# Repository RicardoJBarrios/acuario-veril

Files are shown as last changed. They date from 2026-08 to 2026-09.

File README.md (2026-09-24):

# Documentación de Veril

<div align="center" style="text-align: center; padding: 20px">
  <a href="06_Logo/README.md">
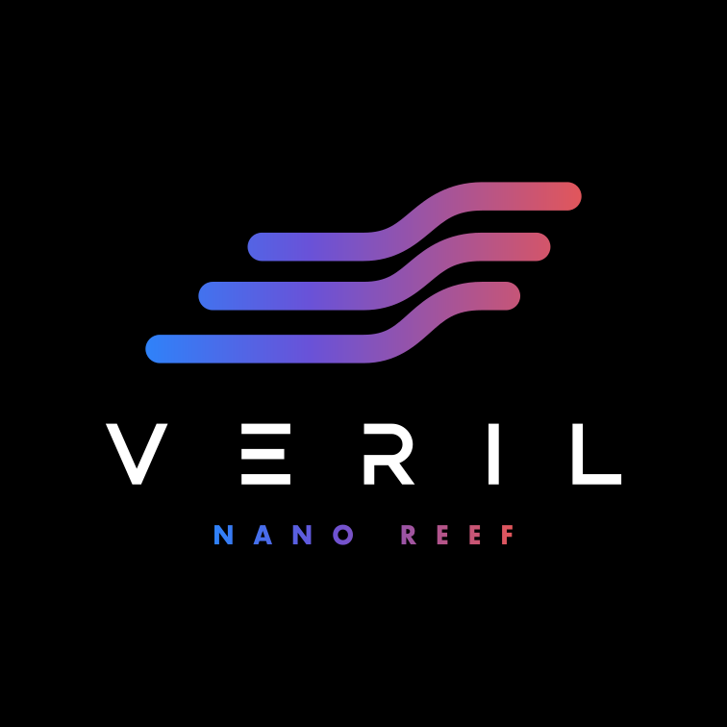
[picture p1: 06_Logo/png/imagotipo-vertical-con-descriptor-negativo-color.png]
Logotipo de Veril — Nano Reef
    
  </a>
</div>

Veril es un **nano reef de arrecife mixto de aproximadamente 75 litros**, pensado para mantener peces, corales e invertebrados en una urna AIO. Como referencia práctica, se estiman **unos 60 litros en el display** y **75 litros en el sistema completo**, incluido el compartimento técnico. Son cifras aproximadas para describir la escala del acuario, no mediciones exactas del volumen neto.

Esta documentación reúne, en un único lugar, lo que voy aprendiendo, las decisiones que tomo o me vienen impuestas y, sobre todo, los motivos que hay detrás de ellas. También recoge las actuaciones que realizo, sus consecuencias, las formas de cuidar y mantener el acuario, las dificultades que a menudo no se explican al principio y las distintas fases por las que irá pasando el sistema. En conjunto, pretende ser un registro de lo que necesito aprender para mantenerlo de forma responsable.

La hago pública por si la experiencia puede resultar útil a alguien y para poder ofrecer contexto cuando necesite pedir ayuda. Soy totalmente novato, así que lo que aparece aquí puede contener errores, interpretaciones incompletas o decisiones que no sean las más adecuadas. No pretendo ocultar los problemas ni presentar el proceso como más sencillo o más bonito de lo que es. Cualquier información interesante debería tomarse como punto de partida y contrastarse con fuentes fiables, documentación del fabricante y la situación real del acuario.

La inteligencia artificial se ha utilizado de forma extensa tanto para investigar y contrastar información como para redactar, organizar y revisar esta documentación. Todo el contenido ha pasado por una revisión editorial y de contenido humana por mi parte, y la responsabilidad de lo que se publica es mía. Esta revisión no garantiza que no haya errores, por lo que siguen siendo necesarios el criterio propio y el contraste con fuentes competentes.

Para que todo quede claramente diferenciado, la documentación separa el conocimiento general de referencia, la configuración vigente de Veril, las actuaciones que todavía están pendientes y las operaciones que ya se han ejecutado. Los prefijos numéricos orientan la lectura y cada apartado enlaza con la información más concreta cuando es necesario.

## Índice

- [Verilpedia](01_verilpedia/README.md): conocimiento general y reutilizable
- [Configuración](02_configuracion/README.md): estado vigente y decisiones de diseño de Veril
- [Pendientes](03_pendientes/README.md): actuaciones todavía no ejecutadas, incluidos ciclado, maduración y procedimientos recurrentes
- [Operaciones](04_operaciones/README.md): actuaciones ejecutadas, ordenadas por fecha y documentadas con sus resultados
- [Multimedia](05_multimedia/README.md): recursos visuales con su contexto y límites de interpretación

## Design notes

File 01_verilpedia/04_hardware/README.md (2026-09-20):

# Hardware de Veril

La urna a medida y las fichas de hardware utilizadas por Veril se documentan
en este repositorio como una recopilación personal de especificaciones,
observaciones y referencias. No es documentación oficial del fabricante ni
una validación técnica independiente. Las decisiones de selección, instalación
y aceptación pertenecen a `02_configuracion/`, a los planes y a las operaciones fechadas

## Urna

- [Urna de Veril](urna/README.md): fabricación, display y compartimento técnico

## Equipos principales

- [D-D H2Ocean Compact ATO](dd-h2ocean-compact-ato/dd-h2ocean-compact-ato.md)
- [Equipo de ósmosis inversa RO6CB](ro6cb/ro6cb.md): equipo RO con bomba de refuerzo, depósito y filtros
- [Sistema DI del RO/DI](di-ro/sistema-di.md): carcasas T33, monitor TDS, tubería y manómetro pedidos para completar el tratamiento
- [Resina DI recomendada](di-ro/resina-xepta-rodi.md): XEPTA RODI RESIN de 1000 ml, seleccionada como medio pendiente de compra o confirmación
- [Sicce Shark Skimmer 300](sicce-shark-skimmer-300/sicce-shark-skimmer-300.md)
- [Sicce Micra Plus 600](sicce-micra-plus-600/sicce-micra-plus-600.md)
- [Mantis Tourbon 60](mantis-tourbon-60/mantis-tourbon-60.md)
- [AI Prime 16HD Reef](ai-prime-16hd-reef/ai-prime-16hd-reef.md)

## Limpieza y mantenimiento manual

- [Cepillo de dientes de cerdas suaves](cepillo-dientes-cerdas-suaves/cepillo-dientes-cerdas-suaves.md)
- [Seachem Algae Scraper 31 cm](seachem-algae-scraper-31cm/seachem-algae-scraper-31cm.md)
- [TUNZE Care Magnet nano](tunze-care-magnet-nano/tunze-care-magnet-nano.md)
- [XGB-830](xgb-830/xgb-830.md)

## Sensores y monitorización

- [DanoPlus DP-414](danoplus-dp-414/danoplus-dp-414.md)
- [SONOFF S60ZBTPF](sonoff-s60zbtpf/sonoff-s60zbtpf.md)
- [SONOFF SNZB-02LD](sonoff-snzb-02ld/sonoff-snzb-02ld.md)
- [SONOFF SNZB-05P](sonoff-snzb-05p/sonoff-snzb-05p.md)
- [Excellux ZG-109TDS](zigbee-7-en-1-monitor-calidad-agua/excellux-zg-109tds.md)

## Integraciones

Las integraciones de Home Assistant y Zigbee2MQTT se encuentran junto a la ficha del equipo correspondiente. La compatibilidad y las entidades disponibles dependen del modelo y del soporte vigente de Zigbee2MQTT.

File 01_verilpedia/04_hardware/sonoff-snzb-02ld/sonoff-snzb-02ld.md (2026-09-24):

# SONOFF SNZB-02LD

## Identificación

- **Fabricante:** SONOFF
- **Modelo:** SNZB-02LD
- **Tipo:** Termómetro Zigbee con pantalla LCD y sonda externa
- **Protocolo:** Zigbee 3.0 / IEEE 802.15.4
- **Gateway previsto:** SONOFF ZBBridge-P

## Ficha normalizada

| Campo | Valor |
| --- | --- |
| `hardware_id` | `SONOFF_SNZB_02LD` |
| `category` | `aquarium_monitoring` |
| `vendor` | `SONOFF` |
| `model` | `SNZB-02LD` |
| `hardware_kind` | `physical` |
| `physical_type` | `zigbee_temperature_sensor_probe` |
| `protocol` | Zigbee 3.0 |
| `gateway` | SONOFF ZBBridge-P |
| `measurement` | Temperatura del agua |

## Función en Veril

El **SONOFF SNZB-02LD** se utiliza en Veril para el seguimiento telemétrico de la temperatura del agua mediante Zigbee y el gateway **SONOFF ZBBridge-P**. La sonda debe quedar en el agua y el cuerpo electrónico fuera de la zona húmeda. La ubicación concreta de la unidad y su estado operativo se documentan en las operaciones y en la configuración de Veril, no en esta ficha general.

La telemetría permite observar la evolución de la temperatura. Las tendencias y los avisos automáticos solo se utilizarán cuando la cadencia y la señal se hayan validado en el sistema; la automatización térmica de Veril continúa en revisión. La lectura tampoco sustituye la comprobación independiente del sensor.

## Especificaciones

| Campo | Dato |
| --- | --- |
| Fabricante | SONOFF |
| Modelo | SNZB-02LD |
| Tipo | Termómetro Zigbee con pantalla LCD y sonda externa |
| Comunicación | Zigbee 3.0 / IEEE 802.15.4 |
| Gateway previsto | SONOFF ZBBridge-P |
| Alimentación | 3 V, pila CR2477 |
| Pantalla | LCD de aproximadamente 5,6 cm |
| Dimensiones del cuerpo | 62,8 × 58,5 × 21,8 mm |
| Material del cuerpo | PC + ABS |
| Peso neto publicado | 86,2 g, con cables |
| Longitud de la sonda | 1,5 m |
| Tolerancia de temperatura declarada | ±0,5 °C |
| Protección del cuerpo | IP65 |
| Temperatura de funcionamiento del cuerpo | −10–60 °C según el PDF oficial V1.0 |
| Humedad de funcionamiento del cuerpo | 0–100 % HR según el PDF oficial V1.0 |
| Temperatura de funcionamiento de la sonda | −40–115 °C según el PDF oficial V1.0 |
| Altura máxima de instalación declarada | <2000 m |

## Instalación

- Fijar únicamente la sonda en una zona representativa del agua
- Mantener el cuerpo y la tapa de la pila fuera del acuario y protegidos de salpicaduras directas
- Evitar que la sonda quede contra un calentador, una bomba, la iluminación o una pared sometida a radiación directa
- Comprobar que la longitud de 1,5 m permite colocar el cuerpo en una zona seca sin tensar el cable
- Verificar la lectura frente a un termómetro independiente antes de usar avisos o automatizaciones

IP65 no significa que el cuerpo pueda sumergirse. La protección está pensada para salpicaduras y chorros de baja presión; no se expondrá el módulo a inmersión, condensación persistente ni chorros de agua salada.

## Datos disponibles en Zigbee2MQTT

Zigbee2MQTT expone para este modelo:

- Batería restante en porcentaje
- Temperatura de la sonda en °C
- Unidad mostrada en pantalla: `celsius` o `fahrenheit`
- Calibración de temperatura mediante una corrección entre −50 y +50 °C
- Actualización OTA

La calibración y la precisión configurable aparecen como opciones del dispositivo. La integración completa con Home Assistant está en [Home Assistant y Zigbee2MQTT](home-assistant-zigbee2mqtt.md).

El manual permite emparejar el sensor con un SONOFF ZBBridge-P. El alta se realiza desde eWeLink: se mantiene pulsado el botón durante cinco segundos, el indicador entra en modo de emparejamiento durante aproximadamente 180 segundos y se selecciona el gateway Zigbee.

El gateway, la cobertura real y la publicación de la temperatura se comprobarán en la ubicación definitiva. Una lectura disponible en la aplicación no demuestra por sí sola que la sonda esté bien colocada ni que su valor sea correcto.

## Limitaciones

- El dispositivo mide temperatura; no mide salinidad, pH, alcalinidad, nutrientes ni nivel de agua
- La tolerancia declarada no sustituye una comparación con un instrumento independiente
- El cuerpo IP65 no debe sumergirse
- La pila CR2477 y la disponibilidad Zigbee deben vigilarse como parte del mantenimiento

## Fuentes

- [Manual local del SNZB-02LD, versión 1.0 en inglés](sonoff-snzb-02ld-manual-en-v1-0.pdf)
- [Página oficial del SONOFF SNZB-02LD](https://sonoff.tech/en-eu/products/sonoff-snzb-02ld-ip65-zigbee-lcd-smart-thermometer-probe-version)
- [Manual oficial del SNZB-02LD](https://support.sonoff.tech/snzb-02ld-usermanual/)
- [Descarga directa del PDF oficial](https://cdn.shopify.com/s/files/1/0742/9963/8001/files/User_Manual_SNZB-02LD_EN_V1.0.pdf?v=1749029821)

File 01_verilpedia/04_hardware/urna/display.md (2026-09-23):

# Display de la urna

## Dimensiones y función

El display ocupa la zona izquierda de la urna. Su medida interior observada en planta es de **594 × 308 mm** y la altura exterior de la urna es de **400 mm**. Es el espacio destinado al aquascape, el sustrato y los habitantes. El compartimento técnico derecho concentra el equipo auxiliar.

La disposición longitudinal permite desarrollar el aquascape desde la zona técnica hacia el extremo libre del acuario, manteniendo una lectura principal desde el puesto de trabajo.

## Volumen operativo estimado del display

Como referencia de diseño, con 2 cm de arena y 2 cm de margen libre, la columna de agua sería de 350 mm sobre una base interior de 594 × 308 mm: **64,03 L brutos** antes de descontar la roca. La operación del 23 de septiembre de 2026 permite inferir un desplazamiento de roca de **aproximadamente 2,339 L**, usando el descenso confirmado de 12 mm tanto en display como en Entrada. El cálculo da **aproximadamente 61,69 L** para el display en ese escenario, que se redondea a **unos 60 L** como referencia práctica para dosificaciones aproximadas. No es una medición directa de litros ni el volumen total del sistema; el detalle y sus límites constan en la [operación de pesaje y desplazamiento](../../../04_operaciones/2026/09/2026-09-23-pesaje-y-desplazamiento-del-hardscape.md).

Este dato corresponde solo al display. La convención nominal vigente de Veril es **60 L para el display** y **75 L para el sistema completo**, incluidas las cámaras Entrada, Skimmer y Retorno. Se usarán como valores por defecto para simplificar cálculos y dosificaciones; son aproximaciones adoptadas, no mediciones exactas.

## Organización

- Mantener el display como zona biológica y visible
- Situar la AI Prime 16HD Reef ligeramente desplazada hacia la derecha para obtener la mejor cobertura posible del hardscape dentro de los **594 mm** útiles
- Dejar espacio alrededor y detrás de la roca para la circulación
- Mantener despejados el peine, el rebosadero y los accesos de mantenimiento
- Conservar pasos para retirar detrito y limpiar los cristales
- Evitar apoyar equipo auxiliar sobre el sustrato o la roca

La composición de la roca, el sustrato, los espacios negativos y las rutas hidráulicas se desarrolla en la [implementación de Veril](../../../02_configuracion/README.md), con sus fichas [espacial](../../../02_configuracion/01_dimensiones/02_espacial.md), [hidráulica](../../../02_configuracion/01_dimensiones/03_hidraulica.md) y [biología](../../../02_configuracion/03_biologia/README.md).

## Circulación y mantenimiento

El flujo debe alcanzar las zonas inferiores, los refugios y la parte posterior de la estructura sin levantar el sustrato ni crear áreas de acumulación. La roca y los habitantes deben permitir la limpieza del cristal, el acceso al peine y la retirada manual del detrito.

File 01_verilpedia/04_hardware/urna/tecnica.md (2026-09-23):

# Técnica de la urna

## Configuración AIO

El compartimento técnico lateral recibe el agua del display, aloja el equipo y devuelve el agua mediante una bomba de retorno. Está integrado en la urna y no es un sump inferior externo.

No se instalará filtración mecánica. El uso de un medio biológico adicional se decidirá en la documentación de biología y ciclado.

## Recorrido hidráulico

La zona técnica tiene tres cámaras interiores. La cámara **Entrada** queda documentada con unas dimensiones nominales de **139 × 86 × 390 mm** (ancho × fondo × altura interior). Las otras dos cámaras se expresan aquí en planta como **Skimmer** (**139 × 134 mm**) y **Retorno** (**139 × 77 mm**):

```text
Display
→ Entrada: Entrada circular y paso a la zona técnica
→ Paso inferior de aproximadamente 50 mm a Skimmer
→ Skimmer: Skimmer y calentador
→ Paso superior de aproximadamente 50 mm a Retorno
→ Retorno: Bomba, ATO y sensores
→ Retorno al display
```

La cámara **Entrada** concentra la entrada y el acceso a la rejilla. Su altura interior nominal es de **390 mm**, calculada como **400 mm de altura exterior menos 10 mm del fondo**; los **340 mm** de los separadores internos no son la altura de esta cámara, sino la altura de una pieza que deja un paso inferior aproximado de 50 mm hacia Skimmer. La entrada a esta cámara se realiza mediante una perforación de **50 mm de diámetro**, situada a **17 mm del borde superior** y a **30 mm de la pared trasera**. La cámara **Skimmer** aloja el skimmer y el calentador. En la observación del 23 de septiembre de 2026, su nivel quedó 50 mm por debajo del borde, frente a 37 mm en display/Entrada; esa cota describe la observación y no se adopta aquí como nivel universal para todos los regímenes. La cámara **Retorno** mantiene la bomba de retorno, el sensor del ATO y los sensores de temperatura.

## Equipo técnico

- [Sicce Shark SKIMMER 300](../sicce-shark-skimmer-300/sicce-shark-skimmer-300.md): Skimmer de la cámara Skimmer
- [Sicce Micra Plus 600](../sicce-micra-plus-600/sicce-micra-plus-600.md): Bomba de retorno
- [Mantis Tourbon 60](../mantis-tourbon-60/mantis-tourbon-60.md): Bomba de movimiento del display
- [D-D H2Ocean Compact ATO](../dd-h2ocean-compact-ato/dd-h2ocean-compact-ato.md): Reposición automática de la cámara Retorno
- [Barril GRAF de 15 l](../dd-h2ocean-compact-ato/graf-barril-agroalimentario-15l.md): Depósito de agua RO/DI para el ATO

El compartimento conserva acceso para retirar y mantener el skimmer, el calentador, las bombas, el sensor del ATO, los sensores de temperatura y la rejilla de entrada.

## Niveles de agua

- Nivel mínimo de Retorno: Límite inferior para evitar que la bomba aspire aire
- Nivel operativo: Altura normal con el ATO y el equipo funcionando
- Nivel máximo seguro: Altura compatible con el agua que retorna durante un corte eléctrico

El ATO repone únicamente agua **RO/DI** en la cámara Retorno. El sistema debe quedar dispuesto para evitar el sifonado y permitir la limpieza del sensor.

## Comprobaciones de montaje

- Paso de agua entre display y zona técnica sin desbordamientos
- Nivel estable en la cámara del skimmer
- Acceso de mantenimiento en las tres cámaras
- Funcionamiento silencioso del rebosadero superior
- Circulación sin microburbujas persistentes hacia el display
- Margen de agua suficiente en la cámara Retorno
- Comportamiento del sistema durante el llenado, la circulación y un corte eléctrico

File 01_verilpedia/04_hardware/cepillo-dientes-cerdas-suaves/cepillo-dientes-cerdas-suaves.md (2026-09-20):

# Cepillo de dientes de cerdas suaves

## Identificación

| Campo | Dato |
| --- | --- |
| Tipo | Cepillo manual de cerdas suaves |
| Marca, modelo y material | No identificados |
| Estado de la ficha | Identidad comercial pendiente de confirmar |

## Alcance

Esta entrada conserva la existencia de un útil de limpieza identificado solo
por su tipo. Sin fabricante, modelo, material ni evidencia de compatibilidad,
no se le atribuyen seguridad química, resistencia al agua salada ni un uso
concreto dentro de Veril.

La eventual utilización, el contacto con agua o roca y el resultado de una
limpieza pertenecen a una operación fechada, no a esta ficha general.

## Pendientes

- Confirmar fabricante, modelo y materiales si se conservan envase o etiqueta.
- Registrar el uso concreto y las condiciones de limpieza antes de emplearlo en Veril.

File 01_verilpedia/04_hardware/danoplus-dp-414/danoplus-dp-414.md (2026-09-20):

# DanoPlus DP-414

## Identificación y función en Veril

El **DanoPlus DP-414** es el sensor previsto para medir el PPFD bajo el agua y construir el mapa de exposición lumínica de Veril. No forma parte del régimen de iluminación ni determina por sí mismo qué organismos son compatibles con una zona.

La unidad de medida principal será el PPFD registrado en µmol fotones m⁻² s⁻¹ dentro del intervalo PAR. Los valores se relacionarán con la posición, profundidad, espectro, fotoperiodo y estado de la luminaria.

## Estado de la decisión

**Adquirido:** El usuario confirma disponer del DanoPlus DP-414. Se utilizará como instrumento propio para el mapa de PPFD de Veril, una vez comprobado que la unidad corresponde al modelo documentado y el sensor no presenta daños.

**Previsto:** El sensor se empleará sumergido, unido a la varilla telescópica, con una orientación y un protocolo de posición constantes.

**Pendiente:** Deben registrarse la unidad recibida, el número de serie o lote, la revisión identificable, el estado del sensor y, si resulta posible, una comparación puntual con un medidor subacuático de referencia.

## Especificaciones documentadas

| Campo | Valor documentado |
| --- | --- |
| Fabricante | DanoPlus |
| Modelo comercial | DP-414 |
| Identificación alternativa documentada | KIB0414 en el manual consultado |
| Tipo | Medidor cuántico de PPFD para medición subacuática |
| Sensor | Sensor cuántico declarado IP68 |
| Intervalo espectral declarado | 400–700 nm ±10 nm |
| Rango de medición declarado | 0–4000 µmol fotones m⁻² s⁻¹ |
| Resolución indicada | 0,1 hasta 999 y 1 por encima de 1000, según la documentación consultada |
| Registro interno | Hasta 100 valores |
| Cable | Aproximadamente 79 pulgadas, según el fabricante |
| Varilla | Telescópica sólida de aproximadamente 37 pulgadas, según el fabricante |
| Alimentación | 2 pilas AAA en el manual oficial en español; algunas copias secundarias indican 3 |
| Unidad principal | No sumergible |

Las especificaciones anteriores son declaraciones del fabricante o de su manual. No equivalen a una validación independiente de exactitud, linealidad, respuesta espectral o repetibilidad de la unidad de Veril.

El manual oficial en español se conserva en [DanoPlus DP-414: manual de uso](danoplus-dp-414-manual-es.pdf). La página del fabricante también identifica el equipo como **414_E**, mientras que otras copias del manual utilizan **KIB0414** o **CD50**. Al recibir la unidad se registrará la identificación impresa en el producto y se conservarán esas variantes como referencias del mismo conjunto documental, sin asumir que todas las revisiones sean idénticas.

## Funciones del manual

El manual documenta las siguientes operaciones:

- Medición en tiempo real
- Retención de la lectura mediante `HOLD`
- Registro manual de hasta 100 valores
- Consulta y borrado de los registros almacenados
- Calibración del punto cero cubriendo completamente el sensor
- Restablecimiento de fábrica
- Apagado automático tras aproximadamente tres minutos sin operación
- Ajuste de la inclinación del sensor hasta aproximadamente 180°

La calibración descrita es una calibración del cero en oscuridad. No es una calibración de exactitud frente a una fuente patrón ni proporciona por sí sola un factor de corrección para mediciones subacuáticas.

## Limitaciones de medición

El sensor no se considerará una referencia metrológica absoluta sin una comparación documentada con un medidor subacuático de referencia. Las comparativas disponibles de medidores económicos muestran factores de corrección variables según la unidad, la revisión del sensor, el espectro y la posición.

No se aplicará automáticamente un multiplicador publicado para otra unidad. Si se dispone de una comparación con un Apogee MQ-510 u otro instrumento de referencia, el factor obtenido se registrará junto al número de unidad, las condiciones y el espectro utilizado. Hasta entonces, los valores podrán utilizarse como referencia espacial y comparativa interna, pero no como cifras absolutas con precisión de laboratorio.

La orientación del sensor debe permanecer constante. Una inclinación distinta, una sombra de la varilla, burbujas, suciedad o una posición diferente sobre una superficie rugosa pueden alterar la lectura. El sensor no se dejará instalado permanentemente en el acuario.

## Reseñas y pruebas independientes

La evidencia independiente disponible es limitada y no constituye una certificación de exactitud. Las experiencias siguientes se conservarán como observaciones de usuarios o pruebas concretas, no como valores universales para todas las unidades:

- Serious Reefs comparó el DP-414 y el VBR-Aqua con un Apogee MQ-510 y resumió que ambos podían utilizarse como opciones económicas después de aplicar una corrección aproximada, aunque prefirió el DanoPlus y señaló dificultades en el violeta y el índigo
- En Reef2Reef, usuarios que compararon unidades DanoPlus con Apogee comunicaron factores de aproximadamente 1,2–1,3 en algunas unidades
- En el mismo debate se afirmó que algunas cajas recientes identificadas con un punto verde se acercaban a Apogee sin corrección, pero otro usuario con una unidad equivalente siguió observando la necesidad de un factor de 1,2–1,3
- Una prueba publicada en Reddit comparó aproximadamente 230 PPFD del DanoPlus con 355 PPFD del Apogee en el mismo punto, lo que muestra que una unidad concreta puede presentar un sesgo importante
- Las experiencias generales de usuarios valoran el precio, la varilla y la utilidad para evitar ajustar la luz a ciegas, pero no permiten establecer una exactitud común a todas las revisiones

Estas diferencias no demuestran necesariamente que el instrumento sea inútil. Sí demuestran que la cifra mostrada no debe tratarse como intercambiable con la de un Apogee sin validar la unidad concreta.

## Puntos débiles conocidos

### Exactitud y corrección no universal

El fabricante publica una repetibilidad de ±1 µmol fotones m⁻² s⁻¹, pero la repetibilidad declarada no equivale a exactitud frente a un patrón. Las comparativas independientes muestran factores distintos según la unidad, el sensor, el espectro y la posición.

No se utilizará un factor genérico como 1,25×, 1,35× o 1,7× sin justificarlo con una comparación de la unidad concreta. Para Veril, la prioridad será que el mapa sea repetible; si se obtiene una referencia externa, el factor se registrará con sus condiciones y no se extrapolará automáticamente a otra unidad.

### Respuesta espectral limitada

El intervalo declarado es 400–700 nm con una tolerancia de aproximadamente ±10 nm. Esto permite medir PPFD dentro del intervalo PAR convencional, pero no convierte el equipo en un espectrómetro ni describe la distribución espectral de la AI Prime 16HD Reef.

La respuesta en el extremo violeta, especialmente cerca de 400–420 nm, puede ser una fuente de diferencia frente a otros sensores. No se interpretará el valor de PPFD como una medida de PUR ni como una descripción de qué bandas utiliza un organismo.

### Orientación y geometría

El sensor puede inclinarse para adaptarse a la posición de medida, pero esa articulación introduce una variable que debe fijarse. La orientación, la sombra de la varilla, el reflejo del cristal, las burbujas y la rugosidad de la superficie pueden modificar la lectura.

El mapa de Veril utilizará una orientación definida y repetible. Si una zona exige medir sobre una superficie inclinada, se registrará esa condición en lugar de comparar el valor directamente con una superficie horizontal sin contexto.

### Memoria y registro manual

La memoria de 100 lecturas no conserva por sí sola coordenadas, profundidad, hora, programación de la luminaria ni condiciones hidráulicas. La memoria se utilizará como apoyo, pero el mapa definitivo se registrará fuera del instrumento con la plantilla de medición de Veril.

El apagado automático tras aproximadamente tres minutos puede interrumpir una sesión lenta. Se comprobará el estado del instrumento durante el muestreo y se evitará interpretar una lectura perdida como un cambio lumínico.

### Protección y mantenimiento

El IP68 se declara para el sensor, no para la unidad principal, el cable completo ni el conector. El manual no establece en la ficha consultada una profundidad máxima ni una duración máxima de inmersión. Por ello, el sensor se utilizará durante la medición, se enjuagará después y no se dejará instalado permanentemente.

La superficie óptica es sensible a suciedad y arañazos. Un sensor contaminado, un conector con humedad o un cable deteriorado pueden producir lecturas inestables y no deben resolverse aplicando un factor de corrección.

### Documentación del fabricante

El manual oficial es breve y no aporta un certificado de calibración individual, una curva de respuesta espectral detallada, incertidumbre expandida, profundidad máxima de ensayo ni resultados de comparación frente a un estándar subacuático. La declaración de repetibilidad debe conservarse como especificación del fabricante, no como prueba independiente de exactitud.

## Uso previsto en el mapa de Veril

El mapa se realizará con la AI Prime 16HD Reef en la configuración que se quiera documentar y con la geometría operativa del aquascape instalada. Cada punto deberá conservar:

- Fecha y hora
- Altura de la luminaria sobre el agua
- Estado de los canales y programación activa
- Profundidad y posición horizontal del sensor
- Orientación del sensor y método de sujeción
- Estado de la superficie del agua y de la circulación
- Valor mostrado por el DP-414
- Factor de corrección utilizado, si existe
- Relación del punto con roca, sustrato, islas, terrazas, sombras o espacios previstos

El mapa se utilizará para clasificar zonas de exposición y relacionarlas con las necesidades documentadas de los organismos. No se asignarán corales únicamente por el valor de un punto ni se interpretará el mapa como una medición del espectro completo.

## Procedimiento de aceptación

1. Comprobar que el modelo y el sensor recibidos corresponden al DP-414 documentado
2. Revisar carcasa, cable, conector, sensor, varilla y compartimento de pilas
3. Confirmar que la unidad principal permanece fuera del agua
4. Encender el instrumento y verificar que la lectura responde a cambios de iluminación
5. Colocar el sensor plano o en la orientación definida para el protocolo
6. Comprobar que la varilla no proyecta sombra sobre el sensor ni modifica su posición
7. Realizar lecturas repetidas en un punto de control para evaluar la repetibilidad local
8. Registrar la medición de referencia, si se dispone de otro instrumento
9. Documentar cualquier factor de corrección antes de construir el mapa definitivo
10. Guardar el mapa junto con la configuración de la luminaria y la geometría del aquascape

El DP-414 se considerará adecuado para el mapa cuando produzca lecturas repetibles bajo la misma configuración, pueda colocarse en las zonas relevantes y sus limitaciones estén registradas. La exactitud absoluta no se dará por demostrada solo por la resolución mostrada o por la declaración IP68.

## Mantenimiento y seguridad

Después de cada sesión se enjuagará el sensor con agua dulce adecuada, se inspeccionará el cable y se dejará secar antes de guardarlo. No se sumergirá la unidad principal ni se utilizará el instrumento si el cable, el conector o la carcasa del sensor presentan daños.

La varilla se manejará sin golpear el cristal, la roca, el sustrato ni los corales. Las mediciones se realizarán con la alimentación y los equipos en la configuración definida para el mapa; cualquier parada de bombas o cambio temporal deberá registrarse porque modifica las condiciones de exposición y la estabilidad del sensor.

## Fuentes

- [DanoPlus: DP-414](https://www.danoplus.com/products/dp-414/)
- [DanoPlus: categoría de medidores de luz](https://www.danoplus.com/category/light-lux-meters/)
- [DanoPlus: manuales y software del modelo 414](https://www.cd50.net/414/)
- [Manual local en español del DP-414](danoplus-dp-414-manual-es.pdf)
- [Manual del DanoPlus KIB0414](https://manuals.plus/asin/B0D3LVT1MR)
- [Comparativa de DanoPlus, VBR-Aqua y Apogee publicada por Serious Reefs](https://www.patreon.com/SeriousReefs/posts/mq510-575-par-vs-151737140)
- [Comparativa de usuarios entre DanoPlus y Apogee](https://www.reef2reef.com/threads/vbr-aqua-par-meter-for-aquarium-r-g-b-par-seperately/page-5)
- [Prueba comparativa de DanoPlus y Apogee en ReefTank](https://www.reddit.com/r/ReefTank/comments/1p2v9of/would_this_par_meter_do_the_job_thoughts/)

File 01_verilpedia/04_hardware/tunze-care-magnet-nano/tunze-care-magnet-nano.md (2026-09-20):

# TUNZE Care Magnet nano

## Identificación declarada

| Campo | Dato |
| --- | --- |
| Marca | TUNZE |
| Producto | Care Magnet nano |
| Referencia | 0220.010 |
| Tipo | Limpiacristales magnético |

## Especificaciones declaradas

TUNZE declara la variante nano para cristal de **6 a 10 mm**, con **45 mm** de
ancho y **78 mm** de longitud. Incluye una cuchilla plástica de recambio de
45 mm y tapas de colores. El fabricante indica que las superficies de contacto
y el cristal deben estar libres de arena o polvo antes de cada uso; las
partículas adheridas pueden rayar el cristal.

La compatibilidad dimensional con una urna concreta y el comportamiento de la
unidad disponible en Veril no quedan demostrados por esta ficha.

## Fuentes

- [TUNZE: Care Magnet nano 0220.010](https://tunze.com/Care-Magnet-nano/0220.010)

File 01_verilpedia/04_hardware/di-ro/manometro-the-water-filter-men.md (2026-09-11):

# Manómetro The Water Filter Men

## Identificación declarada

| Campo | Valor documentado |
| --- | --- |
| Marca | The Water Filter Men |
| Tipo | Indicador de presión para sistemas RO y filtros de agua |
| Conexión roscada declarada | 1/4 NPT |
| Conexión hidráulica anunciada | Racor para tubo de 1/4 pulgadas |
| Material declarado | Acero inoxidable |
| Peso declarado | 60 g |
| Cantidad | Una unidad |
| ASIN | B00BZTFI5M |

La página del fabricante/comercializador confirma que el conjunto está destinado a comprobar la presión de entrada o la presión de un sistema de ósmosis inversa y que incluye los accesorios para tubo de 1/4 pulgadas. La escala y la precisión del ejemplar concreto no se han confirmado en una ficha técnica independiente.

## Aplicación prevista

Se prevé utilizarlo para observar la presión en la alimentación del RO o en el tramo que se defina durante el montaje. La ubicación final no queda fijada por la ficha del producto: debe permitir una lectura representativa, evitar esfuerzos sobre el tubo y no introducir una restricción no prevista.

La escala, el rango útil, la precisión y la estanqueidad de la combinación de manómetro y racor se comprobarán físicamente. Una lectura del manómetro no sustituye la verificación del límite de presión indicado para el RO6CB.

## Fuente

- [Manómetro The Water Filter Men en Amazon](https://www.amazon.es/dp/B00BZTFI5M)
- [Ficha del manómetro con accesorios en The Water Filter Men](https://thewaterfiltermen.co.uk/products/reverse-osmosis-pressure-gauge-with-fittings)

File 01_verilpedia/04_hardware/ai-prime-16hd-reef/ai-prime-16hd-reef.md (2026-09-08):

# AI Prime™ 16HD Reef

## Descripción

La **AI Prime™ 16HD Reef** será la luminaria principal del display de Veril. Es una luminaria LED compacta para arrecife, con control inalámbrico, siete grupos de color regulables y un canal lunar independiente. Su formato concentra los emisores en una zona circular central y utiliza lentes TIR con una salida difusa para mezclar los colores antes de que la luz llegue al acuario.

La Prime combina una banda azul-violeta dominante con aportes más pequeños de blanco, verde, amarillo, naranja y rojo. Esta combinación permite trabajar con una apariencia azul de arrecife, conservar una parte amplia del espectro visible y ajustar el aspecto final mediante la aplicación. El sistema HD redistribuye la potencia disponible entre los canales utilizados, de modo que el porcentaje mostrado por la aplicación sirve para programar la luz, pero no equivale directamente a vatios, lúmenes o PAR.

## Ficha técnica

| Campo | Dato |
| --- | --- |
| Producto | AI Prime™ 16HD Reef |
| Fabricante | AquaIllumination® |
| Dimensiones | 12,4 × 12,4 × 3,4 cm |
| Peso | 0,43 kg |
| Consumo publicado | 55 W en la descripción y 59 W a plena potencia en la tabla técnica |
| Alimentación | 100–240 V CA, 50–60 Hz |
| Longitud del cable | 6,1 m |
| Óptica | Lentes TIR, con eficiencia óptica superior al 90 % según AquaIllumination |
| Control | Mobius, myAI y Neptune Fusion mediante Apex y módulo MXM |
| Protección declarada de la fuente | UL, CE y RoHS |

La luminaria incorpora **cuatro LED Cool White, cuatro Blue, cuatro Royal Blue, un Photo Red, un Green, un Violet, un UV y un Moonlight**. El número de emisores no indica por sí solo la proporción de luz de cada color: la corriente, la eficiencia, el control térmico y la redistribución HD determinan la salida real.

## Distribución física y espectro

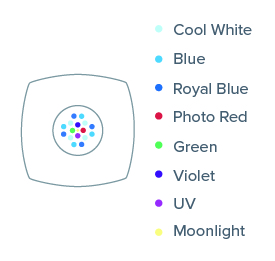
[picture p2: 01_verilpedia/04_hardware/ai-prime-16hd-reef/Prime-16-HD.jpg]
Distribución física de los LED de la AI Prime 16HD


*Distribución física publicada por AquaIllumination.*

Los emisores están intercalados en un conjunto circular compacto. Los blancos aportan una base visible más amplia; los azules y royal blue forman la parte dominante del aspecto de arrecife; violeta y UV extienden la salida hacia longitudes de onda cortas; verde y rojo completan la mezcla visible; y el Moonlight funciona como canal lunar independiente. La proximidad de los emisores, las lentes TIR y la superficie de salida difusa favorecen que los colores lleguen mezclados a la zona iluminada.

La distribución compacta también concentra el máximo de luz en el eje central cuando la luminaria está baja. Subirla abre la huella y suaviza la diferencia entre centro y bordes, aunque reduce el PAR máximo y puede aumentar la luz que sale de la zona útil. La posición de un LED en el dibujo no permite calcular su potencia ni el PAR que llegará a un coral.

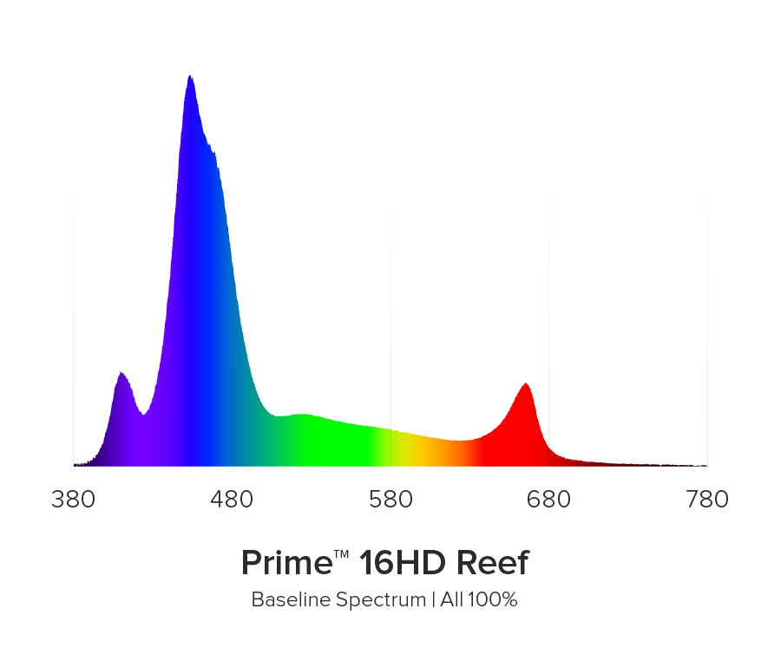
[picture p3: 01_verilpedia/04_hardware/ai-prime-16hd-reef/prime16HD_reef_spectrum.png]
Mapa de espectro base de la AI Prime 16HD Reef al 100 %


*Espectro base al 100 % publicado por AquaIllumination.*

El mapa cubre aproximadamente de 380 a 780 nm y muestra una salida principalmente azul-violeta. Se aprecia una contribución corta alrededor de 400–410 nm, un máximo principal en torno a 440–450 nm, una cola azul amplia hasta aproximadamente 490 nm, una contribución menor y extendida entre 500 y 630 nm y un pico rojo alrededor de 660 nm. El eje vertical no está graduado: representa intensidad relativa en el gráfico, no irradiancia absoluta, potencia óptica ni PAR.

La forma del gráfico explica el aspecto azul de la luminaria y su capacidad para resaltar fluorescencia, pero no determina por sí sola la intensidad adecuada para un coral ni la uniformidad sobre el acuario. Esas condiciones dependen de la programación, la altura, la profundidad, la orientación, la roca y la óptica.

## Control espectral

Mobius y myAI permiten construir una programación con puntos de control independientes, rampas de amanecer y anochecer, intensidad general, preajustes y escenas temporales. Los canales pueden cambiar durante el día y la intensidad general puede modificar toda la programación sin alterar necesariamente la relación entre colores.

El funcionamiento HD permite tomar capacidad de los canales reducidos y transferirla a los canales que se están utilizando. Por eso un 100 % es un nivel de control y no una unidad de potencia universal; del mismo modo, un valor superior al 100 % en un canal no significa que ese canal consuma ese porcentaje de la potencia total. Cambiar un canal altera el color y puede alterar también el PAR total.

La aplicación ofrece preajustes Signature Series, aclimatación, efecto lunar, Feed Mode, Live Demo, Lights On y Schedule. Feed Mode permite crear una escena temporal con espectro y duración propios; Live Demo sirve para probar canales; Lights On lleva la luminaria al 100 % y Schedule devuelve el horario normal. La aclimatación reduce la intensidad inicial y la aumenta durante el periodo elegido. El ejemplo de 50 % durante 30 días es una referencia de la aplicación, no el ajuste establecido para Veril.

El efecto lunar actúa sobre los puntos del canal Moonlight siguiendo la fase lunar y reduce la intensidad fuera de la luna llena. Se mantendrá desactivado al principio. Si se utiliza, se comprobarán sus horas y su efecto sobre el fotoperiodo.

## Aplicación, conexión y mantenimiento

La puesta en marcha se realiza desde un teléfono o tableta mediante Bluetooth Low Energy. En el alta pueden ser necesarios Bluetooth, ubicación y permisos de Bluetooth para myAI. La Prime debe estar encendida y dentro del alcance; si no aparece, conviene desconectar temporalmente otros dispositivos Bluetooth. En Android, la guía de soporte incluye borrar la caché del sistema Bluetooth y reiniciar el dispositivo. Las funciones descritas para myAI se comprobarán en Mobius si la unidad se entrega con esa plataforma.

La aplicación permite guardar y recuperar horarios, importar preajustes y verificar los ajustes desde `Settings > Troubleshooting > Verify Settings`. También permite volver a sincronizar la hora desde `Settings > Time > Set to Current Time` y regresar a `Schedule`. La Prime se controlará desde la aplicación, mientras que Home Assistant solo supervisará y cortará la alimentación mediante el SONOFF.

Las actualizaciones de firmware se hacen con la luminaria encendida y pueden tardar 15 minutos o más. Durante ellas no se debe cerrar la aplicación ni cortar la alimentación. En una Prime 16HD nueva, el indicador rojo y blanco intermitente señala que hay una actualización pendiente. El botón de restablecimiento está en la parte inferior: con la alimentación desconectada se mantiene pulsado mientras se vuelve a conectar hasta que parpadea en rojo; el parpadeo azul y verde confirma el restablecimiento.

La rejilla del ventilador debe mantenerse limpia. `Fan Shutdown` puede dejar el ventilador funcionando solo cuando lo necesita para mantener la temperatura o hacerlo funcionar continuamente. El estado utilizado se registrará junto con el ruido y la temperatura. La lente de repuesto identificada por AquaIllumination es la **119-00001**; su marca debe quedar hacia el lado del botón y todas las lentes deben quedar completamente asentadas y alineadas después de cualquier sustitución.

## Cobertura y PAR

AquaIllumination anuncia una extensión de **61 × 61 cm** y un pico de **100 µmol·m⁻²·s⁻¹ a 61 cm de profundidad**. En las pruebas de cobertura de una superficie de 61 × 61 cm, una Prime situada a 15,2 cm sobre el agua produjo una media de 107 PAR, con 462 PAR en el centro y 21 PAR en el borde. A 25,4 cm, el centro bajó a 232 PAR y el borde subió a 47 PAR. A 33,0 cm, la media fue de 94 PAR, con 156 PAR en el centro y 63 PAR en el borde.

La misma serie de pruebas encontró que una Prime a 20,3 cm cubría un cubo de 30,5 cm para LPS con el 94 % de los puntos entre 75 y 150 PAR. En un cubo de 45,7 cm, una Prime a 25,4 cm dejó el 83 % de 75 puntos en ese intervalo para LPS, pero no alcanzó el objetivo de SPS para el 70 % del área. En una superficie de 61 cm, una Prime a 33,0 cm situó el 70 % de 108 puntos en el intervalo de LPS y tejidos blandos.

Como referencias de diseño, dos Primes sobre un acuario de 91,4 cm produjeron el 81 % de 150 puntos entre 75 y 150 PAR para LPS, mientras que tres unidades produjeron el 73 % de los puntos entre 200 y 350 PAR para SPS. En un acuario de 121,9 × 61 cm, tres Primes alcanzaron el 92 % de 198 puntos en el intervalo LPS; ocho unidades, distribuidas en dos filas, alcanzaron el 78 % del área en el intervalo SPS. Estos resultados muestran que la cobertura depende tanto de la altura y el espaciamiento como de la potencia.

El display de Veril mide aproximadamente **60 × 32 × 40 cm**. El hardscape se desplazará hacia la derecha, por lo que la Prime quedará ligeramente desplazada hacia la derecha y se colocará en la posición que proporcione la mejor cobertura posible del hardscape, sin tomar como referencia obligatoria el centro geométrico de la urna. El extremo izquierdo y las zonas sombreadas recibirán una comprobación específica. La altura real provisional será de **250 mm entre la cara inferior de la luminaria y el agua**, hasta completar la comprobación de PAR y distribución.

La altura se comprobará físicamente después de instalar el kit, el cable y el shade, y se registrará junto con el mapa de PAR y la distribución observada. BRS utilizó 25,4 cm en una superficie de 45,7 cm y encontró una distribución más abierta que a menor altura; su referencia de 33,0 cm para una superficie de 61 × 61 cm sirve únicamente como contexto de la prueba.

## Montaje en Veril

La luminaria se colgará con el kit de AI desde un mueble **BESTÅ de IKEA** de aproximadamente **20 cm de fondo**. El punto de suspensión estará a **70 cm sobre la mesa** y la cara inferior de la luminaria quedará a **250 mm sobre el agua como referencia de montaje**. El anclaje se colocará hacia la derecha para alinear la zona de mayor cobertura con el hardscape. La altura real se comprobará físicamente después de instalar el conjunto.

Se instalará un **shade fabricado mediante impresión 3D** en el frente de la luminaria para evitar el reflejo directo y el deslumbramiento del usuario. Los laterales y la parte trasera quedarán libres para conservar la ventilación, la dispersión lateral de la luz y el acceso al cableado y a los ajustes. El shade no deberá tocar el ventilador, la carcasa caliente, la rótula ni los cables, ni proyectar sombras sobre la zona iluminada.

Antes de dar por terminado el montaje se comprobarán la capacidad real del panel del BESTÅ, la fijación del anclaje, la nivelación a 250 mm, la alineación lateral, la estabilidad durante el mantenimiento y la ausencia de tensión en el cable de alimentación. La luminaria no es impermeable y el adaptador deberá mantenerse separado del agua.

## Integración y puesta en marcha

La alimentación se realizará mediante un [SONOFF S60ZBTPF](../sonoff-s60zbtpf/sonoff-iplug-s60zbtpf.md) independiente. Home Assistant y Zigbee2MQTT supervisarán la alimentación y el consumo; Mobius o myAI controlarán la intensidad, el espectro y el horario.

La instalación se aceptará después de:

1. Registrar la unidad, el adaptador, el cable, el número de serie y el kit recibido
2. Verificar el anclaje al BESTÅ y la capacidad de carga del panel
3. Colgar inicialmente la luminaria a 250 mm sobre el agua, alinearla con el hardscape desplazado hacia la derecha y registrar la altura instalada
4. Instalar el shade frontal dejando abiertos los laterales y la parte trasera
5. Configurar la aplicación, conceder los permisos necesarios y actualizar el firmware si se solicita
6. Registrar la programación inicial, el estado de Fan Shutdown y el consumo eléctrico
7. Comprobar temperatura, ventilador, ruido, salpicaduras, condensación y posibles reflejos
8. Medir PAR en la cumbre, las terrazas, las microislas, el sustrato, los bordes y las zonas sombreadas
9. Comprobar y registrar la altura real, y ajustar orientación, shade o intensidad a partir del mapa obtenido
10. Guardar la configuración aceptada y relacionarla con la ubicación de los organismos

## Fuentes

- [AquaIllumination: Prime 16HD Reef](https://www.aquaillumination.com/products/prime)
- [AquaIllumination: Distribución física de los LED](https://www.aquaillumination.com/wp-content/uploads/2019/10/Prime-16-HD.jpg)
- [AquaIllumination: Mapa de espectro](https://www.aquaillumination.com/wp-content/uploads/2019/10/prime16HD_reef_spectrum.png)
- [AquaIllumination: Manual de Prime 16](https://support.aquaillumination.com/hc/en-us/articles/4402388563479-Prime-16-Product-Manual)
- [AquaIllumination: Prime Hanging Kit](https://shop.aquaillumination.com/products/prime-hanging-kit)
- [AquaIllumination: Montaje del kit para colgar](https://support.aquaillumination.com/hc/en-us/articles/13231337537303-Prime-Hanging-Kit-Assembly)
- [AquaIllumination: FAQ de AI Light 16/32/64](https://support.aquaillumination.com/hc/en-us/sections/360008131313-AI-Light-16-32-64-FAQ)
- [AquaIllumination: Instalación de lentes de Prime 16HD](https://support.aquaillumination.com/hc/en-us/articles/40562411067927-AI-Lens-Prime-16HD-32HD-64HD-Installation)
- [AquaIllumination: Limpieza y ventilación](https://support.aquaillumination.com/hc/en-us/articles/1500004217901-Prime-Fan-Cleaning-Instructions)
- [AquaIllumination: Actualización del firmware](https://support.aquaillumination.com/hc/en-us/articles/360046798273-Updating-AI-Light-Firmware)
- [AquaIllumination: Conexión y diagnóstico](https://support.aquaillumination.com/hc/en-us/articles/360039936254-How-do-I-connect-to-my-new-16-32-64-HD)
- [AquaIllumination: Feed Mode](https://support.aquaillumination.com/hc/en-us/articles/360046558853-AI-Lights-Configuring-Feed-Mode)
- [AquaIllumination: Programación de una AI Light nueva](https://support.aquaillumination.com/hc/en-us/articles/360011977713-How-should-I-program-my-new-AI-Light)
- [Bulk Reef Supply: Prueba de la Prime HD](https://www.bulkreefsupply.com/content/post/brstv-investigates-aqua-illumination-prime-hd)
- [Bulk Reef Supply: Vídeo de prueba de la Prime 16](https://www.youtube.com/watch?v=QH2nsgrxoRI)
- [ReefCalcs: Tabla PAR de la AI Prime 16HD](https://reefcalcs.com/fixtures/ai-prime-16-hd/)
- [Bay Area Reefers: Mediciones con AI Prime 16HD](https://bareefers.org/forum/threads/frag-tank-sunlight-par-meter-usage.31140/)
- [Reef2Reef: Medición PAR de una AI Prime 16HD](https://www.reef2reef.com/threads/ai-prime-16hd-par.931206/)
- [Reef2Reef: Ajustes y mediciones de la Prime 16HD](https://www.reef2reef.com/threads/ai-prime-16hd-settings-review.1142488/)
- [Reef2Reef: Incidencias comunicadas sobre lentes](https://www.reef2reef.com/threads/2x-ai-prime-16hd-lenses-melting-on-both.1037948/)
- [Canal oficial de AquaIllumination](https://www.youtube.com/@AquaIlluminationUS)
- [Ficha del SONOFF S60ZBTPF](../sonoff-s60zbtpf/sonoff-iplug-s60zbtpf.md)

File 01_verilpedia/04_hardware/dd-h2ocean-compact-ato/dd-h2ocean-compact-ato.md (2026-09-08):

# D-D H2Ocean Compact ATO

- **Fabricante:** D-D The Aquarium Solution
- **Modelo:** H2Ocean Compact ATO
- **Tipo:** sistema automático de reposición de agua
- **Entorno:** acuarios de agua dulce o marina

## Ficha normalizada

| Campo | Valor |
| --- | --- |
| `hardware_id` | `DD_H2Ocean_Compact_ATO` |
| `category` | `aquarium` |
| `vendor` | `D-D The Aquarium Solution` |
| `model` | `H2Ocean Compact ATO` |
| `hardware_kind` | `physical` |
| `physical_type` | `automatic_top_off` |
| `sensor` | doble sensor óptico |
| `actuator` | bomba CC incluida |
| `connectivity` | ninguna |
| `software` | control embebido no actualizable por el usuario |
| `mounting` | soporte magnético |

## Componentes incluidos

Según el manual oficial, la caja contiene:

- Controlador Compact ATO con doble sensor óptico
- Adaptador de alimentación universal
- Soporte universal para el tubo, compatible con acuarios con o sin marco de hasta 12,7 mm
- Bomba de reposición CC sin escobillas
- Rompe-sifón, integrado en el tubo de reposición
- Tubo de 200 cm

El depósito de reposición no forma parte del ATO y se documenta por separado en [Barril agroalimentario GRAF de 15 l](graf-barril-agroalimentario-15l.md).

## Funcionamiento

El controlador detecta el descenso del nivel mediante dos sensores ópticos y activa la bomba del depósito de reposición. El diseño no contiene flotadores móviles en el sensor y añade una lógica de seguridad y una alarma visual.

En un acuario marino debe reponer agua dulce, preferiblemente RO/DI: la sal no se evapora.

## Especificaciones

| Parámetro | Valor declarado |
| --- | --- |
| Entrada de la fuente | 100–240 V CA, 50/60 Hz |
| Bomba | corriente continua |
| Caudal máximo | 280 L/h |
| Altura máxima de impulsión | 2,5 m |
| Grosor máximo de cristal | 12,5 mm |
| Tubo incluido | 2 m |
| Diámetro del tubo | 9 mm exterior; 6,5 mm interior |
| Tamaño de acuario recomendado | más de 50 L |
| Sensores | dos ópticos |
| Garantía limitada del manual | 1 año, con instalación y uso correctos |

El caudal máximo y la altura máxima de impulsión no se alcanzan simultáneamente. La altura, la longitud y el recorrido del tubo reducen el caudal real.

La bomba es una bomba de corriente continua sin escobillas, con una altura máxima declarada de 250 cm y un caudal máximo de 280 l/h. Esos valores son límites de la bomba y no un caudal garantizado en la instalación de Veril.

## Instalación confirmada para Veril

Veril utilizará el H2Ocean Compact ATO con un [Barril agroalimentario GRAF de 15 l](graf-barril-agroalimentario-15l.md) reservado para agua RO/DI.

### Altura de impulsión prevista

El depósito estará en el suelo y la urna se apoyará sobre una mesa con:

- Patas de 71 cm
- Tapa de 32 mm
- Urna de 40 cm de altura

La superficie de apoyo de la urna quedará aproximadamente a **74,2 cm sobre el suelo** y el borde superior de la urna aproximadamente a **114,2 cm**. La salida del tubo del ATO no tiene que situarse en el borde superior: debe quedar por encima del nivel máximo del agua del sump y sin sumergirse durante el funcionamiento normal.

Tomando como referencia conservadora una bomba situada cerca del fondo del barril y una salida próxima a la parte alta del compartimento técnico, la elevación vertical prevista será aproximadamente de **1,0–1,2 m**. La altura real dependerá de la posición final de la bomba, del nivel de salida y del recorrido del tubo.

La bomba declara una altura máxima de impulsión de **2,5 m**. Por tanto, la instalación prevista queda con un margen vertical aproximado de **1,3–1,5 m** frente a ese límite. No se aprecia un problema de altura para llevar el agua desde el barril colocado en el suelo hasta la cámara de retorno.

El tubo incluido mide 2 m. La ruta definitiva debe mantenerse dentro de esa longitud, evitando bucles innecesarios, estrangulamientos y curvas cerradas. La altura máxima declarada y el caudal máximo de 280 l/h no se alcanzan simultáneamente, por lo que el caudal real debe comprobarse una vez instalado.

**Conclusión de compatibilidad:** la subida desde el barril situado en el suelo hasta la cámara de retorno es compatible con la capacidad declarada del H2Ocean Compact ATO. La elevación estimada de 1,0–1,2 m queda claramente por debajo de los 2,5 m máximos de la bomba y el recorrido previsto cabe, en principio, dentro de los 2 m de tubo incluido.

- El sensor óptico se instalará en la cámara de retorno, donde la evaporación modifica realmente el nivel
- La bomba se colocará dentro de un depósito alimentario cerrado y reservado para RO/DI
- La salida del tubo quedará por encima del nivel máximo del depósito y del agua cuando sea necesario para impedir el sifonado
- El rompe-sifón se colocará por encima del nivel máximo del agua del depósito
- El extremo de salida del tubo no quedará sumergido en el agua de la cámara de retorno durante el funcionamiento normal
- El cableado y la tubería quedarán sujetos, sin pinzamientos y con bucle antigoteo
- El depósito no contendrá agua salada, suplementos ni productos de mantenimiento

El sensor se instalará a la altura normal de trabajo, haciendo que el nivel alcance el sensor óptico inferior. Debe quedar alejado de microburbujas, turbulencias directas, salpicaduras y zonas donde pueda acumularse sal o biofilm.

## Pruebas obligatorias

1. Activación al bajar el nivel
2. Parada en el nivel establecido
3. Respuesta del segundo sensor o de la protección disponible
4. Ausencia de sifón con la bomba apagada
5. Comportamiento al vaciarse el depósito
6. Comportamiento tras un corte eléctrico

## Criterios de aceptación

- Nivel estable sin ciclos excesivamente cortos
- El caudal no remueve sedimento ni salpica los sensores
- Autonomía suficiente sin ocultar una fuga
- Sensor accesible para limpieza e inspección
- La bomba no puede vaciar el depósito hacia la urna por sifón
- La cámara de retorno conserva un nivel seguro cuando el depósito se agota

La doble óptica reduce el riesgo, pero no constituye por sí sola una protección independiente contra inundaciones o reposición excesiva. El primer rellenado debe vigilarse porque el límite temporal de seguridad se establece a partir de esa referencia inicial.

### Smart Level

El controlador registra la duración del primer rellenado y activa una alarma visual si un rellenado posterior dura seis veces más. Por ejemplo, si el primer ciclo dura 10 segundos, la alarma puede activarse al superar 60 segundos.

Esta función puede detectar, entre otras situaciones:

- Interferencia de microburbujas
- Sobrellenado o lectura anómala del sensor
- Fallo del sensor o del controlador
- Depósito vacío, para evitar que la bomba funcione en seco

El primer rellenado no dispone de ese límite temporal aprendido. Tras resolver una alerta, el manual indica apagar y volver a encender el equipo para reiniciarlo.

En acuarios muy pequeños, el sensor superior puede activarse brevemente después de cada reposición; el manual lo considera un comportamiento normal si no aparece una alerta roja.

## Interfaz e indicadores

| Indicador | Significado |
| --- | --- |
| LED azul y rojo alternos | Inicialización |
| LED azul fijo | Alimentación conectada y equipo preparado |
| LED azul intermitente | Reposición o bombeo |
| LED azul que parpadea rápidamente durante poco tiempo | El sensor de seguridad detecta un cambio de nivel |
| LED rojo intermitente | Alerta Smart Level; revisar microburbujas, sobrellenado o depósito vacío |

## Mantenimiento

- Limpiar periódicamente sensores, bomba y tubo
- Retirar sal, carbonatos, algas y biofilm
- Verificar que la bomba no funcione en seco
- Repetir las pruebas de seguridad después de limpiar o cambiar la disposición
- Inspeccionar cableado y conectores antes de volver a energizar

## Integración con supervisión

El ATO funcionará de forma autónoma con sus protecciones nativas. La supervisión externa podrá observar consumo, disponibilidad y anomalías si la integración lo permite, pero no sustituirá las protecciones del equipo ni la comprobación visual.

No se aplicarán ventanas horarias ni cortes automáticos hasta comprobar con el equipo real que conserva sus protecciones, reinicia de forma fiable y no produce oscilaciones de nivel o salinidad.

La integración prevista mediante un [SONOFF S60ZBTPF y Zigbee2MQTT](home-assistant-zigbee2mqtt.md) puede añadir límites de tiempo, ventanas de habilitación, registro y corte de emergencia. No mide el nivel de agua y no sustituye Smart Level.

El fabricante ofrece como accesorio opcional un Smart AC Switch. No forma parte del equipo documentado para Veril y no se considerará necesario para la instalación base.

## Fuente interna

- [Manual oficial H2Ocean Compact ATO](h2ocean-compact-ato-manual.pdf)

## Fuente externa

- [D-D: H2Ocean Compact ATO](https://www.theaquariumsolution.com/product/8111/451)

## Estado en Veril

**Confirmado:** equipo seleccionado para la reposición automática de Veril.

**Pendiente de ejecución:** ubicación definitiva del depósito, recorrido y fijación del tubo, marcas de nivel mínimo y máximo, autonomía real y validación completa después de un corte eléctrico.

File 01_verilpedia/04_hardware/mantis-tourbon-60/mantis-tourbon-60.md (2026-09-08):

# Mantis Tourbon 60 Wave Maker

## Identificación

| Parámetro | Valor documentado |
| --- | --- |
| Fabricante | Mantis Aquarium Technology Co., Ltd. |
| Modelo | Tourbon 60 |
| Tipo | Bomba de movimiento y generadora de olas |
| Caudal máximo declarado | 4.000 l/h |
| Consumo declarado | 3–15 W en la tabla oficial; varias tiendas publican 8 W para la Tourbon 60 |
| Alimentación | DC 24 V según la tabla oficial |
| Montaje | Imán exterior, con orientación regulable |
| Grosor máximo de cristal | 10 mm |
| Uso declarado | Agua dulce y agua marina |
| Control | Controlador cableado incluido |
| Comunicación de red | La web oficial enlaza una aplicación; no está confirmado que la Tourbon 60 de Veril sea compatible con ella |

La Tourbon 60 es la bomba de circulación seleccionada para el display de Veril. El caudal máximo es una cifra de catálogo, no una medición de caudal útil dentro de la urna. La roca, el nivel, la orientación, la altura, el sustrato y los corales modificarán el movimiento real.

El manual público de la serie disponible describe la instalación, los modos, las protecciones y el mantenimiento, pero su tabla de parámetros muestra explícitamente las Tourbon 100 y 200 y no incluye una fila independiente para la Tourbon 60. La página oficial sí publica una tabla específica para esta variante: 24 V CC, 4.000 l/h, 3–15 W, cristal de hasta 10 mm y acuarios de 40–60 cm. Varias fichas comerciales publican **8 W** como consumo máximo, por lo que el consumo exacto se comprobará en la etiqueta y la fuente de la unidad recibida.

## Función en Veril

La bomba generará circulación interna alrededor de la roca, el corredor trasero, las microislas y la superficie. No sustituye al retorno: el retorno mantiene la renovación entre display y sump, mientras la Tourbon 60 distribuye el movimiento dentro del display y reduce zonas de acumulación.

El máximo nominal equivale aproximadamente a **42 veces** el volumen geométrico de 96 L. Ese múltiplo no será un objetivo de funcionamiento. La intensidad se establecerá por el comportamiento del agua y de los organismos, no por una relación fija entre litros por hora y litros de urna.

## Construcción y montaje

La bomba utiliza un conjunto compacto con rotor, eje, jaulas de flujo, casquillos y elementos elastoméricos. El eje se documenta como cerámico en las fichas técnicas disponibles. El soporte magnético permite fijarla al vidrio y orientar el cuerpo con varios ángulos.

La bomba trabaja mediante un adaptador externo de baja tensión y un controlador cableado. El cable de la bomba utiliza un conector de tres pines con el controlador; el adaptador se conecta después al controlador. No se conectará la bomba directamente a la red eléctrica.

## Modos de funcionamiento

El controlador incorpora cinco modos principales:

- **Flujo constante:** mantiene una salida continua con la intensidad seleccionada. Es el modo inicial más fácil de interpretar.
- **Flujo de onda:** aumenta y reduce progresivamente la velocidad. El tiempo de subida y bajada se regula mediante el control de frecuencia.
- **Modo pulsante:** alterna un pico de flujo con una reducción rápida hacia la potencia mínima. Puede producir una oscilación más marcada y desplazar el sustrato si se ajusta demasiado alto.
- **Modo aleatorio:** cambia de forma variable la velocidad y la intensidad hasta el máximo configurado. Es difícil comparar su efecto sin registrar observaciones durante un periodo suficiente.
- **Modo ciclo:** alterna automáticamente los cuatro modos anteriores y cambia al siguiente después de diez ciclos.

La frecuencia y la intensidad se regulan desde el controlador. El enlace de dos bombas, si se utiliza con otra unidad compatible, permite designar una unidad maestra y otra subordinada para generar ondas alternas. Veril utiliza una sola Tourbon 60, por lo que esa función no forma parte de la configuración.

## Funciones auxiliares del controlador

- **Pausa de alimentación:** una pulsación prolongada detiene la bomba durante aproximadamente 20 minutos y después reanuda el modo seleccionado.
- **Modo nocturno:** un sensor de luz reduce el caudal cuando detecta poca iluminación ambiental. No conoce la hora ni el estado biológico del acuario.
- **Bloqueo:** impide cambiar accidentalmente la configuración desde los botones.

El controlador y el manual suministrado no documentan una interfaz de red, un protocolo, una API ni un procedimiento de emparejamiento con una aplicación. La web oficial sí incluye un enlace general de descarga de una aplicación, pero no identifica en esa página la compatibilidad concreta con la Tourbon 60 ni sustituye la verificación de la unidad recibida. El enlace entre dos controladores es una función local del equipo y no una integración de red.

## Protecciones documentadas

La electrónica incluye varias respuestas de protección:

- **Escasez de agua:** reduce la bomba a la velocidad más baja.
- **Rotor bloqueado o sucio:** detiene o limita el funcionamiento y vuelve a comprobar el estado aproximadamente cada 30 segundos hasta que se resuelva el bloqueo.
- **Tensión fuera de rango:** entra en protección si detecta una tensión inferior a 9 V o superior a 38 V en el circuito indicado por el manual.
- **Pérdida de fase:** detiene el motor si detecta una anomalía en los grupos de bobinas.
- **Controlador sin bomba conectada:** puede dejar el indicador de bloqueo parpadeando; para recuperar el funcionamiento se desconecta la alimentación, se conecta correctamente la bomba y se vuelve a alimentar el conjunto.

Estas protecciones no sustituyen la inspección. Una bomba parcialmente obstruida puede seguir moviendo agua sin aportar el caudal previsto.

## Integración física en Veril

La bomba se instalará en:

- lateral izquierdo del display;
- tercio superior, aproximadamente 8–12 cm bajo la superficie como punto de partida;
- orientación inicial hacia la derecha, ligeramente hacia atrás y hacia arriba;
- posición que cree renovación del corredor trasero sin golpear directamente el sustrato, el cristal opuesto o un coral.

La posición final se ajustará después de instalar la roca, el sustrato y el nivel operativo real. El cable y el imán deben permanecer accesibles para inspección, retirada y limpieza.

La colocación se aceptará cuando:

- la superficie presente movimiento continuo sin salpicaduras;
- el corredor trasero reciba renovación sin crear un chorro aislado;
- no haya zonas de detrito que permanezcan inmóviles de forma persistente;
- el sustrato no se desplace continuamente ni forme cráteres;
- las microislas no vibren ni reciban un flujo que desplace sus organismos;
- el flujo no retraiga de forma sostenida a los corales ni los golpee directamente;
- la bomba no produzca vibración anómala, ruido creciente o calentamiento excesivo.

## Puesta en marcha

1. Limpiar y secar el vidrio en la zona de montaje.
2. Conectar el cable de tres pines de la bomba al controlador antes de alimentar el sistema.
3. Conectar el adaptador de baja tensión al controlador y después a la red.
4. Montar las dos partes del imán lentamente y de forma desplazada, evitando atrapamientos de los dedos y golpes sobre el vidrio.
5. Comenzar en flujo constante y con la intensidad mínima que permita observar el recorrido del agua.
6. Comprobar la superficie, el corredor trasero, el sustrato y las zonas protegidas.
7. Registrar cada cambio de intensidad, modo u orientación por separado.

Los modos de pulsos, onda, aleatorio y ciclo se probarán solo después de validar la orientación básica. No se cambiarán a la vez el modo, la posición y la geometría de la roca, porque se perdería la capacidad de interpretar el efecto.

## Mantenimiento

Antes de manipular la bomba se desconectará el adaptador de la red. Para la limpieza:

1. Retirar el imán exterior con cuidado y separar las dos partes.
2. Extraer las tapas de los impulsores siguiendo el sentido indicado por el manual.
3. Retirar jaulas de flujo, casquillos, gomas y rotor.
4. Eliminar algas, carbonato, sustrato y detrito sin dañar el eje cerámico ni las superficies de apoyo.
5. Comprobar que el rotor gira libremente y que las gomas permanecen asentadas.
6. Montar de nuevo el conjunto y probarlo en agua antes de devolverlo a su posición definitiva.

Se revisará la bomba si aparece pérdida progresiva de caudal, ruido, vibración, reinicios del controlador, funcionamiento intermitente o aumento de temperatura. La limpieza no se hará únicamente por calendario: también se activará por cambios observables de rendimiento.

## Integración eléctrica y supervisión

El controlador no dispone de una integración de red documentada. El adaptador se conectará a una unidad independiente del [SONOFF S60ZBTPF](../sonoff-s60zbtpf/sonoff-iplug-s60zbtpf.md) para permitir un corte general y una supervisión eléctrica, pero el enchufe no sustituirá al controlador ni se utilizará para crear las ondas o las pausas de alimentación.

La integración detallada con Home Assistant y el [SONOFF S60ZBTPF](../sonoff-s60zbtpf/sonoff-iplug-s60zbtpf.md), incluyendo calibración de consumo, alarmas y pruebas de recuperación, está documentada en la [ficha de integración de la Tourbon 60](home-assistant-zigbee2mqtt.md). El consumo eléctrico no demuestra que el rotor esté entregando el caudal correcto: la supervisión debe complementarse con observación del flujo y mantenimiento del conjunto.

## Experiencia de uso y evidencia disponible

La evidencia práctica específica de la Tourbon 60 es muy escasa. No se ha localizado una prueba independiente que publique caudal medido, consumo real, nivel de ruido, temperatura o duración del conjunto bajo condiciones controladas.

La página oficial de Mantis muestra una única reseña de usuario, fechada el 25 de julio de 2024, que indica que el control mediante la aplicación es fácil y cómodo. No identifica de forma visible la variante utilizada, no aporta mediciones ni describe el acuario. La reseña se conserva como indicio de experiencia de control, pero no valida la compatibilidad de la Tourbon 60 de Veril con la aplicación ni permite valorar su rendimiento.

Coral Center y AQ-Arium publican para la Tourbon 60 un caudal máximo de 4.000 l/h, 8 W, 24 V CC y compatibilidad con cristal de hasta 10 mm. Coral Center añade unas dimensiones de 67 mm de longitud, 55 mm de diámetro y 10,3 mm para el imán exterior. AQ-Arium especifica además el contenido comercial del conjunto: adaptador, motor húmedo, controlador, imán y manual. Son fichas comerciales, no ensayos independientes.

El vídeo de AquariumWorldEsp muestra un desembalaje, instalación y prueba de una **Tourbon 200**, no de la Tourbon 60. Permite observar el controlador, la selección de modos, la regulación por porcentaje y una percepción subjetiva de un flujo intenso con la unidad ajustada al 40 %. El autor no mide caudal, ruido ni consumo, y sus observaciones no se trasladan a la Tourbon 60. Se conserva como evidencia práctica de la interfaz y del comportamiento general de la familia, no como validación del modelo seleccionado.

Existe una experiencia publicada con una **Tourbon 100**, distinta de la Tourbon 60, instalada en un acuario marino y ajustada al 60 % de su caudal nominal. No aporta mediciones de ruido, caudal real ni durabilidad y no se utilizará para transferir resultados a la Tourbon 60.

Las páginas comerciales que describen la Tourbon 60 repiten principalmente las especificaciones del producto. Las afirmaciones de funcionamiento silencioso, durabilidad y bajo calentamiento se consideran características declaradas, no resultados independientes.

Por tanto, la aceptación de la unidad de Veril se basará en una prueba propia:

- registrar consumo si se dispone de medidor;
- observar ruido y vibración en silencio ambiental;
- comprobar el movimiento con partículas inocuas o alimento antes de introducir animales;
- comprobar la respuesta de el sustrato y de las microislas;
- registrar el comportamiento del controlador en modo constante y en un modo variable;
- repetir la observación después de la primera limpieza.

## Limitaciones

- El caudal de 4.000 l/h es nominal y no equivale al caudal real dentro del aquascape.
- No se dispone de un mapa hidráulico ni de una medición de distribución para la urna de Veril.
- El sensor nocturno depende de la iluminación ambiental y puede activarse de forma no prevista si cambia la luz de la habitación.
- Las protecciones electrónicas no detectan todas las pérdidas de rendimiento causadas por suciedad o desgaste.
- La compatibilidad del imán debe comprobarse sobre el espesor y el cristal reales de la urna.
- La bomba no debe funcionar fuera del agua para probarla.
- La ausencia de una prueba independiente de ruido y durabilidad impide convertir “ultrasilenciosa” o “duradera” en criterios garantizados.

## Fuentes

- [Mantis Aquarium: Tourbon Wave Pump](https://mantisaquarium.com/wave-pump/)
- [Mantis Aquarium: ficha oficial de Tourbon Wave Pump](https://mantisaquarium.com/wave-pump/tourbon-wave-pump/)
- [Mantis Aquarium: página general del fabricante](https://mantisaquarium.com/)
- [Manual de la serie Mantis Tourbon](mantis-tourbon-manual.pdf)
- [Manual público de la serie Tourbon](https://www.aquaticline.es/wp-content/uploads/sites/3/2021/07/Instrucciones-Nuevas-Tourbon-Series-1.pdf)
- [Tropical Nature: Tourbon 60, 4.000 l/h](https://tropicalnature.it/en/product-detail/6317/pumps-movement/mantis-tourbon-60-4000l-h)
- [A.G.P.: Tourbon 60 / 100 / 200](https://www.agpsrl.eu/apparecchiature-tecniche/pompe-di-movimento/tourbon-60-100-200.html)
- [Aquaristic Online: Mantis Tourbon Wavemaker 60](https://www.aquaristiconline.com.au/collections/mantis/products/mantis-tourbon-wavemaker-60)
- [DaniReef: experiencia con una Tourbon 100 en un acuario marino](https://forum.danireef.com/viewtopic.php?f=34&t=34195) — variante distinta, no transferible a la Tourbon 60
- [Coral Center: Mantis Tourbon Pump](https://coralcenter.es/producto/equipamiento/bombas/bombas-de-movimiento/mantis-tourbon-pump/)
- [AQ-Arium: Tourbon Wave Pump Mantis, nueva versión](https://www.aq-arium.com/aqmarine/acuario-marino/tourbon-wave-pump-mantis-nueva-version/)
- [AquariumWorldEsp: unboxing y prueba de una Tourbon 200](https://www.youtube.com/watch?v=IjscbS5rOH8) — variante distinta, no transferible a la Tourbon 60
- [Hidráulica de Veril](../../../02_configuracion/01_dimensiones/03_hidraulica.md)

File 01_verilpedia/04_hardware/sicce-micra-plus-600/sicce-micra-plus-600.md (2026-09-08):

# Sicce Micra Plus 600

## Identificación y función en Veril

La **Sicce Micra Plus 600** será la bomba de retorno del compartimento técnico. Elevará el agua desde la cámara de retorno al display; no será la bomba principal de movimiento del acuario. La circulación interna la realizará la Mantis Tourbon 60.

La bomba de retorno de Veril ya dispone de su tubo instalado. Además, se ha adquirido un tubo Eheim auxiliar de **3 m, 16/22 mm**, referencia **4005843**, destinado a llenados, trasvases y conexiones temporales entre recipientes o cámaras. No se asigna a la salida de la Micra Plus ni se utilizará para sustituir su tubo de retorno sin una decisión específica.

La alimentación y la supervisión mediante una unidad independiente del [SONOFF S60ZBTPF](../sonoff-s60zbtpf/sonoff-iplug-s60zbtpf.md) están documentadas en la [ficha de integración con Home Assistant](home-assistant-zigbee2mqtt.md).

## Especificaciones documentadas

| Parámetro | Valor documentado |
| --- | --- |
| Fabricante | Sicce S.r.l. |
| Modelo | Micra Plus |
| Variante de referencia para Veril | 220–240 V / 50 Hz |
| Tipo | Bomba sumergible compacta de recirculación |
| Motor | Síncrono accionado por imán permanente |
| Caudal máximo declarado | 600 l/h |
| Altura máxima declarada | 0,85 m en el manual; 0,8 m en algunos catálogos de Sicce |
| Potencia declarada | 6,5 W |
| Corriente declarada | 0,035 A |
| Regulación | Regulador mecánico de caudal; distribuidores describen cinco posiciones |
| Filtración incluida | Esponja pequeña intercambiable en la entrada |
| Entrada de agua | Rejilla de aspiración, incluida la aspiración inferior según la documentación de la gama |
| Salida documentada | Tubo flexible de 12 × 16 mm mediante adaptador o tubo rígido de 13 mm |
| Dimensiones publicadas | Aproximadamente 72 × 60 × 61 mm; comprobar el espacio con la unidad recibida |
| Cable | 1,5 m en la variante habitual; existen referencias con cable de 10 m |
| Uso declarado | Agua dulce, agua marina, acuarios, pequeños circuitos de recirculación y fuentes interiores |
| Temperatura máxima documentada | 35 °C |

La ficha del manual local indica **0,85 m**, mientras que el catálogo de Sicce redondea la misma prestación a **0,8 m**. Se conservarán ambas cifras como una diferencia de presentación, no como dos capacidades distintas. El caudal de 600 l/h y la altura máxima son valores de catálogo en condiciones de ensayo y no el caudal que llegará al display con la altura, tubería, codos, regulador, esponja y suciedad de Veril.

## Construcción y accesorios

La bomba utiliza un motor síncrono de imán permanente y un rotor desmontable. El conjunto compacto está pensado para trabajar sumergido. La Micra Plus incorpora:

- Regulación mecánica del flujo
- Esponja de entrada intercambiable
- Rejilla de aspiración que permite trabajar con un nivel de agua bajo, siempre que no quede por debajo de las entradas
- Ventosas y elementos de apoyo para reducir el movimiento de la bomba
- Adaptador para la conexión documentada de tubo
- Cámara frontal o *prechamber* compatible con la conexión de salida

La esponja puede proteger el rotor frente a partículas, pero también puede convertirse en una restricción hidráulica cuando acumula detrito, algas o carbonato. No se interpretará la presencia de la esponja como una garantía de filtración mecánica suficiente para el sistema.

## Rendimiento hidráulico

El manual incluye una curva de características para la variante de 230 V / 50 Hz. La curva muestra aproximadamente el caudal máximo con altura nula y una reducción progresiva al aumentar la altura. No publica una tabla completa de caudal para cada altura ni representa la instalación concreta de Veril.

Como referencia de catálogo:

- **600 l/h:** Caudal máximo declarado a altura nula
- **0,5 m:** El gráfico del fabricante sitúa el caudal aproximadamente en torno a 500 l/h, como lectura orientativa de la curva
- **0,85 m:** Altura máxima declarada, no objetivo de operación

La siguiente representación Mermaid digitaliza de forma aproximada la curva visible en el manual para la variante **Micra Plus 230 V / 50 Hz**. Los puntos se han leído visualmente de la gráfica y no constituyen una tabla de mediciones. No sustituye una medición con la tubería, la altura y la regulación de Veril.

```mermaid
xychart-beta
    title "Sicce Micra Plus 230 V / 50 Hz: curva caudal-altura"
    x-axis "Caudal (l/h)" [0, 50, 100, 150, 200, 250, 300, 350, 400, 450, 500, 550, 600]
    y-axis "Altura (cm)" 0 --> 90
    line [85, 83, 80, 77, 72, 66, 60, 53, 45, 37, 28, 15, 0]
```

No se utilizará el cálculo de **600 l/h ÷ 96 l = 6,25 renovaciones por hora** para dimensionar el retorno. Ese resultado solo combina el caudal nominal a altura nula con el volumen geométrico y no representa el funcionamiento hidráulico de Veril.

## Punto de trabajo hidráulico real

El caudal de retorno se calculará en el punto de intersección entre la curva de la bomba y la curva de resistencia de la instalación. La curva del fabricante representa la bomba sin la tubería ni el rebosadero de Veril.

La resistencia real se determinará con:

- Diferencia vertical entre el nivel operativo de la cámara de retorno y la cota efectiva de descarga
- Nivel del agua del display cuando el rebosadero está funcionando
- Profundidad de la salida si descarga bajo la superficie del display
- Longitud interior y diámetro real de la tubería
- Adaptadores, codos, cambios de sección, válvulas y uniones
- Regulación mecánica de la Micra Plus
- Pérdida de carga de la esponja y de la rejilla cuando estén sucias
- Pérdida de carga del paso de entrada y del rebosadero de la urna
- Caudal de retorno que el rebosadero puede admitir sin elevar el nivel de forma insegura

Para una estimación inicial se representará la instalación mediante una curva de sistema del tipo:

```text
H_sistema(Q) = H_estática + H_pérdidas(Q)
```

Las pérdidas aumentan con el caudal y dependen de la velocidad del agua y de la geometría del circuito. El caudal operativo será el valor `Q` en el que `H_bomba(Q)` y `H_sistema(Q)` sean iguales. Si la salida queda sumergida, la cota y la presión de descarga se incorporarán a la condición hidráulica en lugar de tratar la altura de la bomba como una cifra aislada.

La altura de salida, el diámetro interior definitivo, la longitud, los accesorios y los niveles mínimo y operativo todavía deben medirse en la urna montada. Hasta disponer de esas medidas, no se publicará una cifra de renovaciones por hora como resultado del diseño.

La Micra Plus no sustituye a la bomba de movimiento. Un retorno demasiado alto puede aumentar el ruido del rebosadero, vaciar la cámara de retorno o elevar el nivel de forma insegura, mientras que uno demasiado bajo puede limitar el intercambio entre display y compartimento técnico.

## Instalación prevista

La bomba se instalará completamente sumergida en la cámara de retorno, sobre una superficie estable y con la aspiración libre. El manual indica mantener aproximadamente 2 cm de agua y no dejar que el nivel quede por debajo de las rejillas de aspiración.

La instalación deberá cumplir:

- Mantener la bomba sumergida durante el funcionamiento
- Evitar que aspire sustrato, caracoles, algas, trozos de roca o detrito grande
- Mantener accesibles la entrada, la esponja, el rotor y la conexión de salida
- Utilizar el tubo y el adaptador sin forzar la salida de la bomba
- Evitar curvas cerradas, estrangulamientos y tramos innecesariamente largos
- Mantener el cable con un bucle antigoteo por debajo de la toma eléctrica
- Conectar la alimentación a un circuito protegido por diferencial de hasta 30 mA
- Confirmar que el nivel máximo tras un corte no desborda el display ni el compartimento técnico

La regulación se iniciará en una posición baja y se aumentará gradualmente hasta que el retorno sea estable. El ajuste final dependerá del nivel real, el ruido, la capacidad del rebosadero, las microburbujas y la estabilidad de la cámara de retorno.

## Puesta en marcha y validación

1. Limpiar la cámara de retorno y comprobar que no contiene sustrato ni partículas sueltas
2. Revisar que la bomba, el cable, las ventosas, la esponja y el adaptador no presentan daños
3. Colocar la bomba completamente sumergida y con la aspiración libre
4. Conectar el tubo de retorno y comprobar que no queda doblado ni estrangulado
5. Abrir la regulación en una posición baja
6. Alimentar la bomba mediante su unidad independiente del S60ZBTPF
7. Comprobar que la cámara no se vacía, que el rebosadero admite el caudal y que no se produce retorno peligroso al parar
8. Medir el nivel operativo de la cámara, el nivel estable del display, la cota y la profundidad de la salida, la longitud y el diámetro interior de la tubería y todos los accesorios
9. Medir el tiempo y el volumen transferido con esa resistencia hidráulica real
10. Aumentar la regulación solo si el sistema conserva margen hidráulico y eléctrico
11. Registrar la posición del regulador, los niveles, el ruido, las microburbujas y el caudal medido

La bomba no se considerará validada por su cifra de catálogo. La aceptación exigirá demostrar que el retorno es estable en funcionamiento continuo y que el sistema se recupera después de un corte sin funcionar en seco.

## Mantenimiento

El manual indica limpiar periódicamente la pequeña esponja o hacerlo cuando el flujo disminuya excesivamente. Para el resto del conjunto, la versión inglesa e italiana del manual indica extraer el rotor aproximadamente cada **dos meses** y lavar los componentes con agua templada para retirar depósitos de calcio. Las secciones española y portuguesa expresan un intervalo de **tres meses** para las demás piezas. Se adoptará como criterio operativo revisar antes si cae el caudal y no esperar al intervalo máximo cuando haya agua marina, carbonato o detrito.

Procedimiento:

1. Apagar el S60ZBTPF y desconectar la alimentación antes de introducir las manos en el agua
2. Retirar la bomba o el frontal de la cámara según el acceso disponible
3. Extraer y enjuagar la esponja con agua marina limpia o sustituirla si está deteriorada
4. Retirar el rotor sin forzar el eje ni el alojamiento
5. Enjuagar rotor, eje, cámara y rejillas con agua templada
6. Eliminar el carbonato con un método compatible con el material y enjuagar completamente antes de devolver la bomba al acuario
7. Comprobar que el rotor gira libremente y que las gomas, ventosas y conexiones están asentadas
8. Montar el conjunto, sumergirlo y comprobar el rearranque antes de cerrar el compartimento
9. Registrar la fecha, el estado de la esponja, la suciedad, el ruido y el caudal observado

No se limpiará el conjunto con la bomba conectada. El cable de esta bomba es de tipo Z y no está previsto que el usuario lo repare o sustituya; si queda dañado, se dejará de utilizar el aparato.

## Integración eléctrica y Home Assistant

La Micra Plus se conectará a un S60ZBTPF independiente. Home Assistant supervisará la alimentación y el consumo, pero el enchufe no medirá el nivel de la cámara ni demostrará el caudal.

La potencia se calibrará con la instalación definitiva y se interpretará junto con el nivel de la cámara, el estado del rebosadero y la disponibilidad Zigbee. Las alarmas de consumo cero o anómalo están desarrolladas en la [ficha de integración con Home Assistant](home-assistant-zigbee2mqtt.md).

## Evidencia de uso y reseñas

### Especificaciones del fabricante y documentación técnica

El manual de Sicce confirma el funcionamiento sumergido, el regulador de flujo, las conexiones de 12 × 16 mm y 13 mm, la necesidad de evitar el funcionamiento en seco, la temperatura máxima de 35 °C, la protección diferencial y el mantenimiento del filtro y el rotor. También aporta la curva de caudal y altura para la variante de 230 V / 50 Hz.

El catálogo de Sicce confirma 600 l/h, 6,5 W, 0,8 m de altura máxima en su redondeo, el diseño compacto, la aspiración inferior, la esponja intercambiable y los elementos antivibración. Las piezas de repuesto publicadas identifican el rotor, las ventosas, la esponja, el conector de tubo y la cámara frontal. Estos datos son documentación del fabricante, no mediciones independientes de la unidad de Veril.

### Fichas comerciales

Las tiendas consultadas repiten principalmente las cifras del fabricante y describen la bomba como compacta, regulable y adecuada para agua dulce y marina. Una tienda especializada especifica la regulación mediante una llave de cinco posiciones, la esponja intercambiable y la conexión de 12 × 16 mm o 13 mm. Estas fichas ayudan a identificar el contenido y las variantes comerciales, pero no prueban el caudal real, el ruido ni la durabilidad.

### Reseñas de usuarios

- En Bulk Reef Supply hay varias reseñas antiguas que la describen como muy silenciosa y compacta, incluida una experiencia positiva como bomba de ATO, pero también una reseña que informa de arranque tardío y fallo completo después de aproximadamente cinco meses. Son experiencias individuales y no establecen una tasa de fallos
- En un hilo de ReefTank de 2019, un usuario informa de que la Micra Plus aportó más caudal que la bomba original de un nanoacuario, aunque también menciona un zumbido perceptible. La experiencia depende de la cámara, el apoyo y la transmisión de vibraciones
- En un hilo de ReefTank publicado en 2026, un usuario informa de un zumbido persistente tras ocho meses pese a limpiar la bomba y revisar contactos. El propio intercambio plantea como posibilidades la posición, el tubo o la transmisión mecánica; no permite atribuir la causa al modelo en general
- En Skroutz aparece una valoración agregada de 4,8 sobre 5 con cuatro opiniones, pero una de las reseñas señala que la bomba resulta ruidosa en una caja de acuario. La muestra es pequeña
- En Zboží.cz hay dos opiniones con resultados opuestos: una valora el tamaño y el consumo, pero afirma que no consiguió elevar agua hasta 80 cm y que faltaba un conector; otra valora positivamente el rendimiento y el tamaño. La primera experiencia es compatible con la diferencia entre altura nominal y caudal útil, pero el problema del accesorio no se puede atribuir a todas las unidades

Las reseñas muestran que el ruido, el arranque y la vida útil pueden depender del apoyo, la resonancia de la cámara, la tubería, la limpieza, el desgaste del rotor y la unidad concreta. No se utilizará “silenciosa” como una especificación garantizada.

### Pruebas independientes

No se ha localizado una prueba independiente reproducible que publique, para esta variante y con condiciones completas, un mapa de caudal, consumo real, ruido, temperatura, vibración y duración. Las cifras de 600 l/h, 6,5 W y 0,8–0,85 m proceden del fabricante y de distribuidores que reproducen su documentación.

## Criterios de aceptación en Veril

La unidad se considerará adecuada cuando:

- Arranque de forma consistente después de varios cortes controlados
- Mantenga la cámara de retorno dentro de sus niveles mínimo y operativo
- No se acerque al límite de funcionamiento en seco durante la evaporación prevista
- Entregue un caudal medido compatible con el rebosadero y el intercambio requerido
- No produzca vibración o zumbido que se transmita a la urna o al mueble
- Mantenga la salida y la esponja accesibles para limpieza
- No genere microburbujas persistentes ni salpicaduras
- Active las alarmas del S60ZBTPF cuando el consumo o la disponibilidad sean anómalos

La prueba se repetirá después de la primera limpieza y después de cualquier cambio de tubo, altura, regulación o apoyo.

## Limitaciones

- El caudal nominal no equivale al caudal real del retorno
- La curva publicada no sustituye la medición con la instalación definitiva
- La altura máxima no implica que la bomba entregue un caudal útil a esa altura
- La esponja puede reducir el caudal al obstruirse
- La bomba no debe funcionar en seco ni con líquidos corrosivos o abrasivos
- El S60ZBTPF no detecta por sí solo una cámara vacía, un tubo obstruido o un caudal insuficiente
- Las reseñas disponibles son escasas, heterogéneas y no controladas
- El ruido y la durabilidad de la unidad de Veril siguen pendientes de prueba propia

## Fuentes

- [Manual oficial Sicce Micra y Micra Plus](https://us.sicce.com/media/wysiwyg/ISTRUZIONI/82600-H_SICCE_Micra_Instruction.pdf)
- [Manual local de la Sicce Micra Plus](sicce-micra-instruction.pdf)
- [Catálogo técnico Sicce Easy Line](https://us.sicce.com/media/wysiwyg/UTSD207-A_EN-DE_catalogo2018_ISSUU.pdf)
- [Piezas de repuesto y datos técnicos Sicce](https://us.sicce.com/media/wysiwyg/UTSD210_EN-DE_spare_parts_preview.pdf)
- [Sicce: gama Easy Line](https://us.sicce.com/en/products/multifunction-pumps/easy-line.html?___from_store=fr)
- [Reef Supplies Canada: Micra Plus 600](https://www.reefsupplies.ca/products/sicce-micraplus-158gph-2-8ft-head)
- [Bulk Reef Supply: reseñas de Micra Plus](https://www.bulkreefsupply.com/review/product/listAjax/id/2692/)
- [ReefTank: Sicce Micra Plus](https://www.reddit.com/r/ReefTank/comments/1rvumue/siche_micra_plus/)
- [ReefTank: Smart socket y Micra Plus](https://www.reddit.com/r/ReefTank/comments/e1ryle)
- [Skroutz: reseñas de Sicce Micra Plus](https://www.skroutz.de/s/24689329/Sicce-Micra-Plus-Aquarien-Umwaelzpumpe-6-5W-Mit-Kabel-1-5m-600-L-H.html)
- [Zboží.cz: reseñas de Sicce Micra Plus](https://www.zbozi.cz/vyrobek/sicce-micra-plus-600-l-h/vsechny-recenze/)
- [Ficha de integración con Home Assistant](home-assistant-zigbee2mqtt.md)
- [Técnica de la urna](../urna/tecnica.md)

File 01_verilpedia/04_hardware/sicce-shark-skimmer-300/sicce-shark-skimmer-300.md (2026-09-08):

# Sicce Shark SKIMMER 300

- **Fabricante:** Sicce
- **Modelo:** Shark SKIMMER 300
- **Código:** `SHSKM300E`
- **Tipo:** skimmer interno para acuario marino

## Ficha normalizada

| Campo | Valor |
| --- | --- |
| `hardware_id` | `Sicce_Shark_Skimmer_300` |
| `category` | `aquarium` |
| `vendor` | `Sicce` |
| `model` | `Shark SKIMMER 300` |
| `hardware_kind` | `physical` |
| `physical_type` | `protein_skimmer` |
| `rated_power` | 5 W |
| `air_flow` | hasta 180 L/h |
| `mounting` | soporte magnético para cristal de hasta 15 mm |
| `environment` | acuario marino |
| `connectivity` | ninguna |
| `software` | no aplicable |

## Especificaciones

| Parámetro | Valor declarado |
| --- | --- |
| Potencia | 5 W |
| Longitud de cable | 2,2 m |
| Dimensiones | 83 × 125 × 243 mm |
| Aire máximo | 180 L/h |
| Cristal máximo | 15 mm |
| Profundidad de inmersión | 130–150 mm |
| Volumen de copa | 260 ml |
| Bomba/impulsor | conjunto interno específico del skimmer |
| Entrada de agua | regulable |
| Funcionamiento | espumación a contracorriente |
| Compatibilidad con ozono | sí, según fabricante |
| Accesorio | cepillo de limpieza incluido |

## Capacidad orientativa

La documentación comercial diferencia la capacidad según la carga:

| Tipo de sistema | Volumen máximo declarado |
| --- | ---: |
| Carga biológica baja | 300 L |
| Carga biológica media | 200 L |
| Carga biológica alta | 100 L |

Estas cifras proceden de la tabla técnica del manual. Son orientativas: el rendimiento depende de carga orgánica, nivel de agua, salinidad, ajuste de aire y mantenimiento.

## Construcción

- Diseño interno compacto
- Cuerpo opaco para limitar el crecimiento de algas en el interior
- Soporte magnético resistente al agua
- Copa desmontable
- Entrada de agua regulable
- Impulsor autolimpiante optimizado para espumación

## Software y conectividad

No incorpora firmware, aplicación ni conexión de red. Su funcionamiento es electromecánico. Un enchufe externo permite conmutar alimentación, pero no mide nivel, aire, caudal ni llenado de copa.

La integración prevista del enchufe con Home Assistant y Zigbee2MQTT está documentada en [Integración del Sicce Shark SKIMMER 300](home-assistant-zigbee2mqtt.md).

## Instalación

1. Instálalo verticalmente en un nivel de agua estable
2. Mantén libre la toma de aire y accesible la copa
3. Ajusta progresivamente entrada y aire durante el rodaje
4. Deja espacio para extraer y desmontar el cuerpo
5. Evita que el cable forme un camino de agua hacia la toma eléctrica
6. Desconecta la alimentación antes de introducir las manos
7. No lo instales junto a una bomba de circulación que altere su flujo interno

### Funcionamiento temporal sin copa

La copa es desmontable y el motor puede producir circulación y aireación sin ella, pero el Shark SKIMMER 300 no tiene un modo de funcionamiento sin recogida documentado por Sicce. El manual describe la copa como el destino de la espuma concentrada y de los contaminantes; el fabricante también la identifica como una pieza específica de «cup & cover».

Por tanto, puede utilizarse sin copa únicamente como medida temporal de intercambio gaseoso durante el ciclado, con el rebose dirigido al sump y vigilancia de salpicaduras, espuma, nivel y acumulación de sal. En ese estado no se debe considerar que el equipo esté retirando materia orgánica de forma controlada. No se dejará funcionando sin copa sin supervisión ni se utilizará así como instalación normal de maduración.

La prioridad será mantener retorno y agitación superficial suficientes. Si el funcionamiento sin copa produce espuma inestable, salpicaduras, microburbujas persistentes o cambios de nivel, se detendrá y se utilizará otra forma de aireación.

Tras aditivos, acondicionadores, adhesivos o cambios de salinidad puede producir espuma inestable o desbordamiento.

Debe alimentarse mediante una instalación protegida por diferencial de 30 mA como máximo. Solo puede trabajar sumergido, con líquidos de hasta 35 °C. El cable es de tipo Z: si se daña, el manual ordena sustituir la bomba completa, no reparar el cable.

## Mantenimiento

- Vacía y limpia la copa con frecuencia
- Limpia la toma de aire, Venturi, rotor y cámara
- Elimina depósitos calcáreos siguiendo el manual
- Revisa tubos, juntas y cable
- No utilices el cable para levantar el equipo

## Fuente interna

- [Manual oficial Shark SKIMMER 150/300](sicce-shark-skimmer-manual.pdf)

## Fuente externa

- [Sicce: Shark SKIMMER](https://www.sicce.com/es/products/protein-skimmer-pumps/shark-skimmer.html)

## Fecha de revisión

Ficha verificada el **27 de julio de 2026**.

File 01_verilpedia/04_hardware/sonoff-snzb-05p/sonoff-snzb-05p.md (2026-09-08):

# SONOFF SNZB-05P

- **Marca:** SONOFF
- **Nombre:** sensor Zigbee de fugas de agua
- **Modelo:** SNZB-05P
- **Variante adquirida:** sensor de fugas de agua y cable de detección
- **ID de variante en la tienda:** `46197343944945`
- **SKU de la variante:** `6920075779875`
- **Protocolo:** Zigbee 3.0
- **Integración recomendada:** Zigbee2MQTT con Home Assistant

## Alcance

Esta ficha documenta el **SONOFF SNZB-05P** y, en concreto, la presentación seleccionada en la URL de compra: **«Sensor de Fugas de Agua y Cable de Detección»**.

La tienda presenta dos opciones:

| Variante | ID de tienda | SKU |
| --- | --- | --- |
| Solo sensor de fugas de agua | `46197343912177` | `6920075741810` |
| Sensor de fugas de agua y cable de detección | `46197343944945` | `6920075779875` |

La denominación «Estándar» puede resultar ambigua, pero el identificador `variant=46197343944945` de la URL corresponde inequívocamente al kit con cable.

El sensor necesita una pasarela o un coordinador Zigbee. No se conecta directamente a Wi-Fi.

## Funciones

- Detección de fugas mediante las sondas inferiores.
- Detección de gotas mediante el diseño cóncavo de recogida.
- Detección extendida mediante el cable incluido.
- Alerta a partir de aproximadamente **0,5 mm** de líquido.
- Uso sobre superficies metálicas sin falsos positivos provocados únicamente por el metal, gracias a la elevación de las sondas.
- Sondas chapadas en oro para mejorar la resistencia a la corrosión.
- Protección IP67 del cuerpo del sensor.
- Aviso de batería baja y nivel porcentual de batería.
- Reenvío periódico de la alarma mientras persiste el agua.
- Actualizaciones de firmware OTA.
- Integración local con Zigbee2MQTT y ZHA.

El sensor únicamente detecta la presencia o ausencia de agua. No mide la cantidad, la profundidad, el caudal ni la localización exacta del punto mojado a lo largo del cable.

## Principio de detección

La alarma se activa cuando el agua cierra eléctricamente el circuito entre las sondas. El cuerpo incorpora:

- Sondas elevadas para detectar una lámina de agua de unos 0,5 mm.
- Una concavidad que recoge gotas para detectar goteos antes de que se forme un charco.
- Un contacto magnético para conectar el cable detector.

El cable trenzado detecta humedad en cualquier punto sensible de su longitud. Puede rodear una lavadora, un calentador, una tubería o cubrir el perímetro de una zona.

## Especificaciones técnicas

| Especificación | Valor |
| --- | --- |
| Modelo | SNZB-05P |
| MCU | EFR32MG22 |
| Alimentación | 3 V CC |
| Batería | 1 × CR2477, no recargable |
| Autonomía declarada | Hasta 5 años con 50 activaciones diarias |
| Protocolo | Zigbee 3.0 |
| Alcance declarado | Hasta 130 m en espacio abierto |
| Grado de protección | IP67 |
| Material de la carcasa | PC + ABS resistente a rayos UV |
| Dimensiones | 48 × 48 × 21,6 mm |
| Peso neto | 34,3 g sin batería |
| Temperatura de funcionamiento | −10 a 60 °C |
| Humedad de funcionamiento del sensor | 0–100 % HR |
| Humedad recomendada para el cable A4 | 0–80 % HR, sin condensación |
| Altitud de funcionamiento | Menos de 5000 m |
| Tiempo de emparejamiento | 180 s |
| Lugar de uso | Interiores |
| Norma indicada | EN 62368-1 |
| Certificaciones declaradas | CE, FCC, ISED y RoHS |

La autonomía es una estimación de laboratorio y variará con la calidad de la señal, la temperatura, las activaciones, las retransmisiones y la batería empleada.

## Contenido de esta presentación

- Sensor SONOFF SNZB-05P.
- Cable de detección de fugas de agua.
- Batería CR2477 instalada con lengüeta aislante, según el procedimiento de puesta en marcha.
- Guía rápida.

No se ha encontrado una longitud oficial inequívoca para el cable incluido en las fuentes consultadas. Debe medirse en la unidad recibida antes de documentarla.

## Ubicaciones recomendadas

- Debajo de fregaderos y lavabos.
- Junto a calentadores y acumuladores de agua.
- Cerca de lavadoras y lavavajillas.
- Próximo a bombas de achique o sumideros.
- Alrededor de tuberías y válvulas.
- En baños, cocinas, sótanos, bodegas y áticos.
- Bajo muebles o electrodomésticos donde una fuga pueda permanecer oculta.
- Cerca de una bañera para detectar desbordamientos.

Para un punto concreto puede utilizarse el sensor por sí solo. Para cubrir un perímetro, una zona amplia o un lugar estrecho resulta preferible el cable.

## Instalación física

### Sensor sin cable

1. Elige una superficie estable donde el agua probable pueda alcanzar las sondas.
2. Coloca el sensor horizontalmente con las sondas hacia el suelo.
3. Comprueba que la concavidad superior quede expuesta a posibles goteos.
4. Evita lugares donde pueda desplazarse, quedar enterrado o ser golpeado.
5. Realiza una prueba controlada con una pequeña cantidad de agua.

### Sensor con cable

1. Conecta el terminal del cable al contacto magnético del sensor.
2. Extiende el cable por la zona que se desea vigilar, sin tensarlo.
3. No tires, retuerzas ni dobles bruscamente el cable.
4. Evita colocarlo en una zona con condensación habitual o humedad ambiental superior a la recomendada.
5. Prueba varios puntos del cable con una pequeña cantidad de agua.
6. Seca completamente el cable después de cada prueba.

### Varios cables

SONOFF permite conectar varios cables detectores en serie y no declara un límite de longitud total. Una longitud grande puede dificultar localizar el punto exacto de la fuga, aumentar la exposición a humedad ambiental y complicar el diagnóstico; conviene probar toda la instalación después de cada ampliación.

Puede utilizarse un alargador USB Type-C común entre dos cables detectores. Un cable Type-C que se haya mojado en esta instalación no debe reutilizarse posteriormente para cargar dispositivos.

## Resistencia al agua y mantenimiento

El cuerpo tiene clasificación **IP67**, que implica protección frente al polvo y la inmersión temporal en las condiciones normalizadas del ensayo. No significa que esté diseñado para permanecer sumergido indefinidamente.

Después de una detección:

1. Corrige y seca la fuga.
2. Retira el sensor y seca las sondas y la carcasa.
3. Si se ha mojado el cable, déjalo secar por completo antes de reutilizarlo.
4. Comprueba que Home Assistant vuelva a mostrar el estado seco.
5. Ejecuta una prueba controlada antes de devolverlo a servicio.

Una humedad ambiental excesiva o la condensación pueden provocar falsas detecciones en el cable.

## Batería y seguridad

La CR2477 es una pila de botón de litio de 3 V y no debe recargarse.

- Mantén las pilas nuevas y usadas fuera del alcance de los niños.
- La ingestión puede causar quemaduras internas graves en unas dos horas y puede ser mortal.
- Si se sospecha ingestión o introducción en el cuerpo, solicita atención médica inmediata.
- No descargues la pila por la fuerza, la desmontes, la aplastes, la cortes, la incineres ni la calientes por encima de 60 °C.
- No utilices un tipo de batería distinto.
- Respeta la polaridad.
- Si la tapa no cierra de forma segura, deja de usar el producto, retira la pila y mantenla alejada de los niños.
- Retira la batería si el dispositivo no va a utilizarse durante mucho tiempo.
- Recicla la pila de acuerdo con la normativa local; no la arrojes a la basura doméstica ni al fuego.

### Sustitución

1. Gira y retira la tapa inferior.
2. Levanta la cubierta de la batería por ambos lados.
3. Sustituye la CR2477 respetando la polaridad.
4. Cierra completamente la cubierta y la tapa para conservar la protección física.
5. Verifica en Home Assistant que se actualiza el nivel de batería.
6. Realiza una prueba de fuga.

## Indicador y botón

### Indicador LED rojo

| Estado | Significado |
| --- | --- |
| Parpadeo lento durante 180 s | Modo de emparejamiento |
| Encendido durante 3 s y después apagado | Emparejamiento correcto |
| Deja de parpadear y se apaga | Fallo o tiempo agotado |
| Un destello rápido tras pulsar | No está añadido a una pasarela |
| Dos destellos rápidos tras pulsar | Está añadido, en línea y dentro de alcance |
| Parpadeo lento durante 30 s | Comunicación anómala |

### Botón

| Acción | Función |
| --- | --- |
| Pulsación breve | Comprueba la comunicación y el alcance Zigbee |
| Mantener pulsado 5 s | Entra en modo de emparejamiento durante 180 s |

Al encenderse por primera vez mediante la retirada de la lengüeta aislante entra en modo de emparejamiento.

## Integración prioritaria: Zigbee2MQTT

Zigbee2MQTT reconoce expresamente el **SONOFF SNZB-05P** y permite utilizarlo localmente, sin registrar una cuenta eWeLink.

### Requisitos

- Home Assistant.
- Zigbee2MQTT actualizado.
- MQTT configurado.
- Coordinador Zigbee compatible, por ejemplo ZBDongle-P o ZBDongle-E.

### Emparejamiento

1. Retira la tapa inferior y la lengüeta aislante de la batería.
2. Coloca el sensor cerca del coordinador.
3. En Zigbee2MQTT, activa **Permitir unirse**.
4. Mantén pulsado el botón durante cinco segundos.
5. Comprueba que el LED parpadea lentamente.
6. Espera a que la entrevista termine y se identifique como `SNZB-05P`.
7. Asígnale un nombre que incluya la ubicación.
8. Desactiva **Permitir unirse**.
9. Colócalo en la ubicación definitiva y pulsa brevemente el botón.
10. Dos destellos rápidos confirman que puede comunicarse con la red Zigbee.

### Entidades expuestas

| Propiedad | Descripción | Valores | Acceso |
| --- | --- | --- | --- |
| `water_leak` | Estado de fuga | `true` con agua, `false` en seco | Solo publicado |
| `battery` | Batería restante | 0–100 % | Lectura |
| `battery_low` | Aviso de batería casi agotada | `true`, `false` | Solo publicado |

Zigbee2MQTT también declara compatibilidad con **OTA**.

Ejemplo de mensaje publicado:

```json
{
  "water_leak": true,
  "battery": 96,
  "battery_low": false,
  "linkquality": 120
}
```

El valor `linkquality` es orientativo y depende de la red; no aparece entre las tres funciones específicas del dispositivo.

## Integración alternativa: ZHA

SONOFF declara compatibilidad con ZHA mediante ZBDongle-P o ZBDongle-E, incluyendo:

- Estado de fuga.
- Historial mediante Home Assistant.
- Automatizaciones locales.
- Actualización OTA.

Para añadirlo:

1. Ve a **Ajustes → Dispositivos y servicios → ZHA**.
2. Selecciona **Añadir dispositivo**.
3. Mantén pulsado el botón del sensor durante cinco segundos.
4. Espera a que ZHA complete la entrevista.
5. Nombra el dispositivo según su ubicación y prueba la detección.
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

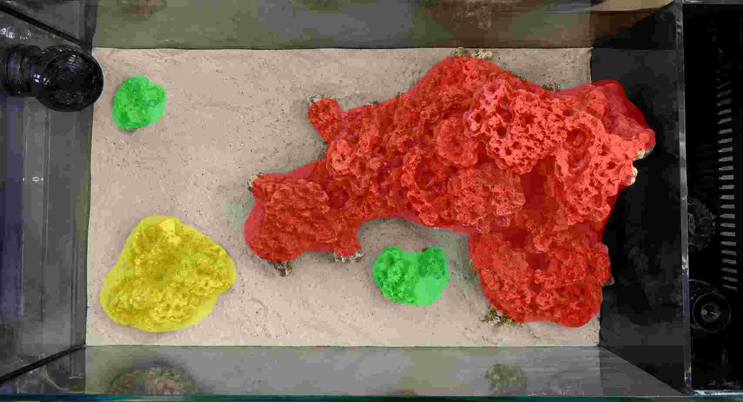
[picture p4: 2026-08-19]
02_configuracion/02_hardscape/hardscape-concepto-superior.jpg

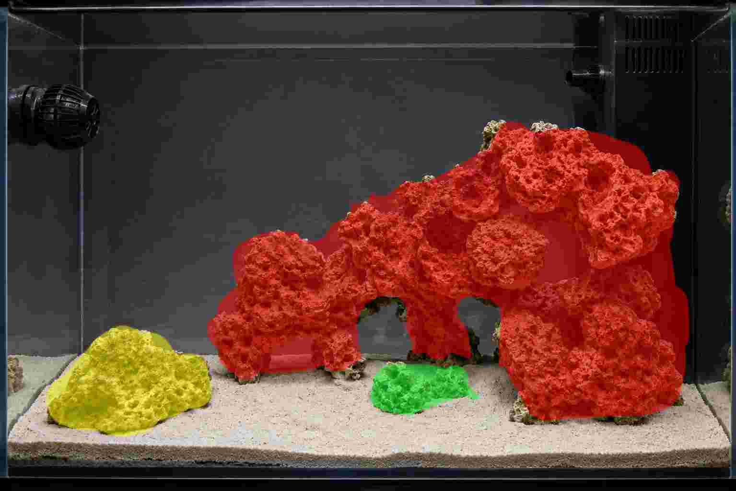
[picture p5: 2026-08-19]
02_configuracion/02_hardscape/hardscape-concepto-frontal.jpg

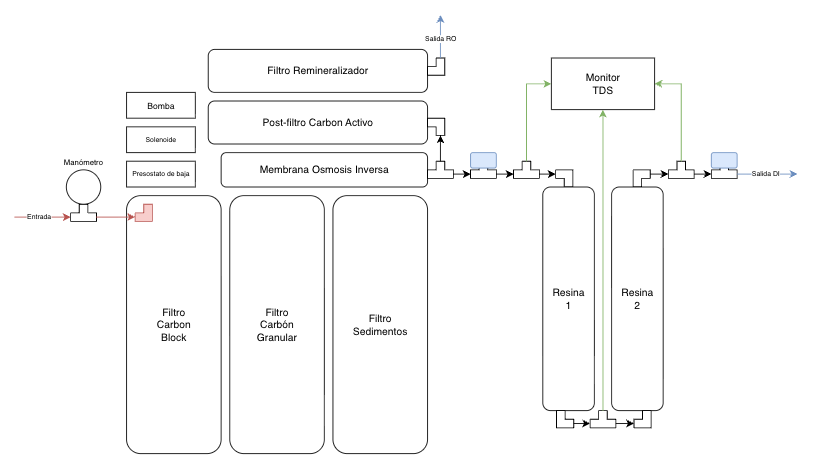
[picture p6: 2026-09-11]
01_verilpedia/04_hardware/di-ro/ro-di.png

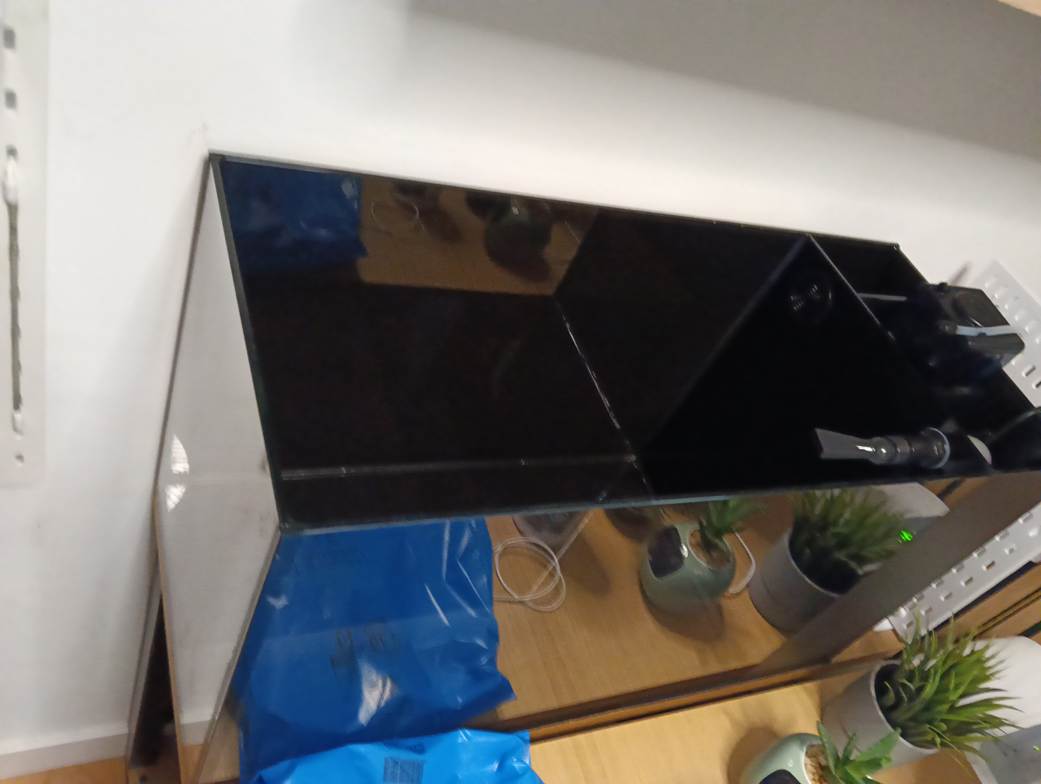
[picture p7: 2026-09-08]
01_verilpedia/04_hardware/urna/vista-lateral-compartimento-tecnico.jpg

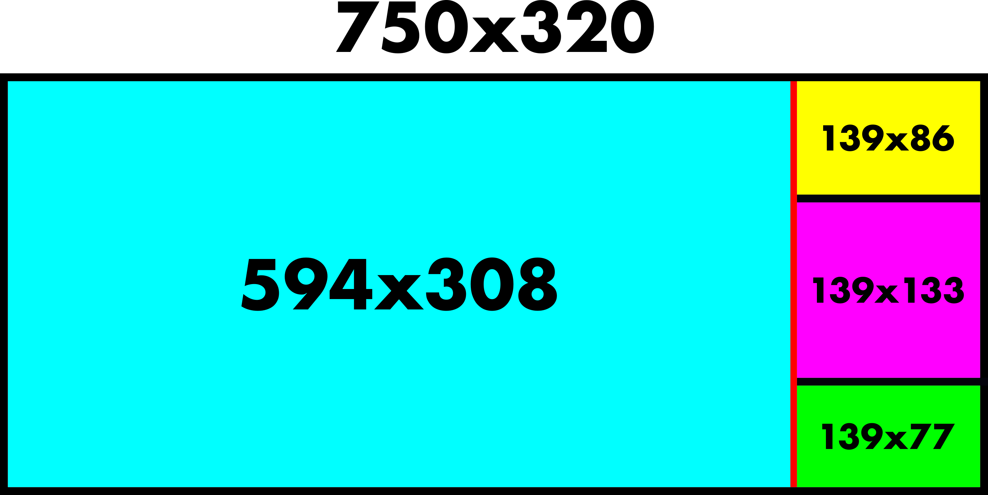
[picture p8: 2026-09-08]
01_verilpedia/04_hardware/urna/urna.png

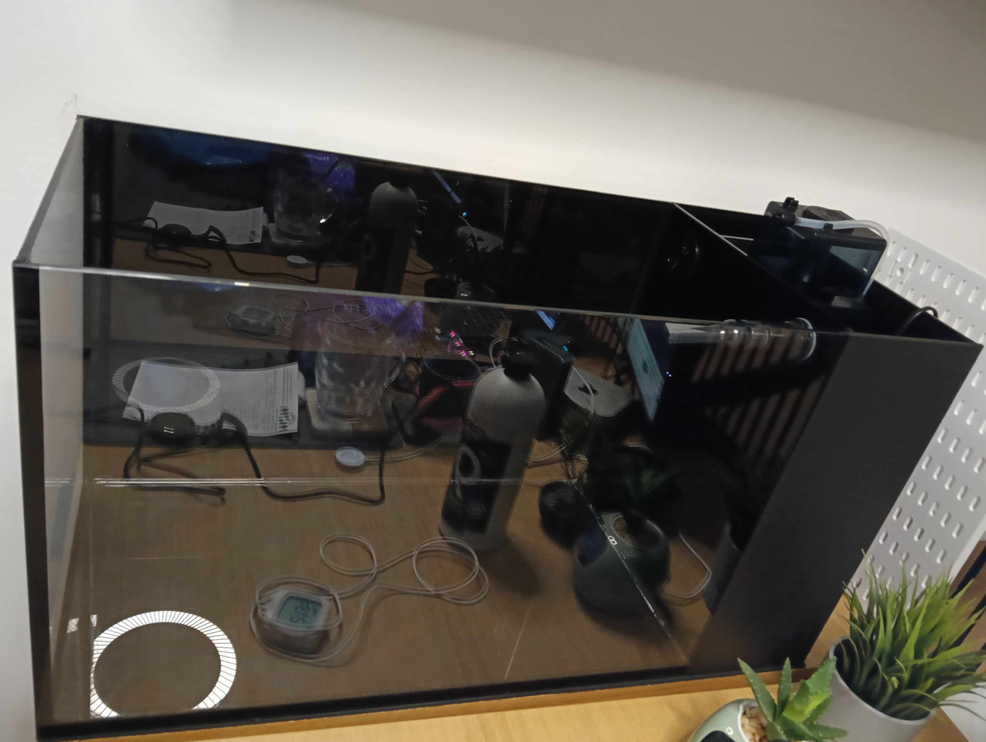
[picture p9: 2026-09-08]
01_verilpedia/04_hardware/urna/vista-general-urna-vacia.jpg

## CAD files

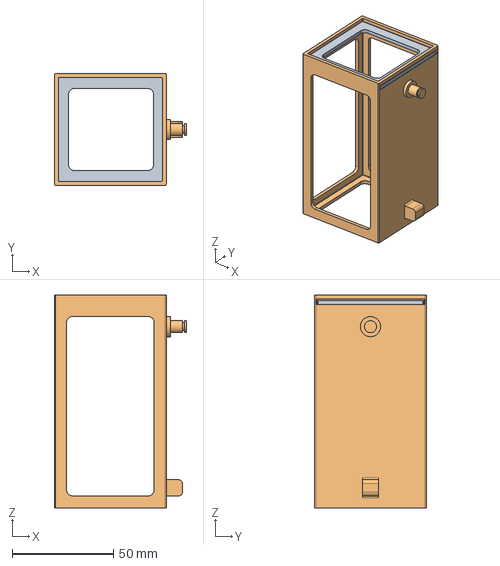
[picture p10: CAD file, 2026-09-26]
03_pendientes/disenos-3d/bactoflex-mini/modular-50x50x100/bactoflex-50x50x100.FCStd
65.3 x 55.3 x 105.3 mm
TAPA_BACTOFLEX
CANASTA_BACTOFLEX

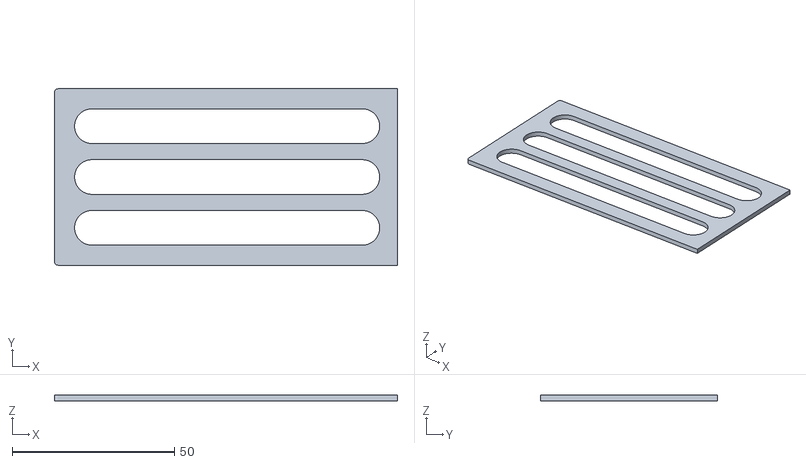
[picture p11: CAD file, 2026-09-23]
03_pendientes/disenos-3d/bactoflex-mini/version-107x57x105/impresion/veril-bactoflex-tapa.stl
105.7 x 54.4 x 1.70

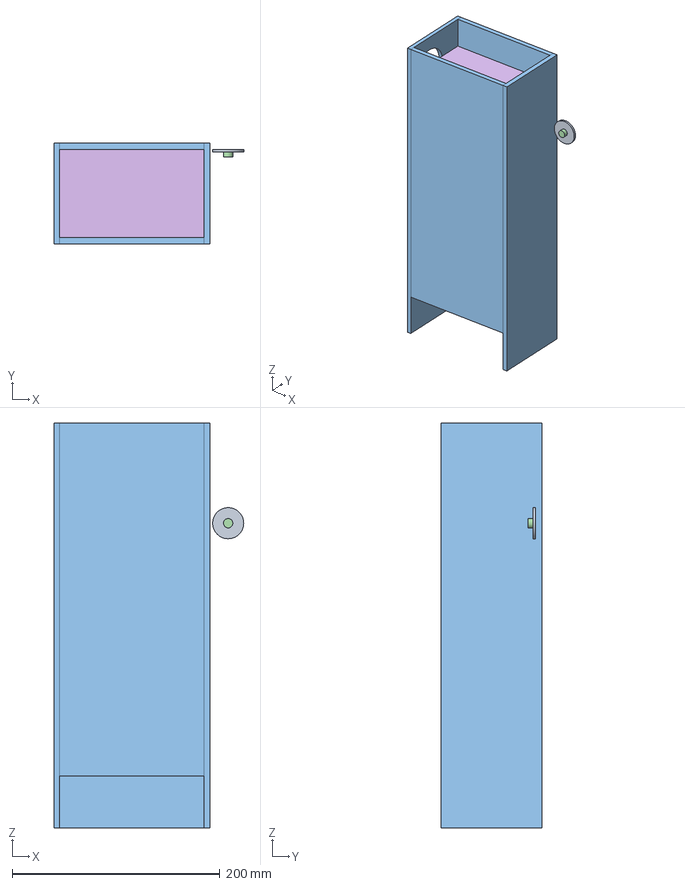
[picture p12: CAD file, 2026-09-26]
03_pendientes/disenos-3d/bactoflex-mini/version-107x57x105/veril-bactoflex.validado-20260925-151010.FCStd
182.5 x 97.0 x 390.0 mm
NO ACTIVO — Base de apoyo de ventosa — derecho superior001
BactoFlex — referencia dimensional, no imprimir
Cámara de entrada de referencia — conjunto de vidrios, no imprimir
Cesta BactoFlex — sólido único imprimible — 3 huecos frontales
NO ACTIVO — Columna de cierre trasera — hueco extremo derecho
NO ACTIVO — Columna de cierre trasera — hueco extremo izquierdo
Copa ventosa ref. Ø30 / ojal Ø4 mm — no imprimir
Copa ventosa ref. Ø30 / ojal Ø4,6 mm — no imprimir
Copa ventosa ref. Ø30 / ojal Ø6 mm — no imprimir
Cuello ventosa ref. Ø4 mm
Cuello ventosa ref. Ø4,6 mm
Cuello ventosa ref. Ø6 mm
NO ACTIVO — Pata de apoyo inferior contra cristal — derecha
Superficie de agua de referencia — no imprimir
Tapa BactoFlex — final perforada, imprimir aparte
NO ACTIVO — Tetón de ventosa — derecho superior001
Ventosa Ø5 — fuente para enlaces superiores, no imprimir

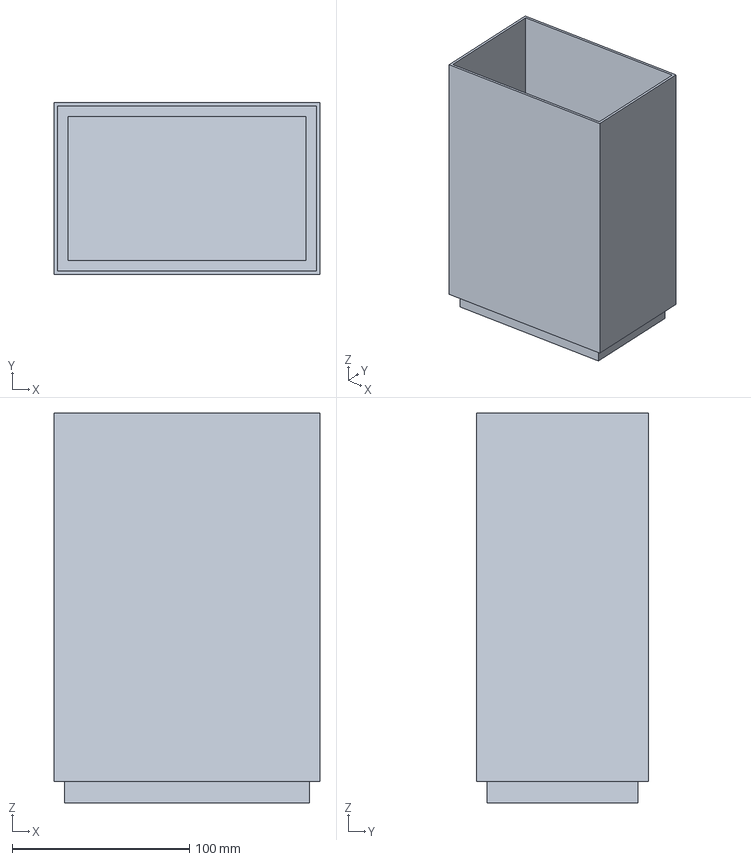
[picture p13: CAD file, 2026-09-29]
03_pendientes/disenos-3d/chaeto-box/chaeto-box-parametrico.FCStd
150.0 x 97.0 x 220.0 mm

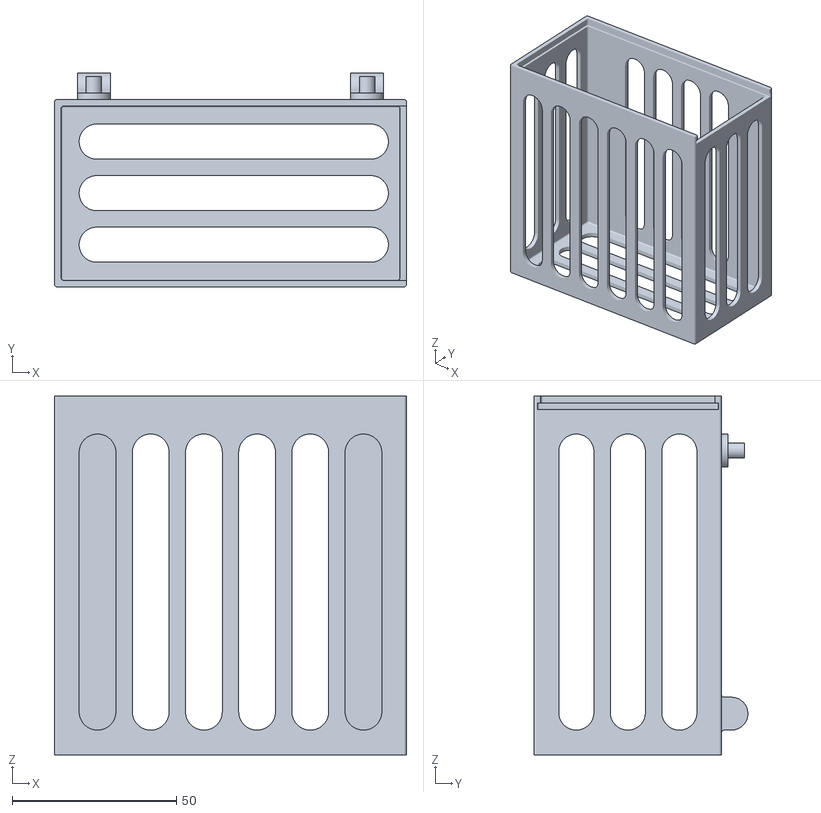
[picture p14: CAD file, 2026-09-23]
03_pendientes/disenos-3d/bactoflex-mini/version-107x57x105/impresion/veril-bactoflex-jaula.stl
107.0 x 65.0 x 109.0

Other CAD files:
03_pendientes/disenos-3d/bactoflex-mini/version-107x57x105/veril-bactoflex.FCStd
03_pendientes/disenos-3d/bactoflex-mini/version-107x57x105/impresion/veril-bactoflex-tapa--kp3-winkle-petg.3mf
03_pendientes/disenos-3d/bactoflex-mini/version-107x57x105/impresion/veril-bactoflex-jaula--kp3-winkle-petg.3mf

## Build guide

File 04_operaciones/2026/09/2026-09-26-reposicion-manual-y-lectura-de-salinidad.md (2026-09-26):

# 2026-09-26 — Reposición manual y lectura de salinidad

## Estado

Operación documentada con evidencia física comunicada por el propietario y
telemetría contextual de Home Assistant.

## Ejecución comunicada

Como quedaba poca agua en la cámara C3, se añadió agua al sistema desde el
barril. El barril contenía agua salada. Su volumen se estimó en **unos 3,6 L**
antes de la operación y **unos 1,75 L** después.

El volumen añadido comunicado por el propietario es de aproximadamente
**1,85 L**, calculado restando el volumen final al inicial del barril:
3,6 L − 1,75 L. La cifra es aproximada porque ambos volúmenes de partida se
estimaron.

El propietario precisó que hizo la reposición y la lectura del refractómetro
unos minutos antes de comunicarlo. No se conoce el minuto exacto.

## Resultado observado

Después de la reposición, el refractómetro seguía indicando una lectura fuera
de escala, aproximadamente **1,032** según la notación comunicada. La lectura
se conserva como observación del instrumento, no como una medida validada de
salinidad: no se aportaron la escala concreta, la temperatura de la muestra ni
la verificación de calibración o contraste.

El propietario añadió que, después de rellenar, el nivel de agua en C3 quedó a
**117 mm del borde superior**. Se registra como medición comunicada; no se
indicó el instrumento ni el punto exacto de referencia en el borde.

## Telemetría asociada de Home Assistant

La consulta de Home Assistant se realizó poco después del aviso. Las marcas
horarias se muestran en hora local de Canarias (WEST, UTC+1).

| Variable | Entidad | Valor observado | Momento | Alcance |
| --- | --- | ---: | --- | --- |
| Temperatura del agua | `sensor.0xa4c13810b72fffff_temperature` (`off-sns-05`) | 28,2 °C | Estado sin cambio desde 17:14:32; mensaje Zigbee más reciente a las 17:24:34 | Contexto térmico próximo a la reposición; el mensaje reciente no implica que la cifra de temperatura haya cambiado. |
| Antigüedad del mensaje de `off-sns-05` | `sensor.veril_water_sensor_age` | 0,4 min | 17:25 | Confirma recepción reciente de telemetría, no una nueva lectura numérica de temperatura. |
| Tendencia del agua, ventana 30 min | `sensor.veril_velocidad_termica_agua_30_min` | +0,025 °C/h | 17:14:32 | Último valor calculado registrado; no acredita el efecto de la reposición. |
| Tendencia del agua, ventana 60 min | `sensor.veril_velocidad_termica_agua_60_min` | +0,026 °C/h | 17:14:32 | Último valor calculado registrado; no acredita el efecto de la reposición. |
| Temperatura ambiente mediana del despacho | `sensor.veril_room_temperature_median` | 30,4 °C | 17:18:41 | Contexto ambiental; no mide el nivel de C3 ni la salinidad. |
| Gravedad específica del monitor `off-sns-09` | `sensor.0xa4c138ed21676ef4_sg` | 1,067 | 16:29:23 | Valor de más de 50 min antes de la reposición aproximada; no es contemporáneo ni valida el refractómetro. |

Las entidades de salinidad (50 ‰), TDS (13.000 ppm) y EC (20.000 μS/cm) de
`off-sns-09` conservaban estados desde el 24 de septiembre, por lo que no se
consideran lecturas de esta operación. No se identificó una entidad de Home
Assistant que mida el nivel de C3; los **117 mm** son la medición comunicada
por el propietario.

## Interpretación y límites

Home Assistant registraba 28,2 °C en el agua cerca de la operación y telemetría
reciente de `off-sns-05`; no ofrece una medición del nivel de C3. El monitor
`off-sns-09` presentaba una gravedad específica de 1,067 con más de 50 min de
antigüedad y otras lecturas de salinidad/TDS/EC de dos días antes. Estos datos
no corroboran la lectura manual aproximada de 1,032, que seguía fuera de escala,
ni permiten establecer la salinidad final con precisión. La cota final de
117 mm tampoco determina por sí sola el volumen añadido, pues no se registró
la cota inicial ni la geometría de llenado de C3.

## Pendientes derivados

- [ ] Comprobar el refractómetro con el procedimiento y una referencia adecuados, y repetir la lectura dentro de su escala
- [ ] Registrar en futuras reposiciones el volumen transferido y el nivel de C3 antes y después

## Fuentes internas

- [Medición manual de salinidad y química inicial del 20 de septiembre](2026-09-20-medicion-manual-salinidad-y-quimica.md)
- [Parámetro de salinidad](../../../01_verilpedia/03_parametros/salinidad.md)

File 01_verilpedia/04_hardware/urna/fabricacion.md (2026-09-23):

# Fabricación de la urna

## Configuración

- Fabricante o responsable comercial: **Elite Reef Kanarias S.L.**
- Tipo: Urna marina AIO artesanal con compartimento técnico lateral derecho
- Disposición: Longitudinal tipo península, junto a pared
- Medida exterior: **750 × 320 × 400 mm**
- Silicona: **Negra**

## Piezas

| Pieza | Medida / material |
| --- | --- |
| Base | **736 × 306 mm**, vidrio transparente de **10 mm** |
| Frontal | **750 × 400 mm**, vidrio transparente de **6 mm** |
| Trasera | **750 × 400 mm**, vidrio transparente de **6 mm** |
| Laterales cortos | **306 × 400 mm**, vidrio de **6 mm** |
| Separador técnico | Lacobel negro de **5 mm** con dos perforaciones circulares |
| Separadores internos | Dos piezas de vidrio de aproximadamente **137 × 340 × 6 mm** |

La base queda encajada dentro del perímetro formado por frontal, trasera y laterales. Las siguientes medidas se han observado directamente en la urna terminada:

```text
Display interior: 594 × 308 mm
Sump interior: 139 × 296 mm
Cámara Entrada: 139 × 86 × 390 mm
Cámaras Skimmer y Retorno en planta: 139 × 134 mm + 139 × 77 mm
```

La medida exterior nominal es de **750 × 320 × 400 mm**. En el sentido de los 320 mm, la parte superior puede ser aproximadamente **1–2 mm más estrecha** que la base por la silicona.

## Margen de silicona para las piezas internas

Como criterio aproximado de fabricación, se reserva **1 mm de silicona por cada lado** de las piezas que quedan entre paredes. En el ancho del sump, la medida interior observada es de **139 mm**, por lo que el ancho calculado de cada separador es:

```text
139 mm − 1 mm − 1 mm = 137 mm
```

Con este criterio, cada separador interno queda documentado como una pieza de aproximadamente **137 × 340 × 6 mm**. La medida final debe comprobarse en la urna antes de cortar el vidrio, especialmente por la variación de la silicona entre la base y la parte superior.

## Separador y perforaciones

El separador Lacobel negro de **5 mm** oculta la zona técnica. Incluye dos perforaciones circulares: una superior para la entrada del circuito y otra inferior para el retorno. La orientación de la cara lacada, la protección de los cantos y la compatibilidad del conjunto con agua salada forman parte de la revisión de montaje.

La perforación de entrada a la cámara **Entrada** tiene **50 mm de diámetro**. Su posición está indicada a **17 mm del borde superior** y a **30 mm de la pared trasera**. Estas referencias se conservan tal como fueron medidas, sin asumir que correspondan al centro geométrico o al borde de la perforación.

Los dos separadores internos son de vidrio de aproximadamente **137 × 340 × 6 mm**. El primero llega hasta la parte superior y deja un paso inferior de aproximadamente **50 mm**. El segundo llega hasta el fondo y deja un paso superior de aproximadamente **50 mm**. La altura resulta de **400 − 10 − 50 = 340 mm**, considerando el cristal de fondo de **10 mm**.

Esta altura de **340 mm** corresponde a los separadores internos y no a la cámara Entrada. La cámara Entrada llega hasta el borde superior de la urna y su altura interior nominal es **390 mm**, calculada como **400 mm de altura exterior menos los 10 mm del fondo**.

## Apoyo

La base se apoya sobre una pieza continua de EVA BIBODU de **75 × 32 cm** y **5 mm**, recortada de un rollo de **150 × 32 cm** y densidad declarada de **80 kg/m³**. La ficha del material está en [Espuma de apoyo](espuma.md).

## Vinilado

El AIO, la base y la parte trasera llevan un vinilado negro con textura.

## Pendientes de montaje

- Altura de entrada y retorno
- Pulido de los cantos de las perforaciones
- Orientación y protección del Lacobel
- Compatibilidad del vinilado con las superficies de aplicación
- Aceptación de la EVA de 5 mm como apoyo
- Nivelación final del tablero

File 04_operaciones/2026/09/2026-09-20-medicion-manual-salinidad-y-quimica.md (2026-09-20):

# 2026-09-20 — Medición manual de salinidad y química inicial

## Estado

Operación documentada con observación manual y telemetría contextual.

## Contexto

El ciclado de Veril todavía no ha comenzado. Hasta disponer del sistema RO/DI,
se han realizado varias reposiciones con agua salada; el usuario identifica
este hecho como explicación coherente de la concentración progresiva de la
salinidad. No se registraron los volúmenes ni las fechas de cada reposición.

## Mediciones manuales observadas

### Salinidad

Se realizaron varias lecturas con el refractómetro D-D The Aquarium Solution
AQPR001. La densidad específica observada fue aproximadamente **1,031**. El
resultado se comunicó como coherente entre repeticiones y con las reposiciones
realizadas con agua salada.

No se registraron la temperatura de la muestra, la verificación del cero, una
solución patrón ni la escala de lectura. Por ello, esta cifra describe una
observación repetida, pero no constituye todavía una aceptación metrológica de
la salinidad ni una equivalencia automática en ppt o salinidad práctica.

### Tetra Test 7 en 1

La tira Tetra 7 en 1 dio las siguientes lecturas comunicadas:

| Parámetro | Resultado | Unidad o escala |
| --- | ---: | --- |
| Nitrato, NO₃ | 0 | mg/L |
| Nitrito, NO₂ | 0 | mg/L |
| Dureza general, GH | 8 | °dH |
| Alcalinidad carbonatada, KH | 6 | °dH |
| pH | 7,6 | escala de pH |
| Cloro, Cl₂ | 0 | mg/L |

Las tiras se conservan como caracterización orientativa. En agua marina, el GH
no se utilizará como control operativo y las lecturas de pH y KH requerirán
confirmación mediante métodos adecuados antes de modificar la química del
sistema. Esta medición no incluye nitrógeno amoniacal.

## Telemetría asociada de Home Assistant

| Variable | Entidad | Valor observado | Momento de la lectura | Alcance |
| --- | --- | ---: | --- | --- |
| Temperatura del agua | `sensor.0xa4c13810b72fffff_temperature` | 27,8 °C | 2026-09-20 18:35 WEST | Lectura del termómetro con sonda `off-sns-05` situado en la cámara Skimmer; contexto térmico, no validación de los tests manuales. |

## Interpretación limitada

La densidad específica observada es alta respecto de la consigna prevista
`S_P = 35`, pero no se corregirá con una intervención brusca ni se iniciará el
ciclado a partir de esta medición. Antes del inicio siguen pendientes el
montaje y la aceptación del RO/DI, la reposición exclusiva con agua RO/DI y una
línea base con métodos adecuados para salinidad, pH, alcalinidad, nitrógeno
amoniacal y nitrito.

## Pendientes derivados

- [ ] Montar y aceptar el sistema RO/DI antes de una corrección controlada de salinidad.
- [ ] Registrar las futuras reposiciones con fecha, volumen y tipo de agua.
- [ ] Limpiar el prisma, comprobar el cero y contrastar el refractómetro con una solución patrón marina antes de aceptar la salinidad.
- [ ] Repetir la línea base de pH y alcalinidad con métodos adecuados antes del ciclado.
- [ ] Medir nitrógeno amoniacal al iniciar la línea base de ciclado.

## Fuentes internas

- [Comprobación de salinidad del 13 de septiembre](2026-09-13-comprobacion-salinidad-refractometro.md)
- [Tetra Test 7 en 1](../../../01_verilpedia/05_productos/14_tetra-test-7-en-1/tetra-test-7-en-1.md)
- [Refractómetro D-D AQPR001](../../../01_verilpedia/05_productos/06_dd-aquarium-solution-aqpr001/dd-aquarium-solution-aqpr001.md)
- [Plan de ciclado](../../../03_pendientes/ciclado/plan.md)

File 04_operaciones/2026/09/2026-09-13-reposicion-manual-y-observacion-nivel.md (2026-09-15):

# 2026-09-13 — Reposición manual y observación del nivel

## Estado

Operación documentada sin telemetría pertinente o disponible

## Ejecución observada

El 13 de septiembre se volvió a añadir una cantidad no medida de agua al
sistema. La cantidad y la composición del agua incorporada no quedaron
registradas.

## Resultado observado el 15 de septiembre

Tras varios llenados observados, incluido uno excesivo, el sistema ha vuelto a
estabilizar el nivel del display aproximadamente a **37 mm** por debajo del
borde superior de la urna. La repetición confirma esa cota como límite natural
de llenado en la configuración hidráulica observada. Las cantidades y fechas
individuales de los llenados anteriores no quedaron registradas.

Este resultado confirma el nivel estabilizado del display, pero no cuantifica
el volumen operativo real ni acredita el comportamiento tras una parada o un
reinicio del retorno.

## Telemetría asociada de Home Assistant

No se incorporó telemetría. No hay una entidad de nivel de agua identificada
para Veril y el cliente local de consulta de Home Assistant indicado por el
procedimiento no está disponible en su ruta documentada. La observación física
anterior no queda corroborada por Home Assistant.

## Pendientes derivados

- [ ] Registrar el volumen y la composición de cualquier reposición posterior
- [ ] Repetir la medición de la distancia al borde con el retorno en funcionamiento y anotar también los niveles de las cámaras
- [ ] Medir el volumen operativo real antes de usarlo para dosificar o aceptar el ciclado

## Fuentes internas

- [Ajuste de nivel, retorno y sensor del 6 de septiembre](2026-09-06-ajuste-nivel-retorno-y-sensor.md)
- [Comprobación de salinidad con refractómetro del 13 de septiembre](2026-09-13-comprobacion-salinidad-refractometro.md)
- [Plan de ciclado](../../../03_pendientes/ciclado/plan.md)

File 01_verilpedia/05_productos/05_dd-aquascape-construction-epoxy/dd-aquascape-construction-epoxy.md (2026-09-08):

# D-D Aquascape Construction Epoxy Coralline Algae

## Identificación

| Campo | Dato |
| --- | --- |
| Marca | D-D |
| Producto | D-D Aquascape Construction Epoxy Coralline Algae |
| Presentación comercial localizada | 113 g / 4 oz |
| Estado en Veril | Adquirido |

## Especificaciones declaradas

| Campo | Dato |
| --- | --- |
| Tipo | Masilla epoxi de dos componentes |
| Aplicación | Agua dulce, agua salada y aplicaciones bajo el agua |
| Color documentado | Coralline Algae, variante púrpura |
| Curado semiduro | Aproximadamente 3–4 horas a 20–25 °C, según el fabricante |
| Curado completo | Aproximadamente durante la noche, según el fabricante |

## Función documentada

Masilla epoxi de dos componentes para aquascaping, uniones y acabados. D-D la describe como adecuada para unir roca, fijar frags, crear bases y realizar reparaciones en aplicaciones de agua dulce o salada. La mezcla, el tiempo de trabajo, el curado y la preparación deben seguir las instrucciones del envase.

La variante Coralline Algae está formulada para adquirir un color parecido al de las algas coralinas durante el curado bajo el agua. D-D advierte que una manipulación excesiva dentro de un acuario poblado puede liberar cargas y enturbiar el agua; si ocurre, se debe detener la manipulación y favorecer la oxigenación.

## Uso en Veril

Queda disponible como alternativa para uniones o acabados que requieran epoxi. No es el producto utilizado para la fijación estructural documentada del hardscape, que se realizó con AF Stone Fix.

## Límites

- No se debe utilizar sin confirmar el curado indicado y la compatibilidad con el agua marina
- Su presencia entre los productos adquiridos no implica que sea necesario incorporarlo al montaje
- La resistencia de una unión depende también de la geometría, la preparación y el apoyo de las piezas
- La masilla no es un adhesivo de capa fina: no debe sustituir a un adhesivo adecuado cuando las superficies no permiten una unión por volumen
- La manipulación de grandes voladizos requiere apoyo hasta que la masilla haya endurecido

## Fuentes

- Etiqueta e instrucciones del envase adquirido
- [D-D: Aquascape Construction Epoxy](https://www.theaquariumsolution.com/product/3036/105)
- [D-D: advertencia de uso de Aquascape](https://www.theaquariumsolution.com/aquascape-epoxy-warning-against-incorrect-use)
- [Documentación del hardscape](../../../02_configuracion/02_hardscape/README.md)

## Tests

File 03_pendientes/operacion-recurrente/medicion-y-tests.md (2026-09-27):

# Plan transversal de medición y selección de tests

## Decisión de método

Veril utilizará métodos diferenciados según la fase y el parámetro. Los tests
de gotas Salifert son la base propuesta para los parámetros cuyo seguimiento
inicial requiere una titulación o una escala visual; un fotómetro no se adopta
por defecto para todos los parámetros.

Esta decisión no declara que los candidatos pendientes estén adquiridos ni que
un resultado aislado sea suficiente para corregir el agua.

## Opciones por magnitud medida

Los precios son orientativos para España, consultados el **20 de septiembre de
2026**, sin portes. Los precios Hanna son del instrumento inicial: reactivos,
cubetas, patrones, sondas o soluciones de mantenimiento se compran aparte.
Los equipos multiparámetro aparecen solo en las magnitudes que cubren.

El Tetra Test 7 en 1 se conserva como referencia inicial orientativa, pero no
es un método de aceptación para pH, KH, nitrógeno o nutrientes. Las imágenes
comunicadas el 20 de septiembre identifican como candidatos concretos el
Salifert KH/Alk Profi Test y el Salifert pH Profi Test; al recibirlos se
registrarán lote, caducidad, escala e instrucciones.

### [Nitrógeno amoniacal (TAN)](../../01_verilpedia/03_parametros/amonio.md)

| Alternativa | Tipo | Cuándo | Estado / caducidad | Precio aprox. | Mejora real frente a la opción anterior |
| --- | --- | --- | --- | --- | --- |
| [Salifert Ammonia NH3 Profi Test](../../01_verilpedia/05_productos/12_salifert-ammonia-nh3/salifert-ammonia-nh3.md) | Gotas colorimétricas | Ciclado e incidencias de biofiltración | **Disponible**; **10/2027** | ~10 € | Método de referencia inicial; mide nitrógeno amoniacal total, no NH3 libre aislado. |
| Hanna HI784 | Fotómetro marino | Solo si se necesitan tendencias muy bajas o mayor repetibilidad | Pendiente | ~80 € | Quita subjetividad visual y entrega un valor numérico. No cambia el criterio de aceptación del ciclado, por lo que no compensa ahora. |
| Hanna HI97115 Marine Master | Fotómetro multiparámetro con reactivos | Solo si se consolida un programa amplio de análisis | Pendiente | ~485 € sin IVA | Añade siete parámetros más, no mejora por sí mismo la interpretación de TAN. |

### [Nitrito (NO2)](../../01_verilpedia/03_parametros/nitrito.md)

| Alternativa | Tipo | Cuándo | Estado / caducidad | Precio aprox. | Mejora real frente a la opción anterior |
| --- | --- | --- | --- | --- | --- |
| [Salifert NO2 Profi Test](../../01_verilpedia/05_productos/13_salifert-no2/salifert-no2.md) | Gotas colorimétricas | Ciclado; después diagnóstico puntual | **Disponible**; **06/2029** | ~8 € | Suficiente para seguir la desaparición de nitrito y comprobar cero operativo. |
| Hanna HI764 | Fotómetro marino ULR | Diagnóstico de trazas cuando exista una razón concreta | Pendiente | ~71 € | Aporta sensibilidad y lectura digital, pero no una decisión distinta al cierre del ciclado de Veril. |
| Hanna HI97115 Marine Master | Fotómetro multiparámetro con reactivos | Programa amplio de análisis | Pendiente | ~485 € sin IVA | Centraliza esta lectura con otros tests; no elimina reactivos ni la necesidad de interpretar el contexto. |

### [Nitrato (NO3)](../../01_verilpedia/03_parametros/nitrato.md)

| Alternativa | Tipo | Cuándo | Estado / caducidad | Precio aprox. | Mejora real frente a la opción anterior |
| --- | --- | --- | --- | --- | --- |
| [Salifert Nitrate Profi Test](../../01_verilpedia/05_productos/15_salifert-nitrate/salifert-nitrate.md) | Gotas colorimétricas | Final del ciclado, maduración y control rutinario | Pendiente | ~10 € | Opción inicial razonable para una cadencia baja. |
| Hanna HI782 | Fotómetro marino, rango alto 0,0–75,0 ppm | Si se ajustan nutrientes o se quieren comparar series semanales | Pendiente | ~71 € | Convierte tonos en tendencias numéricas repetibles; es la mejora útil si NO3 se convierte en parámetro de ajuste frecuente. |
| Hanna HI97115 Marine Master | Fotómetro multiparámetro con reactivos | Programa amplio de análisis | Pendiente | ~485 € sin IVA | Integra los rangos bajo y alto de nitrato con otros análisis; sigue requiriendo reactivo. |

### [Fosfato (PO4)](../../01_verilpedia/03_parametros/fosfato.md)

| Alternativa | Tipo | Cuándo | Estado / caducidad | Precio aprox. | Mejora real frente a la opción anterior |
| --- | --- | --- | --- | --- | --- |
| [Salifert Phosphate Profi Test](../../01_verilpedia/05_productos/16_salifert-phosphate/salifert-phosphate.md) | Gotas colorimétricas | Orientación inicial y comprobaciones poco frecuentes | Pendiente | ~13 € | Referencia económica, pero la lectura visual es limitada en concentraciones bajas. |
| [Hanna HI774](../../01_verilpedia/05_productos/21_hanna-hi774/hanna-hi774.md) | Fotómetro marino ULR, 0,00–0,90 ppm | Maduración y control de nutrientes antes de modificar alimentación o adsorbentes | Pendiente | ~71 € | **La mejora Hanna prioritaria:** resuelve con más repetibilidad el rango bajo de PO4 donde la carta de color aporta poca discriminación. |
| Hanna HI97115 Marine Master | Fotómetro multiparámetro con reactivos | Programa amplio de análisis | Pendiente | ~485 € sin IVA | Añade los demás análisis; para PO4 no ofrece una razón clara para sustituir al HI774 aislado. |

### [Alcalinidad / KH](../../01_verilpedia/03_parametros/alcalinidad.md)

| Alternativa | Tipo | Cuándo | Estado / caducidad | Precio aprox. | Mejora real frente a la opción anterior |
| --- | --- | --- | --- | --- | --- |
| [Salifert KH/Alk Profi Test](../../01_verilpedia/05_productos/17_salifert-kh-alk/salifert-kh-alk.md) | Titulación | **Antes de ciclar**, durante el ciclado y con corales | Candidato pendiente de compra | ~9 € | Método de partida con resolución útil y coste bajo. |
| Hanna HI772 | Fotómetro marino, 0,0–20,0 dKH | Si se mide con mucha frecuencia, hay consumo o dosificación | Pendiente | ~71 € | Acelera series y mejora comparabilidad; no es necesario mientras Salifert cubra una rutina poco frecuente. |
| Hanna HI97115 Marine Master | Fotómetro multiparámetro con reactivos | Programa amplio de análisis | Pendiente | ~485 € sin IVA | Añade química de nutrientes y elementos; no sustituye la disciplina de medir antes de dosificar. |

### [pH](../../01_verilpedia/03_parametros/ph.md)

| Alternativa | Tipo | Cuándo | Estado / caducidad | Precio aprox. | Mejora real frente a la opción anterior |
| --- | --- | --- | --- | --- | --- |
| [Salifert pH Profi Test](../../01_verilpedia/05_productos/18_salifert-ph/salifert-ph.md) | Gotas colorimétricas | **Antes de ciclar** e investigación de oscilaciones | Candidato pendiente de compra | ~8 € | Línea base suficiente para una comprobación puntual, con pasos aproximados de 0,2 pH. |
| Hanna HI780 | Fotómetro marino, 6,3–8,6 pH | Si se quiere eliminar la lectura visual en muestras puntuales | Pendiente | ~71 € | Da número digital, pero su resolución 0,1 y precisión declarada ±0,2 pH no cambian materialmente el uso inicial. |
| Hanna HI981520-02 | Monitor de pH, salinidad y temperatura | Seguimiento continuo que justifique calibración y mantenimiento | Pendiente | ~355 € | Aporta evolución temporal de las tres magnitudes; no mide nutrientes ni alcalinidad. |
| Hanna HI98194 | Multiparámetro con pH, ORP, CE, TDS, salinidad, OD y temperatura | Diagnóstico profesional o validación avanzada de agua | Pendiente | ~1.850 € sin IVA | Suma oxígeno disuelto y medidas electroquímicas; es sobredimensionado para Veril hoy. |
| Hanna HI97115 Marine Master | Fotómetro multiparámetro con reactivos | Programa amplio de análisis | Pendiente | ~485 € sin IVA | Agrupa pH y siete análisis químicos, pero no registra pH continuamente. |

### [Calcio (Ca)](../../01_verilpedia/03_parametros/calcio.md)

| Alternativa | Tipo | Cuándo | Estado / caducidad | Precio aprox. | Mejora real frente a la opción anterior |
| --- | --- | --- | --- | --- | --- |
| [Salifert Calcium Profi Test](../../01_verilpedia/05_productos/19_salifert-calcium/salifert-calcium.md) | Titulación | Antes de dosificar y con consumo calcificador | Pendiente | ~15 € | Suficiente para la frecuencia baja prevista inicialmente. |
| Hanna HI758 | Fotómetro marino, 200–600 ppm | Series frecuentes o necesidad de reducir el punto final visual | Pendiente | ~71 € | Resultado numérico repetible, pero aún exige técnica cuidadosa y reactivos; retorno limitado al principio. |
| Hanna HI97115 Marine Master | Fotómetro multiparámetro con reactivos | Programa amplio de análisis | Pendiente | ~485 € sin IVA | Centraliza calcio con KH/Mg/nutrientes; no es una mejora proporcional para la cadencia inicial. |

### [Magnesio (Mg)](../../01_verilpedia/03_parametros/magnesio.md)

| Alternativa | Tipo | Cuándo | Estado / caducidad | Precio aprox. | Mejora real frente a la opción anterior |
| --- | --- | --- | --- | --- | --- |
| [Salifert Magnesium Profi Test](../../01_verilpedia/05_productos/20_salifert-magnesium/salifert-magnesium.md) | Titulación | Antes de dosificar y con consumo calcificador sostenido | Pendiente | ~15 € | Opción razonable porque Mg suele variar lentamente. |
| Hanna HI783 | Fotómetro marino | Si se requiere mayor cadencia o seguimiento numérico continuo | Pendiente | ~80 € | Reduce subjetividad, pero el valor práctico es pequeño mientras no haya consumo rápido. |
| Hanna HI97115 Marine Master | Fotómetro multiparámetro con reactivos | Programa amplio de análisis | Pendiente | ~485 € sin IVA | Añade siete magnitudes, sin evitar consumibles ni confirmar una desviación aislada. |

### [Salinidad](../../01_verilpedia/03_parametros/salinidad.md)

| Alternativa | Tipo | Cuándo | Estado / caducidad | Precio aprox. | Mejora real frente a la opción anterior |
| --- | --- | --- | --- | --- | --- |
| D-D The Aquarium Solution AQPR001 | Refractómetro óptico para agua marina | Antes, durante y después del ciclado; al preparar o corregir agua | **Disponible**; sin caducidad de reactivo registrada | Precio histórico no registrado | Método específico disponible; requiere limpieza, estabilización térmica, cero y contraste. |
| Hanna HI98319 | Medidor digital específico de salinidad | Si se busca una lectura numérica portátil adicional | Pendiente | ~95–120 € | Evita la lectura de la línea óptica y da PSU/ppt/SG, pero su precisión declarada de SG no elimina la necesidad de contrastar el instrumento ni justifica sustituir el refractómetro disponible. |
| Milwaukee MA887 | Refractómetro digital óptico | Solo si se necesita un segundo método óptico digital | Pendiente | ~150–220 € | Digitaliza la lectura y cubre salinidad/PSU/SG; no aporta una medición continua ni una mejora proporcional sobre un refractómetro bien contrastado. |
| Hanna HI981520-02 | Monitor de pH, salinidad y temperatura | Solo si se justifica un registro continuo con mantenimiento de sondas | Pendiente | ~355 € | Añade tendencia temporal y pH/temperatura; no sustituye por sí solo una comprobación independiente. |
| Hanna HI98194 | Multiparámetro profesional | Diagnóstico avanzado; incluye CE, TDS, OD y temperatura | Pendiente | ~1.850 € sin IVA | Añade contexto físico y oxígeno disuelto, pero no KH, nitrógeno ni nutrientes. No es prioritario. |

### [Temperatura](../../01_verilpedia/03_parametros/temperatura.md)

| Alternativa | Tipo | Cuándo | Estado / caducidad | Precio aprox. | Mejora real frente a la opción anterior |
| --- | --- | --- | --- | --- | --- |
| Sonda `off-sns-05` | Telemetría | Siempre; contrastar antes de una corrección química relevante | **Disponible**; sin caducidad | Precio histórico no registrado | Permite seguir la evolución, pero una lectura aislada no es prueba metrológica. |
| Hanna HI981520-02 | Monitor pH/salinidad/temperatura | Seguimiento conjunto continuo | Pendiente | ~355 € | Integra tres series que ayudan a explicar cambios; introduce calibración y mantenimiento. |
| Hanna HI98194 | Multiparámetro profesional | Diagnóstico avanzado | Pendiente | ~1.850 € sin IVA | Añade temperatura junto a OD y electroquímica; no resulta proporcionado para una única temperatura. |

### [PAR / PPFD e iluminación](../../01_verilpedia/01_dimensiones/04_iluminacion.md)

| Alternativa | Tipo | Cuándo | Estado / caducidad | Precio aprox. | Mejora real frente a la opción anterior |
| --- | --- | --- | --- | --- | --- |
| DanoPlus DP-414 | Medidor cuántico subacuático | Al crear o revisar el mapa de luz; antes de zonificar corales | **Disponible** según confirmación del usuario; sin reactivo ni caducidad | Precio histórico no registrado | Permite construir un mapa espacial repetible de PPFD. La unidad principal no se sumerge y la exactitud absoluta sigue pendiente de contraste. |
| Apogee MQ-510 | Medidor cuántico subacuático de referencia | Solo si es necesario validar el sesgo de la unidad DanoPlus | Pendiente | ~550–700 € | Mayor confianza para contrastar exactitud absoluta. No mide pH, salinidad ni química; tampoco sustituye un protocolo de posiciones repetibles. |

### Sistemas electrónicos con cobertura múltiple

Estas alternativas no desplazan automáticamente las opciones anteriores. Se
incluyen para decidir con qué coste y mantenimiento se compraría comodidad,
repetibilidad o telemetría, no para asumir que una marca “digital” es más
precisa en cualquier magnitud.

| Sistema | Magnitudes declaradas | Cuándo tendría sentido | Estado / precio aprox. | Mejora real y límite |
| --- | --- | --- | --- | --- |
| Seneye Reef | Temperatura, NH3 libre, pH, nivel y lecturas ópticas de luz | Aviso temprano continuo si se acepta su consumible periódico | Pendiente; ~170 € + `slide` mensual (~9 €) | Añade tendencia y alerta de NH3 libre. No sustituye los tests de NO2, NO3, PO4, KH, Ca o Mg ni un mapa de PPFD con el DanoPlus. |
| Hanna HI97115 Marine Master | pH, KH, NH3, NO2, NO3, PO4, Ca y Mg mediante reactivos | Programa manual frecuente y concentrado en un solo fotómetro | Pendiente; ~485 € sin IVA | Reduce instrumentos y subjetividad en varias lecturas, pero conserva cubetas, reactivos y preparación de cada muestra; no es una sonda continua. |
| Neptune Trident + Trident NP | KH, Ca y Mg; junto a NP, NO3 y PO4 | Solo con una estrategia de automatización basada en Apex y consumo suficiente | Pendiente; ~1.400–2.000 € incluyendo controlador y ambos analizadores, sin reactivos | Automatiza tendencias y puede detectar consumo. Requiere un Apex A2/A3, reactivos, mantenimiento y validación frente a un método independiente. |
| Focustronic Alkatronic | KH | Si KH se mide a alta cadencia y guía una dosificación | Pendiente; ~600–900 € + reactivo y tubo | Automatiza la serie de KH; no cubre Ca, Mg, nutrientes ni pH. |
| Focustronic Mastertronic Essentials | KH, Ca, Mg, NO3, PO4 y otros parámetros declarados por su configuración | Automatización avanzada que justifique coste y consumibles | Pendiente; ~1.600 € + reactivos | Reúne una rutina amplia sin Apex, pero sigue siendo un sistema con reactivos y mantenimiento; no sustituye investigar una desviación ni un ICP. |

## Análisis ICP de laboratorio

La explicación del método, sus límites y las precauciones de muestreo están en
[Análisis ICP de agua marina](../../01_verilpedia/06_procesos/10_analisis-icp.md).
Aquí se decide su empleo concreto en Veril. El ICP será un contraste elemental
por etapas: no reemplaza los criterios de NH3/NH4 y NO2 del ciclado ni convierte
un resultado de laboratorio en una corrección automática.

### Catálogo localizado en Elite Reef Kanarias

La siguiente es una fotografía del resultado de búsqueda `ICP` comunicada por
el usuario el **20 de septiembre de 2026**. Disponibilidad, condiciones de
envío y contenido exacto del kit deben verificarse de nuevo al comprar; los
precios son los publicados por la tienda y no incluyen implícitamente el envío
de la muestra al laboratorio.

La comparación siguiente recoge solo parámetros que el laboratorio declara de
forma concreta. «No declarado» no prueba que el analito esté ausente del
informe: significa que no se ha encontrado una especificación suficiente para
usarlo como criterio de compra. Los precios son los de Elite Reef Kanarias y
la descripción técnica procede de cada laboratorio.

| Kit localizado | Muestra de acuario / RO | Método declarado | Cobertura que importa a Veril | Ausencias o límite decisivo |
| --- | --- | --- | --- | --- |
| ATI ICP-OES Pro Analysis — 34,90 € | 3 viales de acuario + 1 de RO | ICP-OES, cromatografía iónica y titulación | Salinidad, KH, NO3, P/PO4, F, macroelementos, 18 trazas, 9 contaminantes y control RO. | No declara pH ni NO2. Las trazas quedan en límites de detección OES medios; no incorpora el barrido ultra-traza ICP-MS de ATI Ultimate. |
| Fauna Marin Reef ICP M — 2 tests, 37,00 € | 2 análisis básicos de acuario; sin muestra RO declarada | ICP-OES | 37 valores: macro/halógenos, P/PO4 total, silicio, trazas y contaminantes. | No declara salinidad, KH, NO3, NO2, pH ni RO/DI. Es composición elemental, no un análisis de nutrientes completo. |
| Fauna Marin Reef ICP L 3+1 — fuera de stock, 69,00 € | 4 análisis básicos de acuario; sin muestra RO declarada | ICP-OES | El mismo panel básico de 37 valores repetido cuatro veces. | Misma cobertura y límites que M; solo cambia la cantidad. La denominación pertenece al catálogo anterior de Fauna Marin y debe verificarse por EAN/lote al volver a estar disponible. |
| AquaForest MarinLab ICP Analysis Test Kit + ROwater2 — 45,00 € | 1 muestra de acuario + 1 de RO; 2 viales | ICP-OES | 39 valores: salinidad, KH, NO3, P/PO4, 8 macro/halógenos, 26 trazas/contaminantes y RO. | No declara pH, NO2, cloruro, fluoruro ni carbono orgánico. |
| Modern Reef ICP Reef Water Analysis Pro Dúo — 42,00 € | El título de Elite comunica 1 Reef Pro + 1 RO/DI Pro | ICP-OES, cromatografía iónica y otros métodos no detallados | Salinidad, KH, NO3, P/PO4, F, Cl, elementos principales, trazas y contaminantes; añade MRNU y PARL declarados por Modern Reef. | No declara pH, NO2 ni carbono orgánico. Afirma 52 parámetros, pero su listado público nombra 48: quedan 4 sin identificar. El alcance de la muestra RO/DI no está detallado por Modern Reef en la fuente recuperada. |

### Valores declarados por cada análisis

#### ATI ICP-OES Pro Analysis

ATI declara cuatro viales: **tres de agua del acuario y uno de RO**. Combina
ICP-OES, cromatografía iónica y titulación. Los valores declarados son:

- Salinidad.
- KH o alcalinidad, por titulación.
- Nitrato y fluoruro, por cromatografía iónica.
- Fósforo/fosfato, por ICP-OES.
- Elementos principales: sodio, calcio, cloruro, magnesio, azufre, potasio,
  bromo, estroncio y boro.
- Trazas OES: arsénico, bario, berilio, cromo, cobalto, hierro, yodo, cobre,
  litio, manganeso, molibdeno, níquel, selenio, plata, silicio, vanadio, zinc y
  estaño.
- Contaminantes OES: aluminio, antimonio, bismuto, cadmio, lantano, talio,
  titanio, wolframio y mercurio.
- Análisis ICP-OES del agua de RO.

No declara pH, nitrito, carbono orgánico total/disuelto, oxígeno, amonio ni las
trazas ultra-bajas que ATI reserva para Ultimate MS. Es el único kit disponible
en Elite que declara explícitamente métodos distintos para KH y NO3 y que
explica su protocolo de tres viales del acuario más uno de RO.

#### Fauna Marin Reef ICP básico: M y L

La documentación de Fauna Marin correspondiente a la nomenclatura que aparece
en Elite identifica **M como dos análisis** y **L 3+1 como cuatro análisis**.
Ambos son repeticiones del mismo **Reef ICP básico**, no el paquete *Reef ICP
Total*. Declara 37 valores:

- Macroelementos y halógenos: sodio, azufre, potasio, boro, magnesio, calcio,
  estroncio, yodo y bromo.
- Nutrientes/minerales: fósforo, fosfato total calculado y silicio.
- Trazas relevantes: zinc, vanadio, cobre, níquel, manganeso, molibdeno,
  hierro, cromo y cobalto.
- Otras trazas y contaminantes: litio, bario, aluminio, antimonio, estaño,
  berilio, selenio, plata, wolframio, lantano, titanio, circonio, arsénico,
  cadmio, mercurio y plomo.

No se debe confundir con **Fauna Marin Reef ICP Total**, que el laboratorio
presenta como un análisis diferente de más de 90 valores, con conductividad,
densidad, salinidad, pH, KH, CO2, nitrito, nitrato, fosfato orto y otros. Ese
producto no aparece en la búsqueda de Elite Reef Kanarias y no se presupone
incluido en M ni L. Las muestras RO/DI tampoco están declaradas para los sets
básicos M/L.

#### AquaForest ICP Test 2, vendido por Elite como MarinLab + ROwater2

AquaForest declara **dos viales, uno de acuario y otro de RO**, un código y
una envoltura de envío. El panel declarado contiene 39 valores:

- Salinidad, KH y NO3.
- Fósforo y PO4.
- Elementos mayoritarios/halógenos: sodio, calcio, magnesio, potasio, bromo,
  boro, estroncio y azufre.
- Trazas y contaminantes: litio, silicio, yodo, bario, molibdeno, níquel,
  manganeso, berilio, cromo, cobalto, hierro, vanadio, zinc, mercurio, selenio,
  cadmio, estaño, antimonio, arsénico, aluminio, plomo, titanio, cobre,
  lantano, escandio y wolframio.

No declara pH, nitrito, amonio, carbono orgánico, cloruro ni fluoruro. La ficha
enumera los 39 resultados del análisis, pero no separa qué analitos se
informan en la muestra de RO; se comprobará el informe/instrucción vigente
antes de basar una decisión en esa cobertura concreta.
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

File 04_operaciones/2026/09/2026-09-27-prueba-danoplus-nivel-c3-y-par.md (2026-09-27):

# 2026-09-27 — Prueba del DanoPlus, PAR ambiental y nivel de C3

## Estado

Operación documentada a partir de mediciones comunicadas por el propietario.
Los valores PAR son lecturas manuales del DanoPlus. Los volúmenes, tasas y DLI
son cálculos aproximados con las hipótesis expresadas abajo.

## Preparación comunicada

El propietario probó el medidor DanoPlus **S/N A26121206** y midió la luz
ambiental en varios puntos del tanque antes de disponer de una **AI Prime
16HD**. La luminaria todavía no está en Veril, por lo que estas lecturas no
comparan su aporte con el de la iluminación ambiental. El propietario confirmó
que el medidor se calibró esa misma mañana, antes de las medidas, siguiendo el
manual.

La ficha del [DanoPlus DP-414](../../../01_verilpedia/04_hardware/danoplus-dp-414/danoplus-dp-414.md)
describe el procedimiento del fabricante como calibración de punto cero al
cubrir por completo el sensor. La calibración comunicada no implica una
comparación de exactitud con un medidor patrón ni una aceptación metrológica de
la unidad de Veril. No se anotaron la hora de calibración, repeticiones de
control ni fuente externa de referencia.

## Lecturas PAR comunicadas

Las horas se conservan tal como se comunicaron; se interpretan como hora local
de Canarias. Los puntos corresponden a la cima, terraza, roca baja y arena del
hardscape. Unidad: **µmol fotones·m⁻²·s⁻¹ (PAR)**.

| Hora | Cima | Terraza | Roca baja | Arena |
| --- | ---: | ---: | ---: | ---: |
| 09:00 | 0,6 | 0,4 | 0,4 | 0,4 |
| 11:30 | 5,6 | 5,0 | 4,0 | 3,3 |
| 13:55 | 7,0 | 6,3 | 5,0 | 3,6 |
| 16:30 | 2,5 | 2,0 | 1,5 | 0,9 |

La AI Prime 16HD aún no está disponible ni instalada en Veril. La luz superior
de la habitación estaba encendida, condición que el propietario indica que se
da en aproximadamente el 90 % de las ocasiones durante ese tramo. El
propietario considera insignificante su aportación, aunque no se midió por
separado. No hubo medición simultánea en el exterior. Por ello, los datos
representan PAR ambiental combinado en los puntos del tanque antes de instalar
la Prime; no son una medición aislada de luz solar.

## Estimación del DLI ambiental

Como estimación exploratoria se integraron las cuatro lecturas de luz ambiental
combinada mediante interpolación lineal por tramos. Para cerrar el cálculo se
supuso PAR cero al amanecer y al ocaso, usando la ventana solar **07:55–19:55**
indicada en la conversación y no contrastada en este registro. No se midió el
PAR antes de las 09:00 ni después de las 16:30; por tanto, esos extremos son
una simplificación del cálculo y no una observación de que la luz combinada
fuera cero. El método trapezoidal da:

| Zona | DLI aproximado |
| --- | ---: |
| Cima | 0,14 mol fotones·m⁻²·día⁻¹ |
| Terraza | 0,13 mol fotones·m⁻²·día⁻¹ |
| Roca baja | 0,10 mol fotones·m⁻²·día⁻¹ |
| Arena | 0,07 mol fotones·m⁻²·día⁻¹ |

No son integrales medidas de forma continua. Dependen de la interpolación, de
la extrapolación simplificada a cero en los extremos y de que no hubiera
máximos relevantes entre las cuatro tandas. Incluyen la luz superior de la
habitación, cuya contribución el propietario considera insignificante pero no
se cuantificó. Describen únicamente la luz ambiental combinada de este día y
no constituyen una integral diaria observada, curva solar aislada, curva
estacional ni objetivo de iluminación.

El máximo comunicado fue **7,0 PAR** en la cima a las 13:55. Como referencia
aritmética, 100 PAR durante 8 horas equivaldrían a un DLI de 2,88 mol
fotones·m⁻²·día⁻¹; el DLI exploratorio de la cima sería alrededor del 5 % de
ese ejemplo. La comparación es ilustrativa y no representa una lectura real de
la Prime ni prescribe potencia, altura o fotoperiodo.

## Nivel de agua y estimación de pérdida

El propietario midió el nivel de C3 a **16 cm (160 mm) del borde superior**.
Como referencia, después de la reposición del 26 de septiembre la lectura
comunicada para C3 había quedado a **117 mm del borde**. La diferencia entre
las cotas es, por tanto, **43 mm**, suponiendo que se usó la misma arista y el
mismo punto de referencia.

La huella interior documentada para Retorno/C3 es aproximadamente **139 × 77
mm**, con un área de 10.703 mm². Aplicando esa área completa al descenso de
nivel:

```text
10.703 mm² × 43 mm = 460.229 mm³ ≈ 0,46 L
```

Esto equivale geométricamente a unos **0,46 L por cada 24 horas**. Si el
intervalo real hubiera sido de unas 23 horas, la tasa normalizada sería de
aproximadamente **0,48 L/día**. No se registró la hora exacta de la medición de
hoy, por lo que se conserva como orden de magnitud, no como una tasa precisa.

El cálculo usa toda la sección de la cámara y no descuenta la bomba, sensores u
otros objetos sumergidos. Tampoco se registraron posibles salpicaduras,
retiradas, fugas, transferencias o reposiciones entre ambas cotas. En
consecuencia, se documenta como **descenso aparente compatible con pérdida por
evaporación**, bajo la hipótesis de que no hubo otros cambios de agua, y no
como una medición directa del volumen evaporado.

La lectura de 117 mm del 26 de septiembre se tomó después de añadir unos 1,85
L de agua del barril, identificada entonces como agua salada. Esa condición es
parte del contexto de la cota de referencia y no se interpreta como una
reposición de evaporación con RO/DI.

## Interpretación y límites

- En esta serie de luz ambiental combinada el PAR fue bajo y descendió desde el máximo de las 13:55 hasta las 16:30. Cuatro tandas no descartan picos entre lecturas ni describen otros días.
- La medición ambiental previa a disponer de la Prime no permite fijar por sí sola una potencia, altura o programación para la iluminación artificial.
- La calibración de cero indicada por el manual no prueba exactitud espectral ni comparabilidad con un Apogee u otro patrón.
- La estimación de 0,46–0,48 L/día depende de intervalo aproximado, geometría idealizada y ausencia de otras entradas o salidas; no es telemetría ni una medida de volumen recogido.
- La lectura aislada de nivel no permite calcular el consumo medio estacional ni dimensionar por sí sola un depósito de reposición.

El registro del 26 de septiembre indica que no se había identificado una
entidad de Home Assistant que mida el nivel de C3. No se volvió a consultar
Home Assistant para esta operación. Se conservan las lecturas manuales; no se
aportó telemetría ambiental pertinente para las horas de lectura PAR.

## Pendientes derivados

- [ ] Registrar la hora exacta y el mismo punto de referencia en futuras medidas de C3
- [ ] Repetir lecturas PAR en los mismos puntos y condiciones si se quiere comparar otro día o evaluar otra estación
- [ ] Registrar posición, profundidad y orientación del sensor para comparar las lecturas PAR con un mapa posterior de la AI Prime 16HD
- [ ] Comparar el DanoPlus con un instrumento subacuático de referencia si se necesita evaluar exactitud absoluta

## Fuentes internas

- [DanoPlus DP-414: especificaciones, calibración de cero y límites](../../../01_verilpedia/04_hardware/danoplus-dp-414/danoplus-dp-414.md)
- [Técnica de la urna: dimensiones de C3/Retorno](../../../01_verilpedia/04_hardware/urna/tecnica.md)
- [Reposición manual y lectura de salinidad del 26 de septiembre](2026-09-26-reposicion-manual-y-lectura-de-salinidad.md)
- [Operación del 23 de septiembre: estimación geométrica de Retorno](2026-09-23-pesaje-y-desplazamiento-del-hardscape.md)
- [Configuración de iluminación de Veril](../../../02_configuracion/01_dimensiones/04_iluminacion.md)

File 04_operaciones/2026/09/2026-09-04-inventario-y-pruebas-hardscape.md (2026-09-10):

# 2026-09-04 — Inventario y pruebas del hardscape

## Estado

Operación ejecutada con comprobaciones pendientes

## Objetivo

Inventariar las rocas disponibles, construir una referencia a escala del display y probar composiciones antes de instalar el hardscape en la urna.

## Ejecución

- Se documentaron diez piezas mediante cuatro vistas fotográficas por pieza
- Se utilizó una plantilla de cartón con las medidas interiores del display y referencias de seguridad y composición
- Se probaron al menos dos composiciones en seco antes de elegir la disposición que se instalaría al día siguiente

## Resultado

- Quedó disponible un inventario visual con identificadores `Roca 01` a `Roca 10`
- La plantilla permitió evaluar la huella, la altura, los márgenes, los pasos y el espacio negativo
- Las composiciones de prueba quedaron como antecedentes y no como configuraciones vigentes

## Evidencias

- [Inventario fotográfico de rocas](../../../02_configuracion/02_hardscape/rocas/README.md)
- [Plantilla del display](../../../02_configuracion/02_hardscape/plantilla/README.md)
- Las composiciones descartadas no forman parte de la evidencia conservada en este repositorio; esta operación acredita únicamente las pruebas y el inventario descritos aquí

## Pendientes derivados

- [x] Instalar la composición elegida dentro de la urna
- [ ] Confirmar las identificaciones si alguna pieza se desmonta o cambia de orientación
- [ ] Medir los márgenes reales y validar la estabilidad y la circulación con agua

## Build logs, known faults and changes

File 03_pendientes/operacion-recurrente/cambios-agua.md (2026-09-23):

# Cambios de agua de Veril

## Propósito

Este documento define el procedimiento específico de Veril para preparar, comprobar, registrar y utilizar el agua de cambio. La explicación general de qué es un cambio de agua, qué puede aportar y cuáles son sus límites pertenece a la [ficha general de cambios de agua](../../01_verilpedia/06_procesos/06_cambios-agua.md).

La composición declarada y los límites del producto pertenecen a la [ficha de Aquaforest Reef Salt](../../01_verilpedia/05_productos/02_aquaforest-reef-salt/aquaforest-reef-salt.md). La interpretación de cada parámetro pertenece a las [fichas de parámetros](../../01_verilpedia/03_parametros/README.md). Este documento concreta cómo se utilizará esa información en Veril, sin duplicar sus definiciones generales.

## Decisiones adoptadas

- Preparar el agua nueva con agua RO/DI y [Aquaforest Reef Salt](../../01_verilpedia/05_productos/02_aquaforest-reef-salt/aquaforest-reef-salt.md)
- Tomar como referencia un cambio nominal de **10 L** y preparar el agua nueva para `S_P = 35`; la base de cálculo y la masa inicial de sal se detallan en «Base nominal para cambios y sal»
- Utilizar exclusivamente agua RO/DI sin sal para reponer la evaporación mediante el [ATO seleccionado](../../01_verilpedia/04_hardware/dd-h2ocean-compact-ato/dd-h2ocean-compact-ato.md)
- Registrar el lote de sal, la preparación y las mediciones asociadas a cada cambio
- No utilizar un cambio de agua como sustituto de identificar una fuente, un consumo anómalo, una precipitación o un problema de procesamiento

## Decisiones pendientes

- Frecuencia o condición que desencadenará un cambio
- Momento y parámetros de la medición posterior en el acuario
- Límites que obligarán a aplazar, repetir o modificar una preparación
- Diferencia máxima admisible de temperatura y salinidad entre el agua nueva y Veril
- Criterio de preparación del agua nueva cuando la salinidad real de Veril difiera del objetivo `S_P = 35`
- Criterio operativo de aceptación del agua RO/DI

## Base nominal para cambios y sal

La convención simplificada vigente de Veril es **75 L para el sistema completo** y **60 L para el display**. El cambio nominal será de **10 L**, aproximadamente el 13,3 % del sistema completo. Si en una ocasión se decide expresar un cambio como porcentaje, el cálculo será:

```text
Volumen del cambio (L) = 75 L × porcentaje / 100
```

Si el cálculo se refiere solo al display, se utilizarán sus **60 L** nominales. La frecuencia o el motivo que desencadenará el cambio sigue pendiente y no se fija aquí.

Aquaforest publica **390 g por 10 L** como cantidad inicial aproximada para **33 ppt** y pide medir la salinidad resultante ([instrucciones oficiales](https://aquaforest.eu/en/products/seawater/marine-salts/reef-salt/)). Para **35 ppt** se han encontrado dos referencias de usuarios a **415 g por 10 L**: un usuario informa que su envase lo indica para 35 ppt ([Ultimate Reef, 7 de junio de 2025](https://www.ultimatereef.net/threads/aqua-forest-reef-salt-measurements.939220/)); otro declara que pesó 415 g en 10 L de RO/DI y obtuvo 35 ppt con un refractómetro calibrado ([Reef2Reef, 12 de febrero de 2025](https://www.reef2reef.com/threads/aquaforest-reef-salt-mixing-low-alkalinity.1096824/)). Son referencias de usuarios y no una especificación oficial verificada para todos los lotes. Como punto de partida nominal para los 10 L de Veril se adopta **aproximadamente 415 g**, sujeto a comprobación y ajuste por medición.

El cálculo de sal corresponde únicamente a los **10 L de agua nueva**, no a todo el sistema de 75 L. Los 415 g son un punto de partida: se medirán la salinidad y la temperatura después de disolver, y se ajustará gradualmente hasta `S_P = 35`. La lectura medida prevalece sobre las referencias publicadas. Tras preparar una primera mezcla, la masa realmente necesaria para ese lote y ese método podrá sustituir la estimación en las preparaciones posteriores.

## Preparación del agua nueva

La preparación seguirá la [ficha del producto](../../01_verilpedia/05_productos/02_aquaforest-reef-salt/aquaforest-reef-salt.md) y conservará la trazabilidad de la mezcla:

1. Identificar el lote de Aquaforest Reef Salt y comprobar el estado seco del producto
2. Medir el volumen real de agua RO/DI utilizado
3. Llevar el agua de partida aproximadamente a **24 °C**, como referencia de preparación del fabricante, y registrar su temperatura
4. Registrar la masa de sal añadida
5. Añadir la masa inicial definida en «Base nominal para cambios y sal» —o la referencia validada para ese lote— y mezclar con una bomba o movimiento suficiente
6. Mantener la mezcla durante al menos **15 minutos**, tiempo de disolución publicado por Aquaforest
7. Comprobar la claridad y medir la salinidad con un instrumento calibrado para agua marina; ajustar gradualmente con RO/DI o con salmuera preparada por separado hasta `S_P = 35`, homogeneizando y midiendo de nuevo tras cada ajuste
8. Igualar la temperatura con el acuario antes del uso y medir los parámetros adicionales definidos para esa fase o tipo de cambio
9. Registrar las mediciones y cualquier ajuste realizado

Los aproximadamente **24 °C** corresponden a la referencia de preparación del fabricante; antes del uso, el agua debe alcanzar la diferencia de temperatura que se establezca como admisible para Veril. Los 15 minutos son un mínimo de mezcla, no un criterio de aceptación: antes de incorporar el agua se deben verificar salinidad, temperatura y claridad. La salinidad medida prevalece sobre cualquier masa inicial; humedad, lote, volumen real, temperatura e instrumento pueden influir en el resultado.

Aquaforest indica que el agua preparada debe utilizarse dentro de los tres días posteriores a la disolución. Si no se utiliza inmediatamente, se almacenará en un recipiente limpio y cerrado para limitar la evaporación; antes del uso se repetirá la comprobación de salinidad, temperatura y estado visual.

Si la salinidad es demasiado alta, se corregirá con RO/DI. Si es demasiado baja, se corregirá añadiendo progresivamente una preparación salina de concentración conocida preparada por separado, evitando incorporar sal seca directamente al agua ya destinada al cambio. Esto reduce el riesgo de disolución incompleta y de concentraciones locales elevadas. Después de cada ajuste se homogeneizará completamente y se volverá a medir.

No se corregirá una preparación basándose únicamente en gramos por litro, gravedad específica nominal o apariencia del agua.

## Parámetros del agua preparada

Como mínimo, cada preparación deberá conservar:

- Salinidad y unidad o escala utilizada
- Temperatura de la muestra
- Método, instrumento y calibración
- Lote de la sal
- Estado o criterio de aceptación del agua RO/DI
- Volumen inicial de agua RO/DI
- Volumen final de agua preparada disponible
- Masa de sal utilizada

Cuando forme parte del control del sistema RO/DI, se conservará también la conductividad o el TDS de salida correspondiente. La frecuencia, el método y los límites pertenecen a la documentación específica del sistema RO/DI.

Cuando el cambio pueda afectar a la interpretación química del sistema, se registrarán también los parámetros relevantes de la [química de Veril](../../02_configuracion/01_dimensiones/05_quimica.md), especialmente alcalinidad, calcio y magnesio. El pH, el oxígeno, los nutrientes u otros parámetros se incorporarán cuando el motivo del cambio o la fase del sistema lo requieran.

La medición del agua nueva permite conocer su composición observada, pero no demuestra por sí sola la composición completa de la sal ni sustituye un análisis de laboratorio o de lote.

La alcalinidad, el calcio, el magnesio y otros parámetros se medirán para caracterizar un lote nuevo o investigar resultados inesperados, no necesariamente en cada preparación. Los controles mínimos de aceptación se describen en «Preparación del agua nueva».

## Ejecución del cambio

Antes de retirar agua se registrarán:

- Fecha y hora
- Volumen previsto y volumen realmente retirado
- Salinidad y temperatura del acuario
- Parámetros que motiven o condicionen el cambio
- Alimentación, dosificación, mantenimiento o incidencias recientes

Antes de iniciar la retirada:

- Desactivar temporalmente el [ATO seleccionado](../../01_verilpedia/04_hardware/dd-h2ocean-compact-ato/dd-h2ocean-compact-ato.md) para que no interprete el descenso de nivel como evaporación
- Detener los equipos que puedan aspirar aire, funcionar en seco o quedar fuera de su nivel operativo
- Mantener o detener la circulación interna según el procedimiento del cambio y las condiciones de seguridad de cada equipo

Durante la operación:

- Retirar el volumen previsto evitando mezclarlo de nuevo con el agua de reposición
- Incorporar el agua nueva de forma controlada y compatible con la circulación del sistema
- Evitar introducir agua con una diferencia no evaluada de temperatura o salinidad
- Registrar cualquier interrupción, derrame, salpicadura o cambio respecto al volumen previsto

Después de incorporar el volumen previsto:

- Restablecer el nivel operativo normal del sistema
- Reiniciar los equipos detenidos y comprobar que el retorno y las demás bombas funcionen correctamente, sin aspirar aire ni operar fuera de sus condiciones previstas
- Reactivar el ATO únicamente cuando el volumen salado ya haya sido restituido y el nivel de la cámara de retorno sea estable
- Confirmar finalmente que los niveles de las cámaras han recuperado su estado operativo

No se añadirá sal seca directamente al acuario con animales. La salinidad del sistema no se corregirá mediante una estimación visual del nivel o una compensación improvisada del volumen retirado.

## Refuerzo del biofiltro con FritzZyme 9

Fritz menciona los cambios de agua, la incorporación de nuevos peces, la limpieza agresiva, la medicación y el cambio de material filtrante entre las situaciones en que puede reforzarse el biofiltro con FritzZyme 9. No prescribe una repetición automática después de cada cambio de agua: indica utilizarlo cuando se necesite reforzar el biofiltro y vigilar amoniaco y nitrito para valorar nuevas dosis.

En Veril, un cambio de agua rutinario por sí solo **no será motivo para dosificar FritzZyme 9**. Tras introducir peces u otra fauna que aumente la carga biológica, se vigilarán amoniaco y nitrito; se reservará el producto para una necesidad concreta de refuerzo del biofiltro. La misma condición se aplicará después de una intervención que pueda reducir significativamente la población bacteriana. Durante el ciclado sin peces prevalecen las dosis y el procedimiento del [plan de ciclado](../ciclado/plan.md).

Para un sistema establecido, Fritz publica **30 ml por cada 19 L**. El cálculo se hace sobre el volumen total del sistema, no solo sobre los 10 L cambiados ni sobre el volumen de animales incorporados. Con la base nominal de **75 L**, corresponde a **aproximadamente 118 ml por aplicación**. Si se actualiza el volumen operativo, se recalculará proporcionalmente.

Fritz indica mantener apagados el skimmer y los esterilizadores UV durante al menos **cinco días** después de la aplicación y mantener flujo o aireación adecuados. Como esta condición interrumpe el funcionamiento normal del skimmer de Veril, no se dosificará preventivamente: solo se valorará una aplicación si existe una necesidad concreta de refuerzo y se puede cumplir el periodo de apagado de forma segura. Si no es viable, se mantendrá la vigilancia de amoniaco y nitrito y no se usará el producto. La dosis, las condiciones y los límites del producto se detallan en la [ficha de FritzZyme 9](../../01_verilpedia/05_productos/09_fritzzyme-9/fritzzyme-9.md).

## Comprobación posterior

Después de que el sistema haya recuperado una mezcla representativa, se comprobarán los parámetros definidos para el tipo de cambio. El momento exacto de esta comprobación deberá quedar fijado en el procedimiento operativo cuando se establezcan los criterios de seguimiento.

La comparación deberá distinguir entre:

- El efecto de dilución o sustitución producido por el volumen cambiado
- La composición del agua nueva
- El consumo, la precipitación o la producción ocurridos durante el intervalo
- Los cambios de temperatura, salinidad o circulación que alteren la medición

Una modificación observada después del cambio no se atribuirá automáticamente a la sal sin comparar el agua nueva, el agua del sistema y las intervenciones concurrentes.

Cuando existan mediciones anteriores, del agua nueva y posteriores, se comprobará que la magnitud y la dirección del cambio sean plausibles para la fracción sustituida. Una discrepancia significativa se considerará primero como posible error de medición, volumen, mezcla o proceso concurrente antes de atribuirla al producto.

## Registro de cada cambio

| Campo | Registro |
| --- | --- |
| Fecha y hora | Pendiente de completar |
| Motivo o condición desencadenante | Pendiente de completar |
| Lote de Aquaforest Reef Salt | Pendiente de completar |
| Estado y criterio del agua RO/DI | Pendiente de completar |
| Conductividad o TDS de salida del RO/DI, si se mide | Pendiente de completar |
| Volumen inicial de RO/DI | Pendiente de completar |
| Volumen final de agua preparada disponible | Pendiente de completar |
| Masa de sal | Pendiente de completar |
| Temperatura del agua preparada | Pendiente de completar |
| Salinidad del agua preparada | Pendiente de completar |
| Método e instrumento | Pendiente de completar |
| Alcalinidad, calcio y magnesio del agua preparada, si procede | Pendiente de completar |
| Volumen retirado | Pendiente de completar |
| Volumen realmente introducido en Veril | Pendiente de completar |
| Volumen operativo utilizado para el cálculo, si procede | Pendiente de completar |
| Salinidad y temperatura del acuario antes y después | Pendiente de completar |
| Parámetros adicionales | Pendiente de completar |
| Incidencias o ajustes | Pendiente de completar |

## Límites de interpretación

- La composición nominal del producto no equivale a la composición medida de cada preparación o lote
- El agua de reposición por evaporación no debe contener sal añadida
- Los cambios de agua realizados durante ciclado o maduración deben registrarse en el plan correspondiente porque pueden alterar la interpretación de una prueba o tendencia

La interpretación general de la dilución, la sustitución y sus límites se conserva en la [ficha general de cambios de agua](../../01_verilpedia/06_procesos/06_cambios-agua.md).

## Fuentes y documentos relacionados

- [Cambios de agua en un acuario marino](../../01_verilpedia/06_procesos/06_cambios-agua.md): definición general, efectos, límites y balance simplificado de mezcla
- [Aquaforest Reef Salt](../../01_verilpedia/05_productos/02_aquaforest-reef-salt/aquaforest-reef-salt.md): composición declarada, preparación, conservación y análisis por lote
- [FritzZyme 9](../../01_verilpedia/05_productos/09_fritzzyme-9/fritzzyme-9.md): dosis, condiciones de uso y conservación del producto
- [Química de Veril](../../02_configuracion/01_dimensiones/05_quimica.md): decisión de utilizar RO/DI y Aquaforest Reef Salt
- [Fichas de parámetros](../../01_verilpedia/03_parametros/README.md): interpretación de salinidad, temperatura, alcalinidad, calcio, magnesio y demás variables
- [Plan de ciclado](../ciclado/plan.md): cambios de agua durante el establecimiento y sus efectos sobre la prueba
- [Plan de maduración](../maduracion/plan.md): cambios de agua durante la evolución inicial del sistema

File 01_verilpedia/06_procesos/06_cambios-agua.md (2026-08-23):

# Cambios de agua en un acuario marino

## Qué es

Un cambio de agua sustituye una fracción del agua del sistema por agua nueva de composición conocida o caracterizada. No es únicamente una técnica para reducir nitrato o materia disuelta: modifica simultáneamente las concentraciones, las relaciones iónicas, la carga de contaminantes y la disponibilidad de algunos componentes del agua.

La calidad de un cambio depende tanto del agua nueva como de la fracción sustituida, la homogeneización, la compatibilidad con el sistema y la capacidad de comprobar el resultado.

## Qué puede aportar

Un cambio de agua puede:

- Reducir por dilución la concentración de sustancias disueltas
- Reponer parte de componentes consumidos o retirados
- Modificar las relaciones entre parámetros cuando el agua nueva tiene una composición diferente
- Retirar una fracción de materia disuelta y partículas que se encuentren en el agua extraída
- Permitir comparar la composición del agua del sistema con la composición del agua preparada

El efecto real depende del volumen cambiado y de la composición del agua nueva. Un cambio pequeño produce una modificación limitada, mientras que uno grande puede alterar de forma apreciable la salinidad, la temperatura y la química del sistema.

## Qué no resuelve por sí solo

Un cambio de agua no elimina necesariamente la fuente de un compuesto, no demuestra que el procesamiento del sistema sea suficiente y no sustituye la identificación de consumos, producción, precipitación, adsorción o dosificación anómalos.

Tampoco garantiza que todos los parámetros estén en condiciones adecuadas. El agua nueva puede tener una salinidad correcta y, aun así, presentar diferencias relevantes de alcalinidad, calcio, magnesio, nutrientes u otras magnitudes.

La reducción observada después de un cambio no debe interpretarse automáticamente como solución permanente. Debe distinguirse entre dilución temporal, retirada efectiva y desaparición de la fuente.

## Balance simple de mezcla

Para una sustancia cuya concentración pueda tratarse aproximadamente como conservativa durante la operación, si se sustituye una fracción `f` del volumen operativo por el mismo volumen de agua nueva y no existen otros procesos relevantes durante la mezcla, puede estimarse:

```text
f = V_cambio / V_operativo
C_final ≈ (1 − f) × C_acuario + f × C_agua_nueva
```

Donde `V_cambio` es el volumen realmente sustituido y `V_operativo` es el volumen funcional del sistema. El volumen operativo no debe confundirse automáticamente con el volumen geométrico nominal de la urna.

Esta relación sirve como comprobación de plausibilidad, no como predicción exacta. No incorpora errores de volumen, muestreo o mezcla incompleta.

No debe aplicarse directamente a magnitudes no lineales o gobernadas por equilibrios que se reajustan durante la mezcla, como el pH. Tampoco debe aplicarse sin reservas a sustancias sometidas a intercambio gaseoso, precipitación, adsorción, consumo o producción significativa, como puede ocurrir con oxígeno, dióxido de carbono, nutrientes reactivos o especies químicas concretas.

## Preparación y aceptación del agua nueva

El agua nueva debe prepararse con una fuente compatible y una composición conocida o verificable. La masa de sal, el volumen de agua de partida y las instrucciones del producto pueden servir como punto de partida, pero la salinidad final debe medirse antes del uso.

Los criterios de aceptación deben distinguir entre:

- Salinidad, temperatura y otras magnitudes medidas
- Claridad o estado visual de la mezcla
- Trazabilidad del agua de partida y del producto
- Compatibilidad con el sistema que recibirá el agua

La sal seca no debe añadirse directamente a un acuario con animales. Si es necesario corregir la salinidad del agua preparada, se debe utilizar agua sin sal o una preparación salina de concentración conocida, homogeneizar y volver a medir.

El agua preparada que no se utilice inmediatamente debe conservarse de forma que se limite la evaporación y debe volver a comprobarse antes de incorporarla al sistema.

## Ejecución y seguridad

Antes de retirar agua deben considerarse el nivel operativo, la circulación, los equipos que puedan aspirar aire o funcionar en seco y cualquier sistema automático que pueda interpretar la bajada de nivel como evaporación.

La reposición debe devolver el sistema a un estado operativo estable antes de reactivar automatismos o equipos que dependan del nivel. La temperatura y la salinidad del agua nueva deben ser compatibles con el sistema, y las diferencias admisibles deben definirse según la configuración concreta.

## Interpretación posterior

Cuando existan mediciones anteriores, del agua nueva y posteriores, debe comprobarse que la magnitud y la dirección del cambio sean plausibles para la fracción sustituida. Una discrepancia significativa puede deberse a un error de medición, volumen, mezcla, muestreo o proceso concurrente antes que al producto.

La interpretación debe separar:

- El efecto de dilución o sustitución
- La composición real del agua nueva
- El consumo, la producción o la precipitación durante el intervalo
- La retirada de partículas o materia asociada al agua extraída
- Los cambios de temperatura, salinidad y circulación que afecten a la medición

La medición posterior debe realizarse cuando el sistema haya recuperado una mezcla suficientemente representativa para el objetivo de la comprobación. El momento y los parámetros concretos pertenecen al procedimiento del sistema que realiza el cambio.

## Relación con otros procesos

Los cambios de agua interactúan con:

- La química, porque modifican concentraciones y relaciones entre parámetros
- El procesamiento y la exportación, porque pueden retirar materia sin eliminar su fuente
- La hidráulica, porque la mezcla y la renovación condicionan la homogeneidad de la muestra
- La biología, porque los organismos responden a cambios de salinidad, temperatura y composición
- El mantenimiento, porque la ejecución puede retirar sedimentos y materia particulada

Estas relaciones no convierten el cambio de agua en un sustituto de las dimensiones o procesos correspondientes. Cada uno debe evaluarse mediante su documentación propia.

## Indicadores que pueden inducir a error

- Asumir que una masa fija de sal produce siempre la misma salinidad
- Utilizar el volumen nominal de la urna en lugar del volumen operativo
- Considerar que una reducción temporal de nitrato elimina su fuente
- Aplicar un balance lineal a pH o a especies químicas en equilibrio
- Medir el agua nueva sin registrar temperatura, instrumento o calibración
- Reactivar un ATO durante la retirada y alterar el volumen realmente sustituido
- Atribuir cualquier cambio posterior al producto sin comparar el agua nueva y las intervenciones concurrentes

## Fuentes y límites

Esta ficha define el proceso de forma general. No establece una frecuencia universal, un porcentaje de cambio, una sal concreta ni límites válidos para cualquier sistema. Esos valores deben documentarse en el procedimiento operativo correspondiente y justificarse mediante las características del sistema, la composición del agua nueva y las mediciones disponibles.

La ecuación de mezcla es un modelo simplificado. La respuesta real puede incluir procesos biológicos, químicos, físicos y de medición que no estén representados en ella.

## Documentos relacionados

- El procedimiento operativo correspondiente: aplicación específica del sistema que realiza el cambio
- [Fichas de parámetros](../03_parametros/README.md): interpretación de las magnitudes medidas
- [Dimensión química](../01_dimensiones/05_quimica.md): relaciones y estabilidad de la composición del agua
- [Dimensión hidráulica](../01_dimensiones/03_hidraulica.md): mezcla, renovación y distribución del agua

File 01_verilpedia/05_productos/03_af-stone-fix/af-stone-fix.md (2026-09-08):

# AF Stone Fix

## Identificación

| Campo | Dato |
| --- | --- |
| Marca | Aquaforest |
| Producto | AF Stone Fix |
| Presentación disponible | 1.500 g |
| Estado en Veril | Adquirido y utilizado en la fijación del hardscape |

## Especificaciones declaradas

| Campo | Dato |
| --- | --- |
| Tipo | Adhesivo cementoso de fraguado rápido |
| Uso declarado | Unión de elementos grandes de roca de acuario |
| Presentaciones comerciales localizadas | 250 g, 1.500 g y 6.000 g |
| Aplicación recomendada | Preferentemente fuera del acuario |

Las presentaciones comerciales proceden del catálogo del fabricante. La ficha del envase recibido prevalece si difiere en nombre, cantidad o instrucciones.

## Función documentada

Es un adhesivo cementoso de fraguado rápido destinado a unir elementos grandes de roca de acuario. La preparación, el tiempo de trabajo, el curado y las condiciones de uso deben seguir la etiqueta del envase adquirido.

Aquaforest indica que debe mezclarse una pequeña cantidad con agua hasta obtener una consistencia homogénea y utilizarse inmediatamente. El fabricante indica aproximadamente 15 minutos de espera tras unir las piezas. Puede producirse una turbidez temporal y un aumento de pH, especialmente si se fijan varias piezas dentro de un acuario con animales.

## Uso en Veril

Se ha utilizado para fijar las uniones de las rocas del hardscape durante la operación del 5 de septiembre de 2026. La aplicación queda registrada en la [operación de montaje, fijación y primer llenado](../../../04_operaciones/2026/09/2026-09-05-montaje-y-primer-llenado/README.md).

## Preparación y uso

1. Preparar las superficies y estabilizar las piezas antes de mezclarlas
2. Mezclar solo la cantidad que pueda utilizarse durante el tiempo de trabajo
3. Añadir agua hasta obtener una mezcla homogénea, según la etiqueta
4. Aplicar y unir las superficies inmediatamente
5. Mantener las piezas apoyadas durante el fraguado inicial
6. Respetar el tiempo de unión y curado indicado por el envase
7. Retirar el polvo y los residuos sueltos antes de poner el conjunto en servicio

Para una aplicación bajo el agua, Aquaforest indica apagar las bombas de circulación y el retorno. En Veril se utilizó para las uniones del hardscape; la operación concreta queda separada de esta ficha general.

## Límites y riesgos

- La fijación del producto no demuestra por sí sola la estabilidad de toda la estructura
- La cantidad visible, el curado y la resistencia real de cada unión deben comprobarse en la instalación
- No se debe introducir el sistema en una fase posterior hasta respetar las condiciones de curado indicadas por el fabricante
- La turbidez temporal no demuestra que el producto sea inocuo en cualquier cantidad o condición
- Un aumento de pH o la posible liberación de silicatos deben vigilarse si se utiliza una cantidad elevada
- No debe confundirse con AF Poly Glue ni con un cianoacrilato para fijaciones pequeñas

## Fuentes

- Etiqueta e instrucciones del envase adquirido
- [Copia local de la guía de productos Aquaforest](aquaforest-product-guide-en.pdf)
- [Aquaforest: Stone Fix y productos de aquascaping](https://aquaforest.eu/en/products_/seawater/aquascaping/)
- [Aquaforest: guía de Stone Fix](https://aquaforest.eu/en/knowledge-base-tag/af-stone-fix/)
- [Registro del hardscape](../../../02_configuracion/02_hardscape/README.md)

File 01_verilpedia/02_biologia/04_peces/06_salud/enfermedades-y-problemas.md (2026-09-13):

# Enfermedades y problemas de peces marinos

| Posibilidad | Signos compatibles | Límite diagnóstico |
| --- | --- | --- |
| *Cryptocaryon irritans* | Puntos blancos, irritación y respiración alterada | Los puntos no identifican por sí solos el parásito |
| *Amyloodinium ocellatum* | Deterioro rápido, respiración intensa, aspecto polvoriento | Puede avanzar antes de que el aspecto sea claro |
| *Brooklynella hostilis* | Mucus, irritación y deterioro respiratorio | Requiere diferenciarlo de otros cuadros branquiales |
| *Uronema* | Lesiones y deterioro en determinadas circunstancias | No atribuir toda úlcera al ciliado |
| Monogeneos | Irritación, frotamiento y respiración alterada | Los signos dependen de especie y órgano afectado |
| Infección bacteriana externa | Erosión, úlcera, enrojecimiento o deterioro | Puede ser secundaria a lesión, parásitos o mala calidad ambiental |
| Linfocistis | Nódulos o masas en piel y aletas | No confundir con hongos, mucus o lesiones mecánicas |
| Agresión y estrés | Aletas dañadas, escondite, pérdida de apetito | Puede coexistir con enfermedad |

## Prioridad diagnóstica

Observar respiración, nado, apetito, lesiones, excreciones, compañeros afectados y velocidad de deterioro. Comprobar temperatura, salinidad, oxigenación y amonio con métodos adecuados. Una lectura correcta no identifica por sí sola un parásito.

## Prevención

La prevención combina procedencia conocida, observación separada, higiene de redes y recipientes, alimentación adecuada y estabilidad ambiental. La cuarentena reduce riesgo, pero su duración por sí sola no demuestra que un pez esté libre de enfermedad.

## Tratamiento y display

El tratamiento depende del agente probable, especie, fase y estado del pez. Se realiza en un recipiente de hospital cuando el producto pueda dañar invertebrados, roca, sustrato o filtración biológica del display. No usar cobre ni otros medicamentos incompatibles con invertebrados dentro de Veril. La ficha de [cuarentena y hospital](../../../08_practicas/02_cuarentena-y-hospital.md) define el límite operativo sin prescribir dosis universales.

No se deben copiar dosis de otra especie, sistema o publicación experimental. La elección debe considerar diagnóstico, concentración medida, duración, compatibilidad, oxigenación, filtración y capacidad de medir amonio.

## Fuentes

- [UF/IFAS: gestión sanitaria de peces](https://edis.ifas.ufl.edu/publication/FA100)
- [UF/IFAS: *Cryptocaryon irritans*](https://edis.ifas.ufl.edu/publication/FA164)

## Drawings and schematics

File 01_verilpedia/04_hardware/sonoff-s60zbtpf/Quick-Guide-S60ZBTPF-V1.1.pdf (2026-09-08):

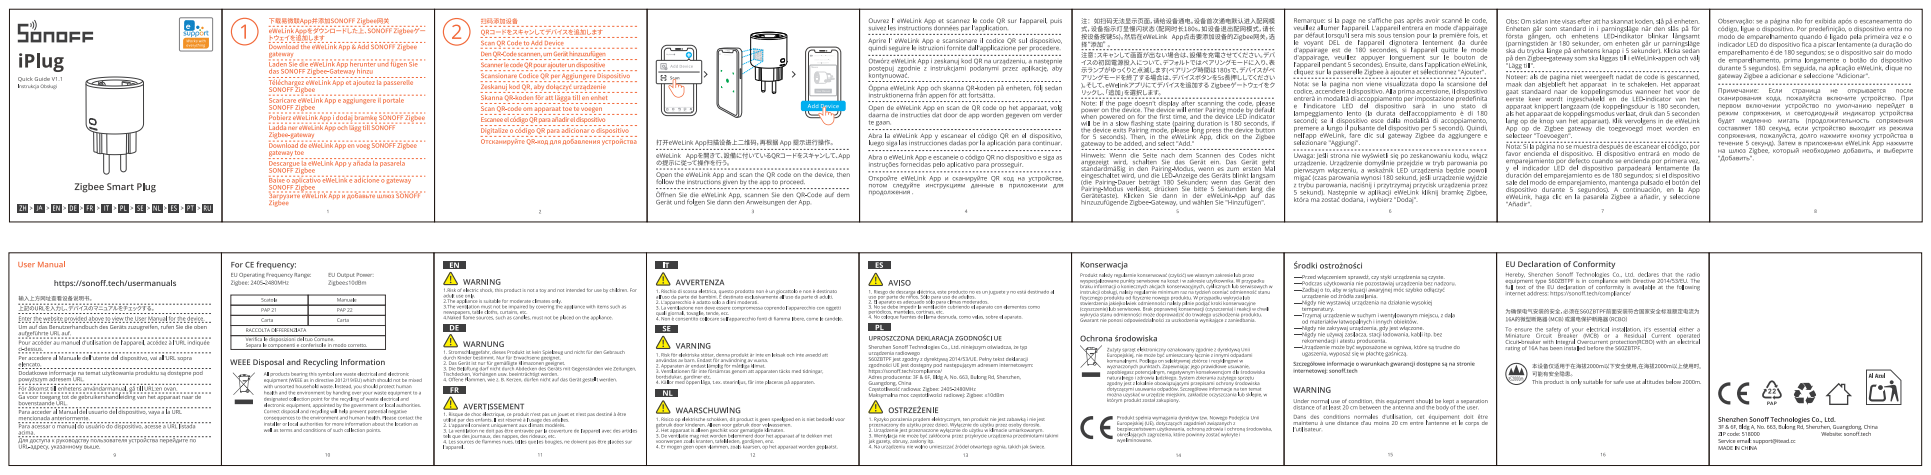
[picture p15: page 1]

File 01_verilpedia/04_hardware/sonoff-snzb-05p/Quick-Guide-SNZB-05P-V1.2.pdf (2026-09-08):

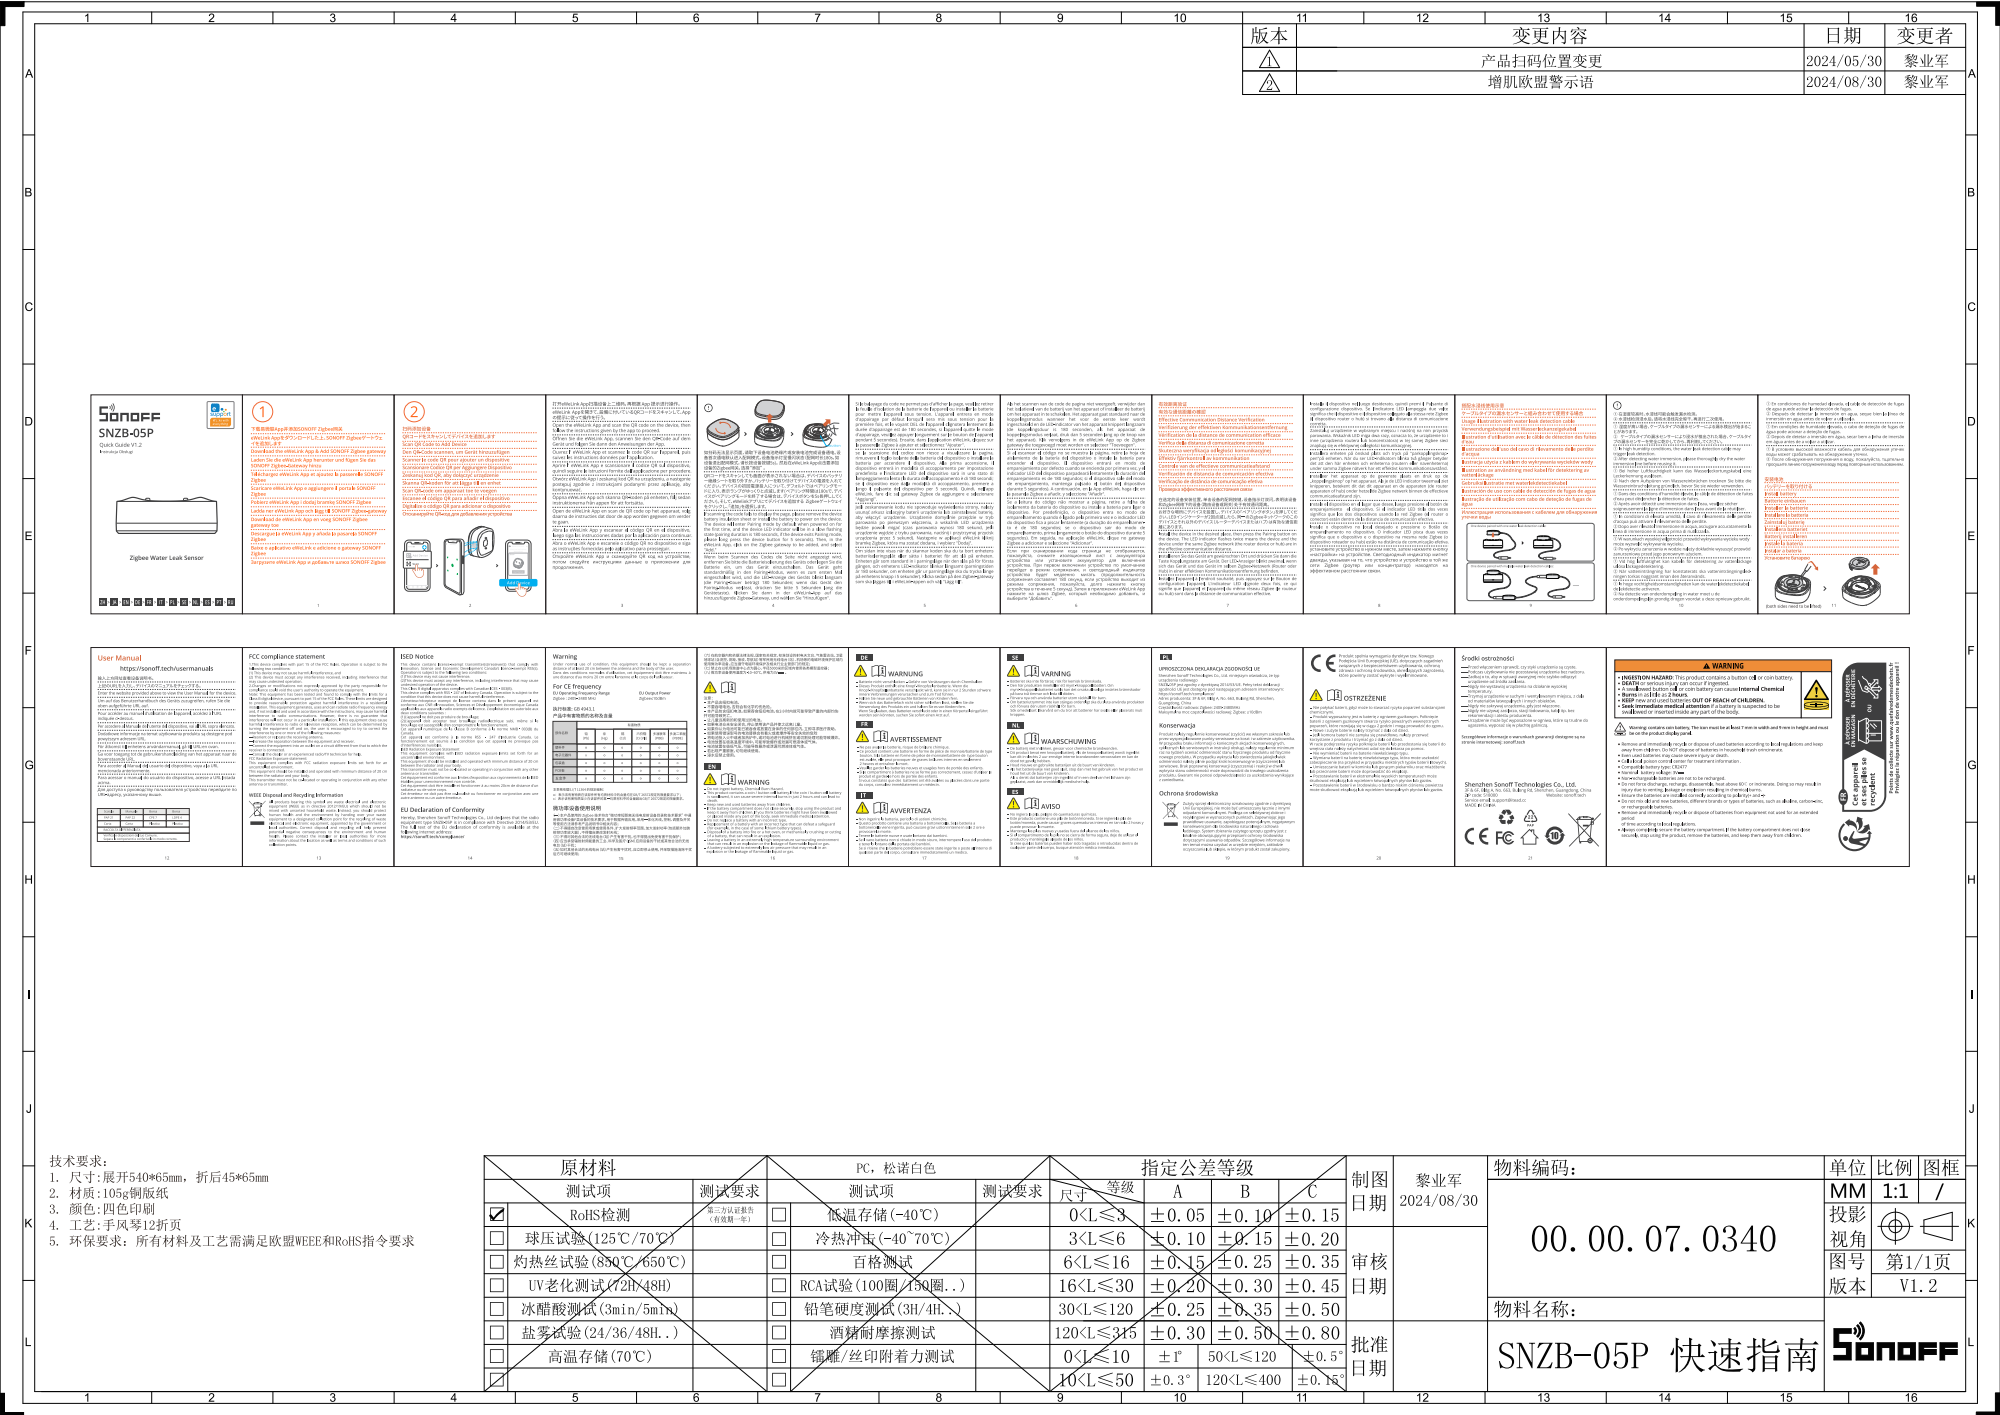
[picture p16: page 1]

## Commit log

2026-08-19 Documenta la configuración inicial de Veril
2026-08-19 Elimina la referencia de Cristaleria Drago
2026-08-19 Reescribe la documentación de la urna
2026-08-20 Actualiza proveedores privados de Elite Reef
2026-08-22 Actualiza submódulo de documentación privada
2026-08-23 Reorganiza dimensiones y documentación de Veril
2026-08-23 Consolida la implementación dimensional de Veril
2026-08-23 Ordena la documentación pública y separa operación
2026-08-23 Consolida documentación de Veril y procesos operativos
2026-08-23 Ordena la documentación y revisa los README
2026-08-24 Documenta arquitectura y plan de microfauna
2026-08-24 Simplifica la documentación del repositorio
2026-08-24 Documenta la identidad gráfica de Veril
2026-09-08 Reorganizar documentación y operaciones de Veril
2026-09-10 Reubica fuentes de ciclado y corrige referencias
2026-09-11 Documenta sistema RO/DI y configuración de cocina
2026-09-13 docs(ro-di): add system diagram
2026-09-20 docs: actualiza operación, medición e infraestructura de Veril
2026-09-21 fix: restaurar logotipo de portada
2026-09-23 Documenta operaciones y pendientes de Veril
    [veril-bactoflex-jaula--kp3-winkle-petg.3mf, veril-bactoflex-jaula.stl, veril-bactoflex-tapa--kp3-winkle-petg.3mf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]
2026-09-23 Actualizar medidas y documentación operativa de Veril
    [veril-bactoflex.FCStd]
2026-09-24 Actualizar documentación de Veril y evidencias
2026-09-26 Documentar operación y separar versiones BactoFlex
    [bactoflex-50x50x100.FCStd, veril-bactoflex-jaula--kp3-winkle-petg.3mf, veril-bactoflex-jaula.stl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]
2026-09-27 Documentar operación y planes de Veril
2026-09-29 Actualizar documentación térmica y registros de Veril
    [chaeto-box-parametrico.FCStd]
2026-10-10 Documentar compras, ciclado y diseños de octubre
2026-10-10 Actualizar plan TDS y guardar respaldos CAD
2026-10-10 Documenta compras y actualiza diseños de Veril
2026-10-10 Añade microfauna viva a lista de regalos
2026-10-10 Actualiza lista de regalos de Veril
2026-10-12 Documenta ciclado y rediseño del soporte de biobolas
2026-10-16 Publica rebosadero y pantalla AI Prime de Veril
2026-10-16 Documentar colocación de la luminaria Veril
2026-10-17 docs: añade vistas de AI Shade y rebosadero
2026-10-19 Limitar los registros de operaciones a hechos y lecturas documentados
2026-10-19 Actualizar la identificación del retorno y la configuración de equipos
2026-10-19 Fijar el espacio privado para investigaciones de Veril
2026-10-19 Simplificar y actualizar la documentación del ciclado de Veril
2026-10-19 docs: consolidar fichas, configuración y planes de Veril
2026-10-19 docs: incorporar manual, figuras y medidas de la Jebao DC-650
2026-10-19 docs: normalizar salto de línea del manual Jebao
2026-10-20 docs: conserva ediciones públicas y separa el desarrollo 3D local
2026-10-21 docs: registrar mediciones y limpieza del skimmer del 21 de octubre
2026-10-24 docs: registrar medición de NO2 y actualizar regalos
2026-10-25 docs: actualizar mediciones del ciclado y lista de regalos
2026-10-26 docs: retirar Menudos Bichos de la lista de tiendas
2026-10-26 docs: registrar test de nitrito del 26 de octubre
2026-10-28 docs: registrar medición de nitrito del 28 de octubre
2026-10-28 docs: precisar referencia de medición de nitrito
2026-10-31 docs: actualizar estado y operaciones de Veril
2026-11-01 docs: registrar medición de nitrito y temperatura
2026-11-02 docs: actualizar seguimiento del ciclado de Veril
2026-11-03 docs: registrar mediciones del ciclado del 3 de noviembre
2026-11-06 docs: registra mediciones y cambio de agua del 6 de noviembre
2026-11-06 docs: actualiza fichas de peces y mediciones de Veril
2026-11-06 docs: registra observación de roca y cristales
2026-11-09 docs: registrar mediciones del ciclado del 8 y 9 de noviembre
2026-11-10 docs: registrar mediciones del 10 de noviembre
2026-11-10 docs: registrar KH de agua preparada
